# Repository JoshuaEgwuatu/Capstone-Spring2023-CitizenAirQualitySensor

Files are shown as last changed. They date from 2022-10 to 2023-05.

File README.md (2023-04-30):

# Citizen Air Quality Sensor

## Executive Summary

&nbsp;&nbsp;&nbsp;&nbsp;&nbsp;&nbsp; The goal of this project was a replicable device that accepts and operates multiple air quality sensors independently with a selection of interchangeable sensor options for local data collection.  Air quality is vital to maintaining life on Earth.  Poor air quality can result in a slew of health problems such as heart disease and lung cancer.  In the modern age, humanity pushes the levels of pollution in the world to unprecedented levels as compared to the pre-industrial era.  This pollution affects the very air that all living things rely on to survive.  This perspective on the negative repercussions of polluting the air and Earth is what led to this team’s proposition of a device that allows everyday citizens to see what pollutants blight their communities.  
&nbsp;&nbsp;&nbsp;&nbsp;&nbsp;&nbsp; There are already services that exist to alleviate this problem, however, the services do not fulfill the solution to a high degree.  The biggest of these services would be the Air Quality Index (AQI) provided by the United States Environmental Protection Agency.  The AQI takes in data from sensors placed systematically all across the country and in highly populated areas.  This data is then aggregated together to fill in any regions that were not explicitly sampled from a sensor directly.  The issue derives from that last sentence.  Because it is not reasonable or cost-effective for these services to place sensors everywhere, the readings that are received from these sensors may not be accurate in any given place.  For a community wanting a detailed view into the air quality of their chosen area, they would require more concrete sources of data.  It is here where the team’s proposed device comes in to provide an easy-to-use, solar-powered, easily replicable, and low-cost modular system that uses multiple sensors to gather data on different pollutants.

## Capabilities

1. Data Acquisition Through USB Or Wirelessly Through The Internet
2. Modular Sensor Design
3. Optional Self-Powering Modules Using Battery/Solar
4. Dynamically update a Google Sheet with current sensor values

## Salient Outcomes

### Internet Access:

&nbsp;&nbsp;&nbsp;&nbsp;&nbsp;&nbsp;  The original plan for accessing the Internet has remained the same, however, the implementation has changed.  Utilizing 3G GSM would provide national coverage.  The development here was that all major cellular service providers have been phasing out 3G support throughout the year of 2022.  This obviously proved a great concern as the initial design of the Communication subsystem was designed with 3G in mind.  The original design did not allow for anything else.  An upgrade to 4G was necessary and called for an entirely new component.

### Modularity:

&nbsp;&nbsp;&nbsp;&nbsp;&nbsp;&nbsp;  Modularity has been a core design concept from the beginning.  The system design incorporates this philosophy in many aspects and subsystems.  A project with this level of interchangeable parts and optional configurations has never been attempted by members of the team.  The team is eager to see this project flourish and see numerous options covering a wide range of locations and uses.

### Citizen Science 

&nbsp;&nbsp;&nbsp;&nbsp;&nbsp;&nbsp;  Dr. Austen has presented an admirable goal and intriguing future for this project.  His vision has a future where this proposed device is improved by numerous teams and utilized in small communities to spread awareness of air quality concerns and the health risks that can arise from poor conditions.  People and companies use this design as foundation for their own projects.  This team is happy to pursue this vision and see it fulfilled.

## Project Photos and Video

### Original Box Exterior
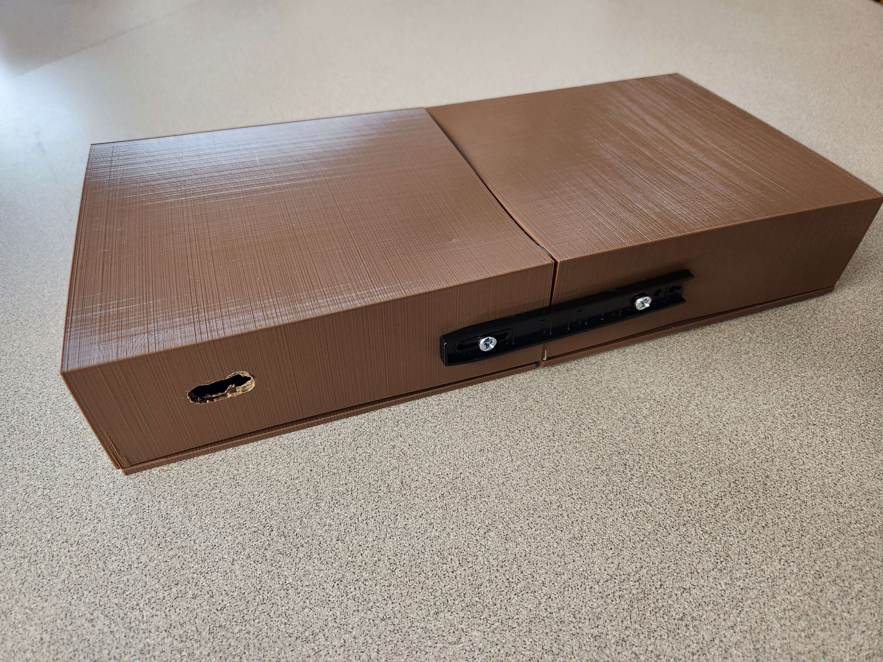
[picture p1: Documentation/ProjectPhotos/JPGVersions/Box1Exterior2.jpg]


### New Box Exterior
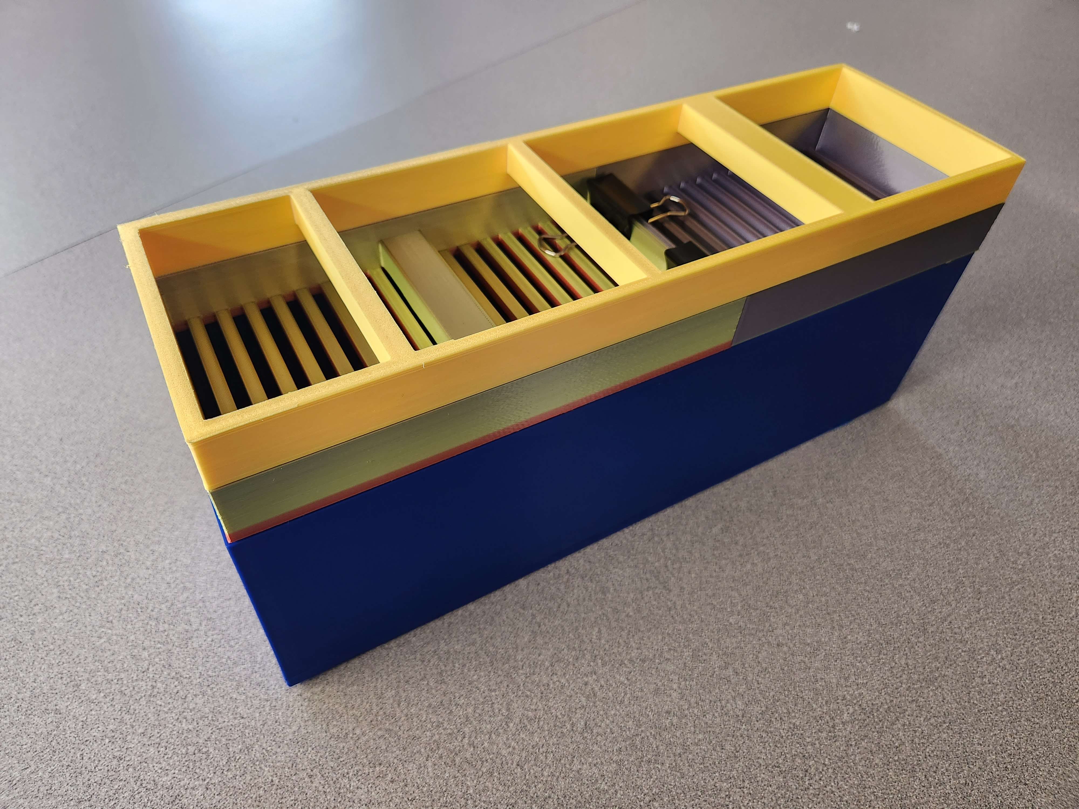
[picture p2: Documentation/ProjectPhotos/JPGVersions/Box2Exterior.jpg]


### Device In Operation Video
[Click Here To Go To YouTube Demonstration](https://youtu.be/Z7YvJpOqsXQ)

## About Us

### Team

&nbsp;&nbsp;&nbsp;&nbsp;&nbsp;&nbsp; All of the members on the team have studied over various circuits and how to implement them to do what the developer wants it to.  Members include: 
Cameron Smith is a computer engineer who is heading the communication subsystem
Kaleb Irwin is an electrical engineer who is designing the power subystem
Alejandro Moore is an electrical engineer in charge of the sensor subystem
Marvo Odds is an electrical engineer managing interfacing between components and sensors
Joshua Egwuatu is an electrical engineer leading the web subsystem.  

### Faculty Supervisor
The supervisor and customer for this project is Dr. Jeffrey Austin.  He is overseeing the design process made by the team and also providing the end-goal desires of the device.

### Stakeholders
The customer for this product is also the same person, Dr. Jeffrey Austin. Another stakeholder within this course is our professor, Mr. Jessie Roberts. The team will be in contact with both professors as we proceed within the design.

## Repo Organization

### Reports
The reports will consist of a Project Proposal, Conceptual Design, Minimal Functionality, Project Poster, and Presentations. Proposal and Design cover analysis and contraints of the system.

### Documentation
Signoffs, Schematics, 3D Models, Images/Photos, and Final Bill of Materials.  Signoffs cover analysis and contraints of individual subsystems.

### Software
The Pseudo Code and other Software components for the project will be placed in Software. Each code directory contains a README that details a description, functions of the code, dependences, and how to install.

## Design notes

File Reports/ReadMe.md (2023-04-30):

This directory will contain the final version of each of the following:
1. [The Project Proposal Original](https://github.com/JoshuaEgwuatu/Capstone-Spring2023-CitizenAirQualitySensor/blob/main/Reports/Project%20Proposal%20Draft%200.pdf)
2. [The Project Proposal Revised](https://github.com/JoshuaEgwuatu/Capstone-Spring2023-CitizenAirQualitySensor/blob/main/Reports/Project%20Proposal%20Revisions.pdf)
3. [Conceptual Design and Planning](https://github.com/JoshuaEgwuatu/Capstone-Spring2023-CitizenAirQualitySensor/blob/main/Reports/Conceptual%20Design%20and%20Planning.pdf)
4. [Project Poster](https://github.com/JoshuaEgwuatu/Capstone-Spring2023-CitizenAirQualitySensor/blob/main/Reports/CT1_Citizen_Air_Quality_Sensor_Poster_S23_V3.pdf)
5. [Minimal Functionality](https://github.com/JoshuaEgwuatu/Capstone-Spring2023-CitizenAirQualitySensor/blob/main/Reports/Minimal%20Functionality%20(1).pdf)
6. [IAB Presentation](https://github.com/JoshuaEgwuatu/Capstone-Spring2023-CitizenAirQualitySensor/blob/main/Reports/Presentations/IAB-Capstone-Team-1-Presentation.pdf)
7. [All Presentations](https://github.com/JoshuaEgwuatu/Capstone-Spring2023-CitizenAirQualitySensor/tree/main/Reports/Presentations)

Final Report may be considered the entirety of this GitHub repository, so a singular document may not be representative of the Final Report

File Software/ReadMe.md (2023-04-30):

This software directory will contain all the code and software utilized.

FinalIteration represents the final version of the code that was able to be tested and prove completely functional.

Each folder will contain the following:

1. What the software does
2. Libraries/Dependecies used (Arduino IDE is a default if not stated otherwise)
3. How to Install

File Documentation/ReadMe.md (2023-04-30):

This folder will contain copies of the final versions of the signoffs.  These signoffs represent the approved designs and purchases made for the overall design.

This folder will also contain general images used throughout various documentation of the project.  The images folder acts as a hoard of all the images.  This includes the project poster and photos of the device under construction and completion.

Any wiring and electrical schematics will be available in the electrical folder in this directory.  Here, there will be PCB and Schematic sections for each component and subsystem.

A final version of the Bill of Materials is included.  This file details all components purchased for constructing the final product.

3D Models contains the most up-to-date version of the enclosure in an STL file.

All signoffs detailing the contraints and analysis for this device's subsystems are available inside this documentation folder.  These signoffs also include small electrical diagrams for constructing the subsystem.

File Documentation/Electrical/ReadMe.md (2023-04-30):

Any wiring and electrical schematics will be available in the electrical folder in this directory. Here, there are Schematic sections for Microcontroller, Sensor, and Interface.  
Communication is just a UART connected to the Arduino.  Check signoff for more detail.
Power subsystem is just a power connection to one of the modular options. Check signoff for more detail.

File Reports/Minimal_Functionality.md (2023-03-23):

# Minimal Functionality
### Capstone Team 1 Members
* Joshua Egwuatu - Web & Wireless
* Kaleb Irwin - Power
* Cameron Smith - Communication
* Alejandro Moore - Sensor
* Marvo Odds - Interface

## POWER
1. Operate using battery power
2. Operate using AC mains power
3. Supply 5 V to the Arduino through a USB input.
4. Supply appropriate voltages to sensors.

## SAMPLING AND INTERFACING SENSORS
1. The sensor will transfer the measured data to the microcontroller via the interface.
2. Sample at a minimum of 2 Hz.

## MICROCONTROLLER
1. Store data onto a USB flash drive.
2. Receive analog voltage, analog current, and digital data from the interface.
3. Send data to the Communication subsystem.

## COMMUNICATION
1. Receive data from the Microcontroller, format the data, and send the data through the use of
Wi-fi to be displayed on a terminal.

## WEB AND WIRELESS
1. Receive data from the device and have a simple display in a numeric form

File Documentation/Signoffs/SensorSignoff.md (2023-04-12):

# Sensor Subsystem Signoff
## FUNCTION OF THE SUBSYSTEM
&nbsp;&nbsp;&nbsp;&nbsp;&nbsp;&nbsp; The Sensor Subsystem will be designed to give various data to the Microcontroller Subsystem through the Interface Subsystem. As data acquisition starts, the output of each analog sensor goes through the Interface for voltage/current regulation to the microcontroller.

&nbsp;&nbsp;&nbsp;&nbsp;&nbsp;&nbsp; Within this Sensor Subsystem, the design team has decided to get multiple types of sensors for the modularity of the device. These types are digital, analog voltage, and analog current sensors. While the digital sensors send bits describing the measurement of a specific parameter, the analog sensors send their signals a bit differently. Analog sensors output analog signals which are different to measure from bits, therefore the Interface Subsystem will provide assistance in parameter conversion to the microcontroller.

## CONSTRAINTS ON THE SUBSYSTEM
&nbsp;&nbsp;&nbsp;&nbsp;&nbsp;&nbsp; Constraints on the subsystem are as follows:

1. The pollutants of the Air Quality Device shall be able to detect carbon dioxide, methane, nitrogen dioxide, ozone, particulate matter, and sulfur dioxide. These sensors should work independently from each other.

Each sensor shall meet the requirements of either Constraint 2 or 3.

2. Shall be modular. Specifically, the change of sensors should be seamless and handled by the board and software. The sensors will have a variety of Input/Output (I/O) ports. For a sensor to be in the same group, it must share the same voltage supply, current consumption, and communication technique through the interface. The sensor shall meet either of the following output ranges [9]:

&nbsp;&nbsp;&nbsp;&nbsp;&nbsp;&nbsp; ● Output the signal at the range of 0 - 10 VDC for analog voltage.

&nbsp;&nbsp;&nbsp;&nbsp;&nbsp;&nbsp; ● Output 4 - 20 mA for analog current.

3. Each sensor must be able to communicate with the microcontroller using a communicative language. The sensors shall communicate through Serial Peripheral Interface (SPI), Universal Asynchronous Receiver-Transmitter (UART), or Inter-Integrated Circuit (I2C). The microcontroller for this design will also be able to communicate with those same data transfer techniques. 

4. For windy environments, the sampling rate should be at most 10 Hz. This is because there are environmental factors that can cause a loss of accuracy in the data given higher wind speeds or non preferable weather conditions. After viewing this experiment of wind analysis in Thailand, it can be shown that using the Nyquist sampling theorem and varied wind speed, one can find the appropriate sampling rate at higher wind speed conditions without losing as much accuracy. They observed the wind speed data and used Fourier Transform to locate a cutoff frequency for the Nyquist sample rate. From their calculations, they have also concluded 10 Hz to be a suitable sample rate for higher wind conditions [1]. For indoor monitoring, ambient gas sensors will be sampled at the lowest rate of 2 Hz per second based on the diffusion of ambient air quality [3].

5. The input voltages from the Power Subsystem will provide either 3 or 5 +/- 0.1 V DC. Therefore, each sensor that will be used for the device shall have input voltages of either value. From looking at multiple gas sensors for this project, the maximum worst case for wattage in this subsystem is 375 mW. Maximum current consumption for each sensor is 75 mA.

6. For every sensor that is plugged onto the Air Quality Device initially, there may be a start up time for initial calibration. According to a study in Tokyo, most portable gas sensors have a start-up time of 30s [10]. After a survey observing the full start-up time range, the sensors selected within the analysis section have a max time of 1 hour. Therefore, all sensors shall have a wait/warm-up time less than 2 hours before data acquisition.

7. According to the ANSI/ASHRAE Standard 62.1-2016: Ventilation for Acceptable Indoor Air Quality [2], indoor CO2 concentrations no greater than 700 parts per million (ppm) above outdoor CO2 concentrations will satisfy a substantial majority (about 80%) of occupants. Sensors used for this device shall comply with their pollutant concentration with this standard for indoor/outdoor use. The NAAQS has revised measurement standards for the main pollutants in America. The ranges are as follows [14]:

&nbsp;&nbsp;&nbsp;&nbsp;&nbsp;&nbsp; ● PM 10 - 150 - 350 μg/m3 (micrograms per cubic meter of air. Resolution not found

&nbsp;&nbsp;&nbsp;&nbsp;&nbsp;&nbsp; ● PM 2.5 - From 12 - 200 μg/m3. Resolution not found

&nbsp;&nbsp;&nbsp;&nbsp;&nbsp;&nbsp; ● NO2 - From 53 - 100 ppb (parts per billion). Resolution not found

&nbsp;&nbsp;&nbsp;&nbsp;&nbsp;&nbsp; ● O3 - From 0.07 - 0.115 ppm. Resolution not found

&nbsp;&nbsp;&nbsp;&nbsp;&nbsp;&nbsp; ● SO2 - From 0.5 - 2 ppm. 1 ppb Resolution.

&nbsp;&nbsp;&nbsp;&nbsp;&nbsp;&nbsp; ● CH4 (Methane) - From 2 - 90 ppm [15]. Resolution not found

## BUILDABLES OF THE SUBSYSTEM

CAPSTONE II Sensor Subsystem
&nbsp;&nbsp;&nbsp;&nbsp;&nbsp;&nbsp; &nbsp;&nbsp;&nbsp;&nbsp;&nbsp;&nbsp; &nbsp;&nbsp;&nbsp;&nbsp;&nbsp;&nbsp; &nbsp;&nbsp;&nbsp;&nbsp;&nbsp;&nbsp; &nbsp;&nbsp;&nbsp;&nbsp;&nbsp;&nbsp; &nbsp;&nbsp;&nbsp;&nbsp;&nbsp;&nbsp; &nbsp;&nbsp;&nbsp;&nbsp;&nbsp;&nbsp; &nbsp;&nbsp;&nbsp;&nbsp;&nbsp;&nbsp; &nbsp;&nbsp;&nbsp;&nbsp;&nbsp;&nbsp; Figure 1. Sensor Subsystem through Interface Schematic

Screenshot (229)

&nbsp;&nbsp;&nbsp;&nbsp;&nbsp;&nbsp; &nbsp;&nbsp;&nbsp;&nbsp;&nbsp;&nbsp; &nbsp;&nbsp;&nbsp;&nbsp;&nbsp;&nbsp; &nbsp;&nbsp;&nbsp;&nbsp;&nbsp;&nbsp; &nbsp;&nbsp;&nbsp;&nbsp;&nbsp;&nbsp; &nbsp;&nbsp;&nbsp;&nbsp;&nbsp;&nbsp; &nbsp;&nbsp;&nbsp;&nbsp;&nbsp;&nbsp; &nbsp;&nbsp;&nbsp;&nbsp;&nbsp;&nbsp; &nbsp;&nbsp;&nbsp;&nbsp;&nbsp;&nbsp; Figure 2. Sample code for the MIKROE-2767

Screenshot (231)

&nbsp;&nbsp;&nbsp;&nbsp;&nbsp;&nbsp; &nbsp;&nbsp;&nbsp;&nbsp;&nbsp;&nbsp; &nbsp;&nbsp;&nbsp;&nbsp;&nbsp;&nbsp; &nbsp;&nbsp;&nbsp;&nbsp;&nbsp;&nbsp; &nbsp;&nbsp;&nbsp;&nbsp;&nbsp;&nbsp; &nbsp;&nbsp;&nbsp;&nbsp;&nbsp;&nbsp; &nbsp;&nbsp;&nbsp;&nbsp;&nbsp;&nbsp; &nbsp;&nbsp;&nbsp;&nbsp;&nbsp;&nbsp; &nbsp;&nbsp;&nbsp;&nbsp;&nbsp;&nbsp; Figure 3. Sample Code for the A02P43B7001

## ANALYSIS OF THE SUBSYSTEM

&nbsp;&nbsp;&nbsp;&nbsp;&nbsp;&nbsp; The team has chosen 3 sensors for testing that matches with the constraints list. We wanted each to be a different type of sensor output to test modularity and implement the necessary actions required within the software to model the functionality of both the Microcontroller, Interface, and Sensor Subsystems. All sensors chosen for experimentation are for detecting one of the 6 pollutants that the proposal has stated for data input.

### OZONE SENSOR (ANALOG VOLTAGE)

#### Analysis of the MIKROE-2767 [4]:

1.& 7.-The MIKROE-2767 Ozone (O3) Gas Sensor is a quarter-sized PCB mounted with a MQ131 detector that has high sensitivity depending on the potentiometer. This sensor is able to detect the pollutant anywhere from 10‐1000 Part-Per-Million (ppm). Resolution not stated within the data sheet.

2.& 5.-The MIKROE-2767 has an input voltage range of 3.3V - 5V therefore, this particular sensor can be powered by both voltage supply options. Based on the Schematic (Schematic Reference!), the current computation is in the range of 5 uA - 33 uA.

4.-Not Applicable.

6.-Not Applicable.

Other - The UART source code can be seen in the Buildables of the Subsystem section within the document. (See Figure 2.)

### SULFUR DIOXIDE SENSOR (ANALOG CURRENT)

#### Analysis of the ULPSM-IAQ 968-008 [6] with the A02P43B7001 [5]:

1.-The A02P43B7001 gas detector is able to detect Sulfur Dioxide (SO2) which is within the list of pollutants to be acquired.

2.-The ULPSM-IAQ 968-008 below the detector contains a nice feature of having the ability to switch the gas detectors for other pollutants as well. This can allow the user to replace the SO2 sensor with another pollutant detector, or a different type of gas detector for more convenience and modularity.

4.-Not Applicable.

5.-The ULPSM-IAQ 968-008 will be connected using header pins under the A02P43B7001, which will communicate with the Microcontroller. The ULPSM-IAQ 968-008 calls for a supply voltage of around 3.3V. The power consumption is on average 30 uW. Also, the corresponding current consumption is 10uA on average.

5.-The A02P43B7001 will operate at the same voltage supply of 3.3V with an LED indicator telling the user that the sensor is operating in the ON position. During this time, the SO2 sensor has a max operating current of 1.17 mA and a max power consumption of 3.7 mW.

6.-Not Applicable.

7.-The analog current detector has a measurement range of 0 - 5 ppm. Having a wide range will give the user a range of accuracy and levels of precise calculations.  Resolution found to be 0.15 ppm for the ULPSM-IAQ 968-008. The A02P43B7001 states in the datasheet a resolution of 1 ppb.

Other - A method sample code for the SO2 detector to communicate with the Master device can be seen within the Buildables of the Subsystem section. (See Figure 3.)

### CARBON DIOXIDE SENSOR (DIGITAL)

#### Analysis of the DGS-CO 968-034 [7]:

1.-The DGS-CO is a digital carbon monoxide detector that has a similar modular feature as the analog current gas sensor. This means we can switch detectors for experimentation on whether the components meet our specifications.

3.-The connections are configured by the PCB to communicate using UART as well.

4.-Not Applicable.

5.-The supply voltage is available for a 3.3V supply with a power gumption range of 0.15 - 12 mW. The current consumption also has a range of 0.05 mA - 4 mA. Values for the power, voltage, and current requirements depend on the operating periodic functions of this device.

6.-Not Applicable.

7.-This Digital sensor has a range of 0 -1,000 ppm. The DGS-CO has a resolution of 0.1 ppm.

### METHANE SENSOR (ANALOG VOLTAGE)

#### Analysis of the MIKROE-1628 [11]:

1.-The MIKROE-1628 is able to detect methane within its location.

2.& 5.-It can be supplied with a max voltage of 5V, a max current consumption of 33 uA, outputting at a range of 0 - 5 V.

4.& 6.-After a warm up time of 1 hour, it can start sampling at a rate of 2Hz.

7.-Has a measurement rage of 200 - 10000 ppm. Resolution was not found within the datasheet.

### NITROGEN DIOXIDE SENSOR (DIGITAL)

#### Analysis of the SEN0377 [12]:

1.-The SEN0377 can detect various type of gasses, but for this device it shall be used to detect NO2.

3.-The sensor shall communicate using I2C for the microcontroller.

4.& 6.-Start up time is less than 1 hour with a sample rate of 5 Hz.

5.-This sensor has the modular compatibility to take either 3.3 or 5 V supply with a low current consumption of 11 mA. Thus having a lower power intake of .45 W. Digital output of 0 - 3 V.

7.-Measurement range of 0.05 - 10 ppm. Resolution was not found within the datasheet.

### PARTICULATE MATTER SENSOR (DIGITAL)

#### Analysis of the SPS30 [13]:

1.-This Particulate Matter (PM) Sensor can detect 4 different sizes of PM in its location.

3.-Uses both I2C and UART to communicate.

4.-Samples at a period of 1 second or 2 Hz.

5.-Supply voltage is 5V with max current intake of 75 mA. Outputs current of 0 - 16 mA.

6.-Start up time ranges from 8 - 30 seconds.

7.-Can calibrate up to ranges of 200 - 3000 ppm. Resolution not found within the datasheet.

### GPS SENSOR (DIGITAL)

&nbsp;&nbsp;&nbsp;&nbsp;&nbsp;&nbsp; Another sensor to be applied in the project is used for GPS location. The RAK1910 [8] can do this task while also corresponding to the constraints provided.

1.-Not Applicable.

3.-The GPS sensor can communicate using UART or I2C, being compatible with the microcontroller in use.

4.-Not Applicable.

5.-The RAK1910 can take 3.3V with low amperage consumption. The worst case being 22 mA.

6.-30 second cold start-up time.

7.-Not Applicable.

## BILL OF MATERIALS

|Item Name|Manufactured Part #|Quantity|Description|Price|
|---|---|---|---|-----|
|OZONE 2 CLICK|MIKROE-2767|0|Analog Voltage O3 Gas Sensor|$45.00|
|Analog Gas Sensor Module|ULPSM-IAQ 968-008|1|Analog Current Gas Sensor (Modular with Digital Sesnor)|$50.00|
|Allsensing gas sensor module|A02P43B7001|1|SO2 GAS SENSOR|$163.62|
|WisBlock GNSS Location Module|RAK1910|0|Tracks the GPS and the GLONASS signals|$17.00|
|Digital Gas Sensor Module|DGS-CO 968-034|0|Digital Gas Sesnor (Modular with Analog Current Sensor) if out of stock, 968-001 is similar option.|$50.00|
|Methane Click|MIKROE-1628|1|Multiple Function Sensor|$15.00|
|Digital Sensor Module|SEN0377|1|Multiple Function Gas Sensor|$39.90|
|Particulate Matter Sensor|SPS30|0|Particulate Matter Sensor for Air Quality Monitoring and Control|$50.50|

Note: All sensors that our team does not plan to order will have the quantity order number of 0 within the BOM. Corresponding sensors that have the quantity number of 0 will be ordered at a later date separate from the initial build.

## REFERENCES

1. “Improving Accuracy of Wind Analysis with Multiple Sampling Rates of Wind Measurement” https://www.e3s-conferences.org/articles/e3sconf/pdf/2019/21/e3sconf_icpeme2018_02002.pdf (Accessed on 3-1-23).

2. The National Institute for Occupational Safety and Health (NIOSH) “Indoor Environmental Quality” https://www.cdc.gov/niosh/topics/indoorenv/hvac.html (Accessed on 2-16-23).

3. Lion Precision “Displacement Resolution Specifications and Its Effects on Performance” https://www.lionprecision.com/understanding-sensor-resolution-specifications-and-effects-on-performance/ (Accessed on 2-23-23).

4. MIKROE-2767 Datasheet “Ozone 2 click” https://media.digikey.com/pdf/Data%20Sheets/MikroElektronika%20PDFs/MIKROE-2767_Web.pdf (Accessed on 2-13-23).

5. A02P43B7001 Datasheet https://media.digikey.com/pdf/Data%20Sheets/Allsensing%20PDFs/AGSM-SO2-5.pdf (Accessed on 2-16-23).

6. ULPSM-IAQ 968-008 Datasheet “Ultra-Low Power Analog Sensor Module for IAQ” https://www.spec-sensors.com/wp-content/uploads/2016/10/ULPSM-IAQ-968-008.pdf (Accessed on 2-16-23).

7. DGS-CO 968-034 Datasheet “Digital Gas Sensor – Carbon Monoxide” https://www.spec-sensors.com/wp-content/uploads/2017/01/DGS-CO-968-034.pdf (Accessed on 2-16-23).

8. RAK1910 WisBlock GNSS Location Module Datasheet https://docs.rakwireless.com/Product-Categories/WisBlock/RAK1910/Datasheet/#overview (Accessed on 2-17-23).

9. GasLab “Analog and Digital Gas Sensors: What’s the Difference?” https://gaslab.com/blogs/articles/what-s-difference-between-analog-digital-gas-sensors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,or%200%2D3%20volts%20DC. (Accessed on 2-20-23).

10. Stable Heating Technology for Catalytic Combustion Hydrogen Gas Sensor Using Quartz Resonators https://pdfs.semanticscholar.org/7a13/0c740245fd18929fdc9169a5f38154c9cf0e.pdf (Accessed on 2-23-23).

11. MIKROE-1628 Datasheet https://www.mouser.com/datasheet/2/272/methane-click-manual-v100-1483826.pdf (Accessed on 2-23-23).

12. SEN0377 Datasheet https://www.mouser.com/pdfDocs/ProductOverview-DFRobot-SEN0377.pdf (Accessed on 2-23-23).

13. SPS30 Datasheet https://cdn.sparkfun.com/assets/4/e/e/f/8/Sensirion_PM_Sensors_Datasheet_SPS30.pdf (Accessed on 2-23-23).

14. United States Environmental Protection Agency “NAAQS Table” https://www.epa.gov/criteria-air-pollutants/naaqs-table (Accessed on 2-26-23).

15. “A Portable Device for Methane Measurement Using a Low-Cost Semiconductor Sensor: Development, Calibration and Environmental Applications” https://www.mdpi.com/1424-8220/21/22/7456#:~:text=This%20sensor%20can%20perform%20temperature,RH%20and%20resolution%20of%200.01%25 (Accessed on 2-26-23).

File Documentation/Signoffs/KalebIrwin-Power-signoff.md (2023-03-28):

## Function of the subsystem 
The subsystem will provide the microcontroller and sensor interface with power. There will be two configurations designed which the user will be able to choose from. The first configuration will be designed to operate with input from an ac mains electrical outlet and the second configuration will be powered by a battery that is charged by a solar cell.

## Constraints 
1. *Provide a maximum power draw of 1.686 W and 0.831 W typical 
   
   a. Arduino Mega maximum power is 0.9 W taken from 5 V operation at 180 mA peak current draw with 0.375 W typical power requirements taken from 5 V 75 mA typical operation [1]
   
   b. ESP8266 maximum power draw is 0.561 W taken from 170 mA maximum required current at 3.3 V operation [2]
   Typical power draw for ESP8266 is 0.231 W taken from 3.3 V 70 mA typical operation [3]
   
   c. The largest power draw observed in evaluated sensors was 75 mW. Accoutning for three of these peak power draw sensors yeilds 225 mW.
2. Power the Ardunio Mega with 7-12 V 160 mA on the Vin pin or 5±0.25 V 200mA from the USB 2.0 standard through the USB 2.0 input on the board [4][5]
3. **Provide 45 mA at 5 V and 75 mA at 3 V for sensor interface (This supports the three peak power draw sensors)

Additional constraint on system for AC operation

 4. Function on 120 V 60 Hz AC mains input and must have UL certification 

Additional constraints on system for battery operation

5. Battery capacity greater than 39.89 Wh to allow for a minimum operational time of 48 hours on a single charge without additional power from a solar cell 
   
      Calculated with (typical power draw * minimum continuous operation time) = (0.831 W * 48 h) = 39.89 Wh 
   
 6. Must use a solar panel that is at least 4.43 W in order to recharge the batteries daily power consumption within the peak solar hours timeframe of 4.5 hours [6]. 
 
      Calculated with (typical daily power usage / average peak sun hours) = (19.94 Wh / 4.5 h) = 4.43 W

## Schematic 



## Analysis 
1. The chosen wall adapter is rated at 5 V and 2 A. Multiplying these numbers yields 10 W. The chosen battery has USB output of 5 V and 3 A. Multiplying these numbers yields 15 W both of which are greater than the worst case power draw of 1.686 W
2. Both solutions provide 5 V USB output that can power the Arduino 
3. 5V can be taken directly from the USB-A to the screw terminal on either power option and sent to the interface. It can also be connected to the input terminal on the DC-DC converter to provide the 3 V.
   
   a. The chosen DC-DC converter requires an input voltage at least 1.5 V higher than the output voltage and can input 4-40 V and output 1.5-35 V. These ranges allow for a 5 V input and a 3 V output.

4. The chosen wall adapter is rated for 100-240 V 50/60 Hz AC which covers the US electrical system and shows UL certification.
5. The chosen battery has a stated capacity of 25000 mAh and uses an internal battery voltage of 3.7 V for a power capacity of 92.5 Wh. Using this and the typical power draw of 0.831 W tells us that it will run for 111.31 hours on a single charge with no additional power from the solar cell. This is 2.319x the minimum operation time. 
6. Built in solar cell can provide 6 W during peak sun hours

   Gaining 6 W * 4.5 h = 27 Wh given 4.5 hours of peak sun which is greater than the 19.988 Wh daily usage.

## BOM
| Designator | Manufacturer | Manufactured Part # | Description | Quanitity | Price Each |
| --- | --- | --- | --- | --- | --- |
| P1 | Hiluckey | | Solar Charger 25000 mAh | 1 | $46.99 |
| P2 | ALMOCN | | DC-DC Adjustable Step-Down Module with Digital Display Voltmeter Display 2 pack | 1 | $8.99 |
| P3 | Fonken | | 5 V 2 A wall charger 3 pack | 1 | $11.99 |
| P4 | Itramax | | USB male to two female adapter | 1 | $12.99 |
| P5 | JUXINICE | | Male USB to screw terminal connector 2 pack | 1 | $8.99  
| *** | SANKABA | 000010 | 5 W USB Solar Panel for DC 5V Security Camera. | 0 | $23.99 
## Notes 
*Maximum and typical power calculations done with no low power modes or code taken into account. For actual operation these values can be lowered substainually and should be considered to lower the load on the battery. For this project we will attempt to include as many options as possible and provide data on power consumption with and without these features.

**Additional constraint placed on power subsystem if the chosen sensors exceed the Arduino Mega 50 mA current limit. If the sensors do not exceed the current limitations of the Arduino Mega and its' pins, the DC-DC converters may be ommited from the design as the sensors can use the 3.3 V and 5 V supplies on the board. 

***An additioanl solar cell can be purchased in the event that the solution presented is not suffecent for a users area. This additional panel must have micro-USB output as it will need to be pluged into the power in port of the battery.  
## Reference 
1. C. David, “Arduino mega tutorial [pinout],” DIYI0T, 07-May-2021. [Online]. Available: https://diyi0t.com/arduino-mega-tutorial/. [Accessed: 07-Feb-2023]. 
2. “ESP8266EX datasheet - espressif,” ESP8266 Datasheet. [Online]. Available: https://www.espressif.com/sites/default/files/documentation/0a-esp8266ex_datasheet_en.pdf. [Accessed: 08-Feb-2023]. 
3. C. David, “How to reduce the ESP8266 power consumption?,” DIYI0T, 07-May-2021. [Online]. Available: https://diyi0t.com/how-to-reduce-the-esp8266-power-consumption/. [Accessed: 07-Feb-2023]. 
4. T. A. Team, “MEGA 2560 REV3: Arduino documentation,” Arduino Documentation | Arduino Documentation. [Online]. Available: https://docs.arduino.cc/hardware/mega-2560. [Accessed: 07-Feb-2023]. 
5. USB-IF,“USB 2.0 specification,” USB, 08-Oct-2021. [Online]. Available: https://www.usb.org/document-library/usb-20-specification. [Accessed: 07-Feb-2023]. 
6. Unbound Solar , “Sun hours map: How many sun hours do you get?,” 09-Mar-2021. [Online]. Available: https://unboundsolar.com/solar-information/sun-hours-us-map. [Accessed: 08-Feb-2023].

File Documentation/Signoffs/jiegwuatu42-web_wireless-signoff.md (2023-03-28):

# Web and Wireless Signoff
## FUNCTION OF THE SUBSYSTEM

The Web & Wireless subsystem is responsible for receiving data from the Communication subsystem, storing data received from the Communication subsystem on a host device, formatting and encrypting the data, and displaying the data for the user on a webpage.

## CONSTRAINTS ON THE SUBSYSTEM

The subsystem constraints are placed to ensure that it can fulfill its job in a satisfactory manner. Constraints on the subsystem are as follows:
1. The server must be able to communicate with the measurement system (communication subsystem).
2. The server must have adequate storage for user data. 
    - This storage is based on the number of sensors used at once (3 max). [1] The current goal is to hold data collected for a month. At this time, 1 GB of ram is required. A chart will be provided to show if the user chooses to use a different option. 
The equation used: 10 Hz (worst case sampling rate) * 2 bytes per 10 bit sample = 20 bytes per second. 20 bytes per second / 1.0486 * 10^6 (convert to megabytes) = 20 * 1.0486 * 10^-6 megabytes. 20 * 1.0486 * 10^-6 * 1 month = 32.8536 megabytes per month. 32.8536 megabytes per month * 3 (sensors in microcontroller at one time) = 50.16  megabytes per month.

Chart Displaying Possibilities:

|Required Space for Server (Megabytes per month)| | | | |
|:----|:----|:----|:----|:----|
| | |Data Size| | |
|Sensors left in the field| |8 Bit sampling|10 bit sampling|16 bit sampling|
|1 Month| |25.08 megabytes|50.16 megabytes|50.16 megabytes|
|3 Months| |75.24 megabytes|150.47 megabytes|150.47 megabytes|
|6 Months| |150.47 megabytes|300.95 megabytes|300.95 megabytes|
|1 Year| |300.95 megabytes|601.9 megabytes|601.9 megabytes|

3. The data will be encrypted and decrypted using TLS Encryption. 
   - The encryption/decryption will happen at two different times: [2] [5] [6]
     - Communication to Server
       - Communication references devices used to connect microcontroller to internet:
         - 4G LTE
         - Wi-Fi  
     - Server to User
4. The server must be accessible via the Internet.
5. The data received must be displayed in a user friendly format. 
    - User Interface will be a webpage.
    - User Interface will use Graphical Interface.
    - User Interface falls in line with W3C Standards. [7]

## BUILDABLE SCHEMATIC OF SUBSYSTEM

Server Flow Chart

Server will host a html website. Will be made using program languages C, Python, and Go

## ANALYSIS OF CHOSEN COMPONENT(S)

1. The pre-built server the team selected is Cherokee. It is a high-performance web server that is fast, flexible, and easy to configure. The server meets project constraints. [6]

Cherokee Data/Specifications: 
- Minimum Laptop Requirements:
  - CPU Speed: 133Mhz
  - System Programs: sh shell, make and an ANSI C compiler
- Coding language: Python
  - Easy to use
- Supports OpenSSL backend
  - TLS library that secures data
- User Interface
  - Extremely friendly user interface (UI)
  - Uses graphical interface
- License
  - GNU General Public License v2.0 [8]
    - Free Software
        - Accessable Source Code
        - Ability to share software
        - Ability to alter software
        - Software is free for all users
    - This allows for modularity of software

## BILL OF MATERIALS (BOM)

| Designator | Manufacturer | Manufactured Part # | Description | Quantity | Price Each |
| --- | ---  | --- | --- | --- | --- |
| S1 | Cherokee Project | Cherokee | Web Server | 1 | $0 |
| S2 | Any | Computer/Laptop | Hardware to run/host server. Almost all owned computers/laptops meet system requirements.  | 1 | $NA |

Notes: 

For more info on web server: https://cherokee-project.com/

Hardware Specs for Computer/Laptop: (Most

- CPU Speed: 133Mhz
- RAM: 1 GB
- System Programs: sh shell, make and an ANSI C compiler

** All software packages are included in the web server.

## References

1. Datasheet SPS30 Particulate Matter Sensor for Air Quality Monitoring and Control.” https://cdn.sparkfun.com/assets/4/e/e/f/8/Sensirion_PM_Sensors_Datasheet_SPS30.pdf (Accessed on 2-23-23).

2. Amazon.com: Customer reviews: HiLetgo 1PC ESP8266 NodeMCU CP2102 ESP-12E Development Board Open Source Serial Module Works Great for Arduino IDE/Micropython (Small),” www.amazon.com. https://www.amazon.com/HiLetgo-Internet-Development-Wireless-Micropython/product-reviews/B010O1G1ES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 (accessed Feb. 23, 2023).
‌
3. nodemcu, “nodemcu/nodemcu-firmware,” GitHub, Apr. 04, 2019. https://github.com/nodemcu/nodemcu-firmware (accessed Feb. 23, 2023).

4. Admin, “SIM7600 4G GSM with Arduino | AT Commands, Call, SMS,” How To Electronics, Jan. 20, 2022. https://how2electronics.com/using-sim7600-4g-gsm-with-arduino-at-commands-call-sms/ (accessed Feb. 23, 2023)
‌
5. “Maduino Zero 4G LTE(SIM7600X),” Makerfabs. https://www.makerfabs.com/maduino-zero-4g-lte-sim7600.html (accessed Feb. 23, 2023).

6. “Cherokee Web Server | Home,” cherokee-project.com. https://cherokee-project.com/ (accessed Feb. 24, 2023).

7. “About W3C Standards,” W3.org, 2010. https://www.w3.org/standards/about.html (accessed Feb. 24, 2023).

8. “gnu.org,” www.gnu.org. https://www.gnu.org/licenses/old-licenses/gpl-2.0.en.html (accessed Mar. 03, 2023).
‌
‌
‌

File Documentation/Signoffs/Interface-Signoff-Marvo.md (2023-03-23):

# Interface Signoff

## Subsystem Function
The interface conditions a chosen set of analog voltage and analog current output ranges coming from the sensor subsystem to be within the 0 V to 5 V or 1 V to 5 V range then outputs these conditioned signals to the microcontroller. Digital signals do not connect with the interface but instead go straight to the microcontroller.  

## Subsystem Constraints
1) Must scale the following sensor output voltage signal ranges to 0 V to 5 V: 0 V to 3 V,  0 V to 10 V,  -10 V to +10 V,  -5 V to +5 V.     
2) Must convert a sensor output current signal of 4 to 20 mA to a voltage signal of 1 to 5 V.
3) Components must be RoHS compliant to prevent health and environment risks due to electronic waste.
4) Interface must not draw any more current than the power system can provide ( 3 A ) and operate off of 5±0.25 V from the power system.

## System Schematic

interface mark 5 schematic

## Analysis

1) Voltage Scaling
* An input voltage range 0 V to 3 V is scaled to 0-5 V through the use of an non-inverting amplifier with a gain of 5/3. The gain formula for a non-inverting op amp is 1 + (R2/R1) and if R1 is set to 3.3k then R2 needs to be 2.2k to acquire a gain of 5/3. The input voltage range is ran through the op amp which multiplies the voltage by the gain. This scales up the original range to the desired range of 0 V to 5 V. 0 V x 5/3 = 0 V and 3 V x 5/3 = 5 V now making a 0 V to 3 V signal map into 0 V to 5 V. R2 should be kept in the kiloohm range to limit current going into the op amp. With R2 being 3.3k, the current entering the op amp according to the LTSpice simulation is around 0.8 mA. which is below the op07 short circuit current of 30 mA. Even if R2 is ±5% of its' nominal value of 3.3k, current entering the op amp according to the LTSpice simulation is around 0.7 mA. which is still below the op07 short circuit current.
* Gain due to Component Variations: Taking resistor tolerances into account, gain of the circuit ranges from 2.35 to 2.66. This gives a percent error of around 6% for the op amp gain.
* Offset Voltage due to Component Variations: Voff due to input offset is calculated with the equation (1+R2/R1) x input offset voltage. Voff due to input offset current is calculated by R2 x input offset current. According to the op07 datasheet, input offset voltage and input offset current are 75 uV max and 3.8 nA max respectively. Substituting these values into the previous equations along with our resistor values of R1 = 3300 and R2 = 2200, we get a total offset voltage of 0.125 mV which is between our acceptable offset output range of 0 mV to 20 mV. Taking into account resistor tolerances, the new range for total offset voltage is between 0.12 mV to 0.14 mV which is still within our acceptable offset range of 0 mV to 20 mV.
* Component Variations & Noise Analysis for 0 V to 3 V to 0 V to 5 V Circuit: Each resistor tolerance and voltage tolerance for the op amp power supply is ±5%. Taking these tolerances and potential power supply voltage noise into account, a LTSpice worse cast analysis simulation was performed for the input voltages 0 V and 3 V respectively. When a 0 volt signal from the sensors is applied as an input to the circuit, the output voltage due to tolerances and noise will be in the range of 925.26 mV to 926.10 mV. When a 3 V signal is applied as an input, the output range will be between 3.40 V to 4.80 V. Due to component tolerances, output voltages will not be perfectly 0 or 5 volts. As a result, data loss of the sensor input voltage signals through the circuit should be expected.  

Effects of Noise and Component Variations Circuit 1

* A 0 V to 10 V range will be scaled down to 0 V to 5 V by way of voltage division. The formula for voltage division is Vout = ( R2 x Vin ) / ( R1 + R2 ). If we set both resistor values to 10k then vout will equal half of the input voltage. (10k x 0 V) / (10k + 10k) = 0 V and (10k x 10 V) / (10k + 10k) = 5 V. The 0-10 V range is now scaled down to a 0 V to 5 V range now measurable by the arduino. Using ohm's law, 10 V / (10k + 10k),  the current going through the voltage divider is .5 mA. Using the power formula, 10 V x .5 mA, the power dissipated by each resistor is 5 mW. The chosen resistors are  ¼ W resistors so power dissipation and overheating will not become a problem. 
* Component Variations for 0 V to 10 V to 0 V to 5 V Circuit:  Each resistor tolerance is 5%. Taking this into account, a ltspice worse cast analysis simulation was performed for for the input voltages 0 V and 10 V. When a 0 volt signal from the sensors is applied as an input to the circuit, according to ltspice the output voltage with tolerances accounted for will be 0 V. When a 10 V signal is applied as an input, the output range will be between 4.80 V to 5.28 V. Due to component tolerances, the output voltage will experience small amounts of voltage loss or overvoltage by .28 V. However, the arduino megas analog pins can handle voltages at Vcc + 0.5 V rendering this potential scenario a non issue. 

WORST CASE ANALYSIS FOR CIRCUIT 2

* To accurately map our chosen negative voltage ranges, a set of equations and steps are used to pick the right resistor values for our three resistor voltage converter circuit. Step 1: Delta Vin = Sensor output range and Delta Vout =  A/D input range. Step 2: Ax = Delta Vin /  Delta Vout, Bx = Vbias / (Vout Vin/A ), and Cx = Ax * Bx / (Ax * Bx - Ax - Bx ). Step 2: RA and Vbias will be kept constant at 10k and 5 volts respectively. RA = (10K / Ax ) * Ax  = 10K. RB = (10k / Ax ) * Bx. RC = (10k / Ax ) * Cx. If input range is -10-10 V and these equations are followed, the values of resistor A,B and C would be 10k,5k, and 10k respectively to map the input range to 0 V to 5 V. If input range was -5 V to +5 V, using these equations would give us RA = 10k, RB = 10k and RC would be disconnected to map -5 V to +5 V to 0 V to 5 V. 
* Component Variations & Noise Analysis for -5 V to 5 V to 0 V to 5 V Circuit: Each resistor tolerance and voltage tolerance for the op amp power supply is ±5%. Taking these tolerances and potential power supply voltage noise into account, a LTSpice worse cast analysis simulation was performed for the input voltages 0 V and 10 V. When a -5 volt signal from the sensors is applied as an input to the circuit, the output voltage due to tolerances will be in the range of -450 mV to +450 mV which is still within the arduinos minimum analog pin voltage range of -0.5 V. When a + 5 V signal is applied as an input, the output range will be between 4.65 V to 5.32 V which is within the arduinos maximum analog voltage pin range of Vcc + 0.5 V. As before, data loss due to these tolerances should be expected.

Effects of Noise and Component Variations Circuit 4 (-5 to 5 V)

* Component Variations & Noise Analysis for -10 V to 10 V to 0 V to 5 V Circuit: Each resistor tolerance and voltage tolerance for the op amp power supply is ±5%. Taking these tolerances and potential power supply voltage noise into account, a LTSpice worse cast analysis simulation was performed for the input voltages 0 V and 10 V. When a -10 volt signal from the sensors is applied as an input to the circuit, the output voltage due to tolerances will be in the range of -480 mV to +510 mV which is still within the arduinos minimum analog pin voltage range of -0.5 V. When a +10 V signal is applied as an input, the output range will be between 4.56 V to 5.36 V which is within the arduinos maximum analog voltage pin range of Vcc + 0.5 V.

Effects of Noise and Component Variations Circuit 4 (-10 to 10 V)

2) Current to Voltage Converter
* The current to voltage converter is a 1000 ohm resistor in parallel with a 330 ohm resistor to form a 250 ohm resistor in series with the current source input. The resistor will convert a 4 mA to 20 mA range to a 1 V to 5 V output. 4 mA * 250 ohms = 1 volt and 20 mA * 250 ohms = 5 volts. With a current of 20 mA and a produced voltage of 5 V the power dissipated would be .1 W. This is lower than our ¼ W resistor which gets rid of power dissipation concerns.
* Component Variations for 4 mA to 20 mA to 0 V to 5 V Circuit: Each resistor tolerance is 5%. Taking this into account, a ltspice worse cast analysis simulation was performed for for the input currents 4 mA to 20 mA. When a 4 mA signal from the sensors is applied as an input to the circuit, the output voltage due to tolerances will be in the range of -250 mV to +260 mV. When a 20 mA signal is applied as an input, the output range will be between 4.87 V to 5.3 V. Due to component tolerances, output voltages can be -250 mV which is within the arduinos minimum voltage range or output voltage can be .30 V over 5 V which is still within the max voltage range.

3) RoHS Compliance
* The chosen resistors and OP07 op amp have been found on Digikey and are listed as RoHS compliant.  

4) 
* As shown in the schematic, the only  two circuits in the interface that draw power are the op amp and the three resistor circuit which are both being supplied 5 V from the power system. The op amp power consumption with a 5 volt power supply is about 50 mW as stated in the datasheet. Taking the 5 volt power supply and dividing by the 50 mW power draw of the op07 you get a current draw of 10 mA. The other circuit that draws power is the negative voltage to 0 V to 5 V converter, perfoming nodal analysis on said circuit comes out to about 1 mA. Therfore total current draw of the interface is about 11 mA which is below the max current being provided to the interface. 

## BOM

| Designator | Manufacturer | Manufactured Part # | Description | Quantity | Price |
|--- |--- |---|---|---|---|
| P1 | Stackpole Electronics Inc |CF14JT10K0 | RES 10K OHM 5% 1/4W | 2 | $0.00729 |
| P2 | Stackpole Electronics Inc |RNF14BTE5K00 | RES 5K OHM 0.1% 1/4W | 1 | $0.13965 |
| P3 | Lumimax Optoelectronic Technology  | CF1/4W3K3JTB | RES 3.3K OHM 5% 1/4W | 1 | $0.01144 |
| P4 | Stackpole Electronics Inc | CF14JT2K20 | RES 2.2K OHM 5% 1/4W | 1 | $0.1 |
| P5 | Stackpole Electronics Inc | CF14JT1K00 | RES 1K OHM 5% 1/4W | 1 | $0.1 |
| P6 | Stackpole Electronics Inc | CF14JT330R | RES 330 OHM 5% 1/4W | 1 | $0.1 |
| P7 | Stackpole Electronics Inc | CF14JT20K0 | RES 20K OHM 5% 1/4W | 2 | $0.10000 | 
| P8 | 	Analog Devices Inc. | OP07CSZ-REEL | IC OPAMP GP 1 CIRCUIT 8SOIC | 1 | $2.31000 |

## References
1) R. C. Dorf and J. A. Svoboda, Introduction to Electric Circuits, 9th Edition, John Wiley & Sons, Inc., 2014   
2) Wyss, K. Scaling and Biasing Analog Signals, Symmetric Research, 24 Nov. 2007, http://edge.rit.edu/edge/P17105/public/Final%20Documents/pihat/docs/raspi_zero_power_sensor_hat/app_notes/resistor_biasing.pdf.  
3) “OP07 Datasheet by Analog Devices Inc..” Digi, https://www.digikey.com/en/htmldatasheets/production/53383/0/0/1/op07.html.

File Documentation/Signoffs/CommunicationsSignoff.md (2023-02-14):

# Communication Signoff
## FUNCTION OF THE SUBSYSTEM
The Communication subsystem is responsible for receiving data from the Microcontroller subsystem, connecting the device to the Internet, and formatting/encrypting and sending the received data to the Web & Wireless subsystem.  Encryption is done to protect the data from outside malicious intent.  These functions may be done in two configurations: 4G LTE or Wi-Fi.  This subsystem can be configured to utilize 4G LTE (Long-term Evolution) as a standard in telecommunications to connect to the Internet for its near global coverage [1].  This subsystem may also be configured to connect to the Internet using Wireless-Fidelity (Wi-FI) and its associated IEEE 802.11 (802 Family Set) standard [12].  The Web & Wireless subsystem, a server conjoined to the Internet, will wait for data from the Communication subsystem, format and encrypt the data, and then store and display it for the user on a webpage.

## CONSTRAINTS ON THE SUBSYSTEM
Constraints on the subsystem are as follows for 4G LTE configuration:
1. The component must be able to utilize 4G LTE telecommunication.  This is the chosen method of accessing the Internet for users needing its coverage.
2. The component must have support for a Subscriber Identity Module card (SIM).  
3. Price for this component should remain under $100 as end-users only have a budget of $300.  Recurring costs per month should be $10 or lower.  Allocating 1/3 of the budget is from estimating the costs of other subsystems and viewing prices of available options that satisfy the functions.
4. For receiving data from the Microcontroller subsystem, Universal Asynchronous Receiver/Transmitter (UART) as standards for hardware communication will need to be achievable with at least 2 UART pins [2] [3].  
5. This project aims for replicability, so a board that remains relevant and available is a key part. The manufacturer needs to be a reputable and safe choice. A stable and reputable manufacturer is assumed to remain in business for years to come and continue producing the chosen board. Public and customer reviews will be used to gauge manufacturer reputability while board production history will be used to gauge product longevity.  

Constraints on the subsystem are as follows for Wi-Fi configuration:
1. The component must have support for connecting to an already established Wi-Fi network for Internet access.  
2. Price for this component should remain under $100 as end-users only have a budget of $300.  Allocating 1/3 of the budget is from estimating the costs of other subsystems and viewing prices of available options that satisfy the functions.
3. For receiving data from the Microcontroller subsystem, Universal Asynchronous Receiver/Transmitter (UART) as standards for hardware communication will need to be achievable with at least 2 UART pins [2] [3].
4. This project aims for replicability, so a board that remains relevant and available is a key part. The manufacturer needs to be a reputable and safe choice. A stable and reputable manufacturer is assumed to remain in business for years to come and continue producing the chosen board. Public and customer reviews will be used to gauge manufacturer reputability while board production history will be used to gauge product longevity.  

## BUILDABLES OF SUBSYSTEM
“Timers” refers to physical or software timers that act as a "Watchdog" to prevent the system from hanging on a bad or failed connection. Once a timer is triggered, an interrupt should start and take over to see what is taking so long.  It will then either attempt to resend the data one more time or terminate the connection.  If the data or connection is still not confirmed on the second try, the connection is still terminated.
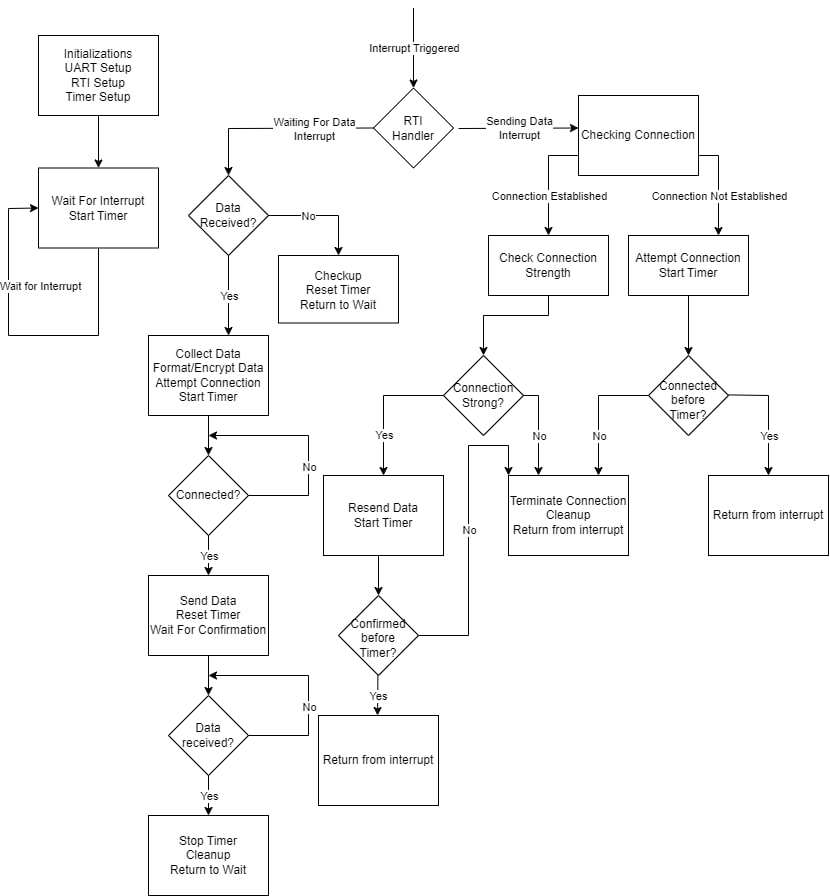
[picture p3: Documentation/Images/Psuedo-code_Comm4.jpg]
Psued-Code_Comm4


The first configuration is 4G LTE with the Maduino Zero 4G LTE(SIM7600X) connected to the Arduino.  There are only two connections to the UART pins to allow for data exchange between the two subsystems.
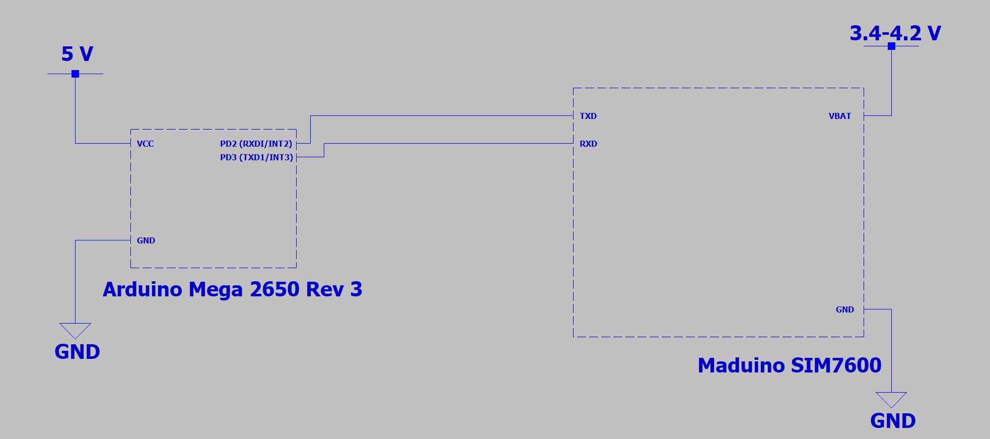
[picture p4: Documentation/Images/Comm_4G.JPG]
Comm_4G


The second configuration is Wi-Fi with the ESP8266 connected to the Arduino.  there are only two connections to the UART pins to allow for data exchange between the two subsystems.
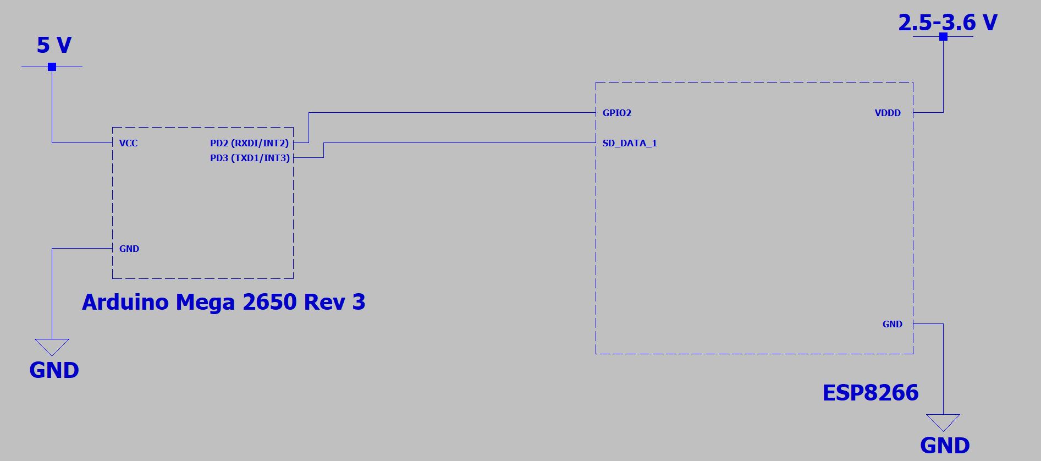
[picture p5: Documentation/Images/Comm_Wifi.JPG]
Comm_Wifi


## ANALYSIS OF CHOSEN COMPONENT(S)
The team has chosen the Maduino Zero 4G LTE(SIM7600X) to satisfy the previously listed constraints and jobs of this subsystem for 4G LTE:
1. The Maduino is able to fully utilize 4G LTE to communicate and transmit data throughout the Internet.
2. There is a slot for a SIM card on the bottom of the component with corresponding connections.
3. With a price of $64.80, it falls under the $100 limit.  Two SD cards will also be purchased for a total of $74.80.  T-Mobile Mobile Internet Access SIM card has a recurring cost of $10.
4. UART is fully supported to allow for data to be received from the Microcontroller subsystem.  
5. The SIM7600 series of boards were first introduced in 2018 and more realized in production in 2020, making them newer boards [4].  MakerFabs, founded in 2015, is a known manufacturing company that has created many variations of PCBA boards [5].  Their Maduino series is a popular option for wireless connections and is reviewed in detail by many customers positively [6] [7].  

The team has chosen the HiLetGo ESP8266 NodeMCU CP2102 ESP-12E to satisfy the previously listed constraints and jobs of this subsystem for Wi-Fi:
1. The ESP8266 has the ability to connect to a local Wi-Fi network to transmit/receive data throughout the Internet.
2. With a price of $7.99, it falls well under the $100 limit.
3. UART is fully supported to allow for data to be received from the Microcontroller subsystem.
4. The ESP8266 was launched by Espressif in 2014 and has steadily rose in popularity and usage in custom projects requiring a Wi-Fi connection [8] [9].  This manufacturer, HiLetGo, has been producing components since 2016 and specializes in robotic, sensor, and module manufacturing [9].  Although preceeded by the ESP32, ESP8266 continues manufacturing due to its popularity and performance per dollar [10].  Customer reviews highly rate the HiLetGo version of the ESP8266 in particular [11].

## BILL OF MATERIALS (BOM)
| Designator | Manufacturer | Manufactured Part # | Description | Quantity | Price Each |
| --- | ---  | --- | --- | --- | --- |
| U1 | Maduino/MakerFabs | OHMZ4G7600 | Maduino Zero 4G LTE (SIM7600A-H) (Cellular Communication Device for Wireless Data Transmission) | 1 | $64.80 |
| U2 | SanDisk | SDSDXNE-016G-GNCIN  | SanDisk 16GB Extreme SDHC UHS-I Memory Card - 90MB/s, C10, U3, V30, 4K UHD | 2 | $9.99 |
| U3 | T-Mobile | ZZZ260R070 | T-Mobile® SIM Card - 4G - 5G (Prepaid SIM card and data plan for wireless Internet access) | 1 | $9.78 |
| U4 | HiLetGo | 703681358704 | HiLetGo 1PC ESP8266 NodeMCU CP2102 ESP-12E Development Board Open Source Serial Module | 1 | $7.99 |

Notes: Do not purchase the T-Mobile prepaid SIM card  or Maduino Zero 4G LTE without an explicit request from the supervisor or instuctor and team.  Wi-Fi will be the initial focus, so there is not need to pay for a monthly plan just yet. 

Notes: The Maduino Zero 4G LTE (SIM7600A-H) ("A-H" referring to North American frequency bands while "E-H" refers to several other countries) can only be purchased from MakerFabs.  The SanDisk 16GB Extreme SDHC UHS-I Memory Card (SD Card) and HiLetGo 1PC ESP8266 are both available from Amazon.

Notes: T-Mobile prepaid SIM cards come in many packages and plans for typical tablets and phones.  We are asking for just the SIM card and data plan for ZIP code 38501.  Sim card pack T-Mobile® SIM Card - 4G - 5G (SKU: ZZZ260R070) with the Mobile Internet Plan: Unlimited Mobile Internet with up to 2GB of 5G & 4G LTE Data for $10.00 per month with $10.00 activation fee covering the first month.

## References
1. European Telecommunications Standards Institute (ETSI), "4th Generation (LTE)," https://www.etsi.org/technologies/mobile/4G (Accessed on 12-8-22).
2. Texas Instruments, Electrical Design and Semiconductor Production Company, "Universal Asynchronous Receiver/Transmitter (UART)," https://www.ti.com/lit/ug/sprugp1/sprugp1.pdf?ts=1670532165815&ref_url=https%253A%252F%252Fwww.google.com%252F (Accessed on 12-8-22).
3. Pena, Eric, Analog Dialogue, Technical Magazine, "UART: A Hardware Communication Protocol Understanding Universal Asynchronous Receiver/Transmitter," https://www.analog.com/en/analog-dialogue/articles/uart-a-hardware-communication-protocol.html (Accessed on 12-8-22).
4. SIMCom Wireless Solutions Limited, Leading Supplier of M2M Modules and Solutions, "SIM7600X," https://www.simcom.com/product/SIM7600X.html (Accessed on 12-8-22).
5. MakerFabs, Hardware Facilitation Company, "MakerFabs Main Page," https://www.makerfabs.com/wiki/index.php?title=Main_Page (Accessed on 12-8-22).
6. Tindie, Reviews, Critiques, and Marketplace, "MakerFabs Review," https://www.tindie.com/stores/makerfabs/reviews/ (Accessed on 12-8-22).
7. HowToElectronics, Engineering Community For Public Electrical Projects, News, and Articles, "Using SIM7600 4G GSM with Arduino | AT Commands, Call, SMS," https://how2electronics.com/using-sim7600-4g-gsm-with-arduino-at-commands-call-sms/ (Accessed on 12-8-22).
8. Espressif Systems, Specializes in AIoT Development, "ESP8266," https://www.espressif.com/en/products/socs/esp8266 (Accessed on 12-8-22).
9. Tones B, Instructables, Autodesk Inc., Documentation and Engineering Education Community, "ESP8266 WiFi Module for Dummies," https://www.instructables.com/ESP8266-WiFi-Module-for-Dummies/ (Accessed on 12-8-22).
10. Ida HÜbschmann, Nabto, IoT Communication Development Organization, "ESP8266 for IoT: A Complete Guide," https://www.nabto.com/esp8266-for-iot-complete-guide/ (Accessed on 12-8-22).
11. Amazon, Online Marketplace, "HiLetgo 1PC ESP8266 NodeMCU CP2102 ESP-12E Customer Reviews," https://www.amazon.com/HiLetgo-Internet-Development-Wireless-Micropython/product-reviews/B010O1G1ES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 (Accessed on 12-8-22).
12. Institute of Electrical and Electronics Engineers (IEEE), Electrical Engineer Association and Standardizing Committee, "IEEE 802," https://standards.ieee.org/featured/ieee-802/ (Accessed on 12-8-22)

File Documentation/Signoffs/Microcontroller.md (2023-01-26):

# Microcontroller Signoff
## FUNCTION OF THE SUBSYSTEM
Within this subsystem, the code will instruct the hardware in how to sample from the sensors, send data to the Communication subsystem, format and store data onto a USB Flash drive, and take readings from the power subsystem.  These are the core functions that are desired from the microcontroller.  

## CONSTRAINTS ON THE SUBSYSTEM
Constraints on the subsystem are as follows:
1. The chosen microcontroller should cost no more than $60 as the end-user only has a budget of $300.  This board value cap is gathered from estimating the costs of other subsystems and viewing prices of available options that satisfy proceeding constraints such as Raspberry Pis, Arduinos, Intel, ESP, etc.  Up to 20% of the budget was then allocated due to the importance of this subsystem.
2. The microcontroller must be able to send instructions and transfer data to other components such as the Communication subsystem.  To do this, Universal Asynchronous Receiver/Transmitter [11] [12] (UART) (2 UART pins) as a standard in hardware communication for liaising will need to be achievable. 
3. USB Flash Drive external storage support is required as per the shall statements. The USB standard [13] is used for convenience for the user as it is small, easily portable, commonly used for data storage, and readily available.
4. The board must have at least 15 digital input pins and 16 analog input pins. This allows the board to have enough Input/Output (I/O) pins to operate any combination of 3 sensors whether they be digital or analog. Different sensors interface with a potentially different number of pins; preliminary research shows most air quality sensors take 5 of fewer pins to operate, so 5 pins per sensor times 3 sensors gives 15 pins. 2 analog/digital pins will be used to read voltage/current from the power subsystem to monitor battery capacity with 1 analog pin for continuous.  It must have 2 UART pins for UART.
5. There must be sufficient memory for the code. Comparing similar operating code (Wireless Sensor Collection and Small-time Process Operating) with libraries and compilation show a range of 15 KB (10%) (Kilobytes) above or below 150 KB in flash memory.  To account for the worst case, 165 KB is the required memory.
6.  This project aims for replicability, so a board that remains relevant and available is a key part. The manufacturer needs to be a reputable and safe choice.  A stable and reputable manufacturer is assumed to remain in business for years to come and continue producing the chosen board. Public and customer reviews will be used to gauge manufacturer reputability while board production history will be used to gauge product longevity.
7. The board will need to have coding language support for C [14] and/or Python [15].  At least one must be supported. These languages are chosen due to popularity, online support, and performance.  This helps create a wider web of coverage for end-users being at least relatively experienced with coding and engineering concepts.

## BUILDABLE SCHEMATIC OF SUBSYSTEM
Shown is the pseudo-code for the operating code.  If an error arises, a default handler will need to be called to assess the situation.  It should also be noted that the loop is intended to be theoretically infinite, however, there are explicit and implicit breaks at the battery running critically low (explicit) and the shutoff button being pushed (implicit).  “Timers” refer to either physical hardware or coded timers that go off to alert the system that the sensor(s) sampling is ready.

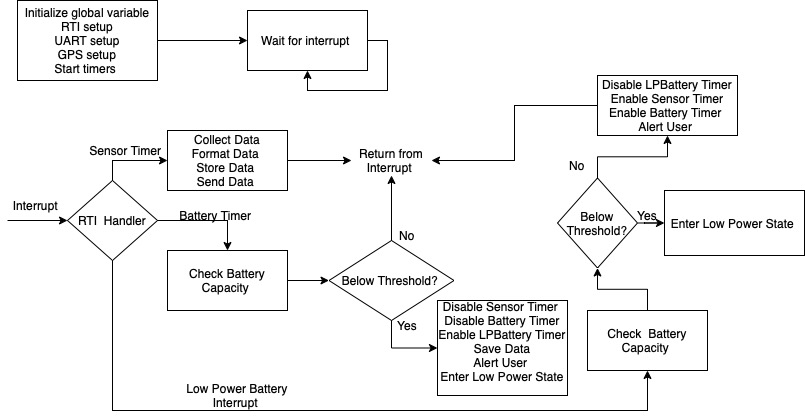
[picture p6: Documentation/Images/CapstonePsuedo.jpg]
CapstonePsuedo


Shown is a schematic of the Arduino Mega 2560 Rev 3 and USB Host Shield:
CAPSTONE 1 Microcontroller Schematic Updated

## ANALYSIS OF CHOSEN COMPONENT(S)
The team has chosen the Arduino Mega 2560 Rev 3 and Arduino USB Host Shield as the solutions.  These components, in conjunction, will satisfy the constraints and jobs of this subsystem.  Following are the corresponding fulfillment of the constraints:

1. The Arduino Mega 2560 Rev 3 falls under the preferred maximum of $60 at a current price of $48.40 (as of 11-8-22).  The USB Host Shield component has a price of $20.99 as of the same date.   
2. Four UART serial hardware ports are present which is more than the constraint value of 2.
3. The USB Host Shield enables the use of USB devices such as a Flash drive for external storage and communication. 
4. There are 54 digital input/output pins (of which 15 are PWM outputs) and 16 analog inputs.  This meets the needs for at least 18 digital (15 for sensors and 3 for USB Host) and 16 analog input pins.  There are also 4 UART pins and 21 digital (2 for battery monitoring discretely) may be assigned special purposes later on in design. One analog pin may also be used for taking a continuous measurement for the battery monitoring.
5. The Arduino Mega has 256 KB of Flash, 8 KB of SRAM, and 4 KB of EEPROM.  The SRAM and Flash memory are satisfactory for the subsystem’s needs.
6. The Arduino Mega 2560 was released in 2010 and has been in production ever since [1].  The Mega is used in more demanding projects, such as this one, and has received good reception [2] [3] [4]. No announcements of replacements or discontinuations have been made regarding the Mega 2560.  Arduino was established in 2005 and have had much support throughout the years becoming a popular and respected manufacturing and electronics design company [5] [6] [7].  
7. The Arduino Mega supports C [8][14] and Python [9][15] with a generous amount of libraries and code support [10].

Arduino has been used for many, many projects in history and has a good track record.  The Arduino Mega and USB Host Shield have conjointly shown to fulfill the needs of this subsystem.  

## BILL OF MATERIALS (BOM)

| Designator | Manufacturer | Manufactured Part # | Description | Quantity | Price Each  |
| --- | --- | --- | --- | --- | ---  |
| U1 | Arduino | A000067 | Arduino Mega 2560 Rev3 (Master Controller for User Interface) | 1 | $48.40 |
| U2 | Arduino | A000004 | Arduino USB Host Shield (Storage PCB) | 1 | $20.99 |

Notes: Both purchases can be made from Amazon to maintain same retailer.  Arduino themselves will only sell the Arduino Mega.  Links are suscetible to change and deletion, so part numbers, titles, and manufacturer are used to specify item.

## References
1. Wikipedia, free online encyclopedia, "List of Arduino boards and compatible systems," https://en.wikipedia.org/wiki/List_of_Arduino_boards_and_compatible_systems  (Accessed on 12-8-22).
2. Blom, Jim, SparkFun Electronics, Electronics Designers, Retailers, and Critiques, "Arduino Comparison Guide," https://learn.sparkfun.com/tutorials/arduino-comparison-guide  (Accessed on 12-8-22).
3. Pedamkar, Priya, EDUCBA, Skill Based Educational and Tutorial Services, "Arduino Mega vs Uno," https://www.educba.com/arduino-mega-vs-uno (Accessed on 12-8-22).
4. Element14, Provides Tutorials, Reviews, and Discussion Blogs For Engineers and Designers, "Review of Arduino Mega 2560," https://community.element14.com/products/roadtest/rv/roadtest_reviews/1068/review_of_arduino_me  (Accessed on 12-8-22).
5. G2, Software Peer Review and Marketplace, "Arduino IDE Reviews & Product Details," https://www.g2.com/products/arduino-ide/reviews (Accessed on 12-8-22).
6. Arduino, Electronics and Software Manufacturers, "About Arduino," https://www.arduino.cc/en/about (Accessed on 12-8-22).
7. Kushner, David, IEEE Spectrum, Largest Technical Professional Organization, "The Making of Arduino," https://spectrum.ieee.org/the-making-of-arduino (Accessed on 12-8-22).
8. CPlusPlus, Archive of the C, C#, and C++ Programming Language, "C-Library," https://cplusplus.com/reference/clibrary (Accessed on 12-8-22).
9. Python, Archive of Python Programming Language, "Arduino-Python3 Command API," https://pypi.org/project/arduino-python3/ (Accessed on 12-8-22).
10. Arduino, Electronics and Software Manufacturers, "Libraries - Arduino," https://www.arduino.cc/reference/en/libraries/ (Accessed on 12-8-22).
11. Texas Instruments, Electrical Design and Semiconductor Production Company, "Universal Asynchronous Receiver/Transmitter (UART)," https://www.ti.com/lit/ug/sprugp1/sprugp1.pdf?ts=1670532165815&ref_url=https%253A%252F%252Fwww.google.com%252F (Accessed on 12-8-22).
12. Pena, Eric, Analog Dialogue, Technical Magazine, "UART: A Hardware Communication Protocol Understanding Universal Asynchronous Receiver/Transmitter," https://www.analog.com/en/analog-dialogue/articles/uart-a-hardware-communication-protocol.html (Accessed on 12-8-22).
13. USB Implementor-Forum Inc., Support Organization for USB Protocols and DataSheets, "USB 2.0 Specification," https://www.usb.org/document-library/usb-20-specification  (Accessed on 12-8-22).
14. International Organization for Standards (ISO), License Holders and Technical Committees For Standards, "ISO/IEC 9899:2018
Information technology — Programming languages — C," https://www.iso.org/standard/74528.html (Accessed 12-8-22).
15. Python Software Foundation, Python Developers, "The Python Language Reference" https://docs.python.org/3/reference/index.html  (Accessed on 12-8-22).

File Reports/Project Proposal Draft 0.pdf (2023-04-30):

# Air Quality Brick

Joshua Egwuatu, Kaleb Irwin, Cameron Smith, Alejandro Moore, Marvo Odds

Computer and Electrical Engineering Department at Tennessee Technological University

115 W. Tenth St., Cookeville, TN 38505

Jiegwuatu42@tntech.edu, kjirwin42@tntech.edu, casmith51@tntech.edu, aamoore42@tntech.edu, modds42@tntech.edu

Abstract—This paper will overview the thought process and design concepts used to create a citizen air quality sensor system that is capable of providing air quality data on a local scale. This paper will also discuss why understanding the air contamination in a local area is important as well as the reasoning behind these concerns. These concerns form the problem that is to be solved which is a general hazard to health or the environment with a side-benefit of understanding an area’s atmospheric composition easier and better.

Keywords— Air Quality Sensor, Replicable Sensor Design, Community Atmospheric Science, Air Pollutant Sampling, Modular

I. INTRODUCTION

Pollution is a matter that seems to never get fully recognized by our society. Air pollution at high levels can cause a variety of adverse health risks. Some examples include heart disease and lung cancer [1]. Even with knowing this, most people don’t look into how pollution affects them in their community. Our goal is to allow people the option to see what pollutants affect them in their communities. The objective is to create an easy to use, solar-powered, modular system that uses multiple sensors to gather data on different pollutants. The data will be easily accessible online for users to decide how to combat pollution in their community.

II. FORMULATING THE PROBLEM

The modern world has sometimes experienced unhealthy or even deadly levels of pollutants in the very air humans breathe [2]. Finding local information on air quality is based on algorithmic guessing [3]. There are plenty of resources to make guesses, but true measurements of air quality are difficult to come by despite the technology existing in some forms. Services such as the weather apps on phones and PC’s give information about air quality and primary pollutants, however this is based on an average of sensors placed around a large area such as a county [4]. For a single person or community attempting to gain information from a specific location and those who would like only to gain information about certain pollutants that may not be commonly measured, this will not do the job. The obstacle for local measurements of very customized intakes is that the technology may exist, but it is not compiled to fulfill this need.

A. BACKGROUND INFORMATION

Before reading further into the proposed device and related information, a quick background check is provided here on: air quality sensors themselves, effects of contaminated air, how common values are obtained.

First, air quality sensors are devices used to detect levels of contamination in the air [5]. The inner workings of air sensors vary widely from lasers that measure size and number of pollutants to ultrasonic disruption when sending out sound waves to bounce off pollutants [6]. The sensors take their measurements and then convert them to an electrical signal regardless of the method the data was gathered. It is here where the proposed device comes into play to read in this electrical signal to convert it into an easier to read format. So, knowing how the sensor functions is important but for the interest of the project, the conversion and formatting is the focus.

Second, air contamination refers to chemicals or particles in the air that can harm the health of humans, animals, or plants [7]. There is no specific measure to account for as the project calls for a variety of measurements to be available. Knowing this, there are a great many health concerns that could be revealed when testing the air quality. From the National Geographic team, “Long-term health effects from air pollution include heart disease, lung cancer, and respiratory diseases such as emphysema. Air pollution can also cause long-term damage to people's nerves, brain, kidneys, liver, and other organs. Some scientists suspect air pollutants cause birth defects” [8]. If the proposed device can reveal these pollutants in local communities, many could be saved from undesirable health risks or even death.

Third and lastly, the U.S. government and some companies provide information on air quality regarding an area through weather apps. These apps source their information from sensors placed around the region being tested. These sensors are placed in general locations and then use algorithms to average and guess air quality of regions in between the sensors [9]. Think of it like a wide web with gaps between the strings that are filled in after the web is made. For general use, this is fine, however for someone wanting to use the real data in their research, this will not do. Having access to the true air quality data would allow for a more accurate groundwork for any point trying to be proven. This is whether to prove the air quality around a certain area is harmful or that the common values are misleading, whatever the case.

B. SPECIFICATIONS AND CONSTRAINTS

Here are the “shall statements” of the project. The specification and constraints placed upon the construction and design of the project were given by the customer and also based upon some background research.

- Shall be protected against rain. The standard to be followed will be IPX4 water resistance from all directions to protect against rain. Nominal to heavy rainfall will be accounted for, but standard IPX5 protection against low pressure jet streams are not guaranteed.
- Shall be protected against dust and small objects. The standard to be followed will be IP3X which states protection against hazardous parts, thick wires, or solids of sizes greater than 2.5 mm.
- Shall be modular. In this instance, modularity refers to the ability to change to a multitude of previously tested and approved sensors without the need to change any or at most 2 select settings. The change of sensor should be seamless and handled by the board and software.
- Shall have a selection of tested and approved sensors to cover a range of pollutants, particulates, air composites, and other qualities. These sensors should all share the same interfacing port and work independently from another.
- Shall be relatively cost-effective. The device, additional components, and software should remain under $100. The cost for sensors is not taken into account as the sensors are used on a case by case basis.
- Shall be easily replicable. The device and additional components shall be mostly, if not entirely, off the shelf purchases. This should lower the technical knowledge required to construct the device tremendously. The software should be available for free online.
- Shall be able to operate with 3-5 sensors sampling independently of each other. Sensors will take samples at set intervals and be read and stored onto the device periodically. Samples may be read and written one at a time.
- Shall be well documented. All questions cannot possibly be answered, however, a very strong groundwork for how the device operates and basic functions with limitations shall be documented. This should answer common questions that may arise. More specific questions would require additional testing.
- Shall have easily accessible data. The device should be able to take data from storage and send it to a website to be read from the user remotely. If the user wishes, he/she may also read data from the device directly. Formatting will be basic and leave room for improvement for future development.
- Shall utilize sensors that share the same type of I/O port. The sensors should be able to be interchangeable to any other sensor port on the device. To achieve this, the sensors all use the same I/O and similar data transfer options.

These are the specifications to be met when constructing and designing the project. They are absolute statements. It should be noted however, that given the status of the team as undergraduate students, the project may falter in regards to certain projections i.e. knowledge, time, and resources.. Realistic goals are at present set, but, due to the unpredictability of the future, these goals may change.

C. SURVEYING SOLUTIONS

Before a settlement is made on an approach to success, existing methods are taken into consideration. The reason for this is simple: if the solution already exists, then this project is folly. However, given the solution is absent from the known world, this allows for a multitude of perspectives from previous works when looking for a solution to call original. What was found: air sensors are not typically used in an interchangeable way but other sensors are, some multi-use air sensors have been made but have limitations, modular microcontrollers can be used to fulfill the project needs when modified, and air quality checks are public information given by companies.

First, the technology of today already includes a large variety of air quality sensors. The issue with these sensors is their inherent simplicity. One sensor can be used for its particular task, but if the user wanted to use air sensors, these could not be interchanged. The housing unit, or chunk of material the sensor is attached to, will never change or work for another kind of air sensor. This is one issue that needs to be addressed. A core goal for the project is to allow for interchangeable air sensors. This means that the housing unit must accept many different types of air sensors. The technology to do this exists, but it has not been compiled together in this way. For example, the company Ellab makes vacuum, pressure, and temperature sensors that all use the same connections and may therefore be used interchangeably [10]. Their methods may be incorporated for subverting this issue.

Another solution from today sees that air sensors already exist with the ability to measure a range of pollutants, particulates, or compositions in the air. The company Airly Inc. produces a device called Airly PM. [11]. This device is capable of measuring many pollutants and particulate matter all in one easy to use device. So, multiple kinds of sensors can be used simultaneously on one device, however, this device comes with a preset of sensors that cannot be altered or customized. If the user wanted to measure something not included in the preset, this would not be possible. This was likely to stay in the realm of “easy to use”. Finding a balance of easy to use and having a variety of sensors is one target for the project. More options could inadvertently confound the user and should be avoided.

Other works to consider are Arduino and Raspberry Pi which are popular microcontroller boards that allow for modularity[12] [13]. The problem inherently requires modular components, so the existence of these boards does allow for an off the shelf option. This allows for a more simple user experience which ultimately does make the product more accessible to more people. Lowering the knowledge requirement for constructing this device potentially allows more to be built and hopefully improved for future use around the world. The concept of this device being easy to make, easy to use, and give sufficient data is a driving factor when making a community-friendly product.

One last piece of existing works to consider is the air quality sensors providing regional information for large portions of the world. A big example is the Air Quality Index (AQI) provided by the U.S. Environmental Protection Agency. The AQI takes information from sensors placed in key locations around the United States to make assumptions about the air quality for a certain area using sophisticated algorithms [14]. This may sound like the problem is already solved in this case, but this project seeks to get true local results. The algorithms used can only make guesses. Bypassing the algorithms and jumping straight to the raw data will provide a true local reading for the air quality around a designated region.

III. LOOKING FOR SOLUTIONS

The goals specified are to be achieved within our detailed window of time. During that period, the design process and phases may contain obstacles that could potentially slow development and cause other problems if not solved. Predicting and being prepared for those potential obstacles gives more options and further development to meet specifications and requirements.

As stated before, the task of having a port designed as input to use a desired sensor interchangeably is difficult to solve. Finding an adapter that can be integrated into the system can solve this issue. Since there are many different pollutants, one goal is to make the air quality device to house 3 different pollutants and receive informative data on each at the same time. Even though it will be able to send current-time data for 3 pollutants, the device shall be able to house sensors for 8 pollutants in total.

Another potential issue that may hinder the replicability is using custom components within the device in order to achieve requirements. It has already been stated that one goal is for the air quality sensor to be easily rebuildable and low cost. Therefore, custom products that may be difficult to remake or design are not to be used during the development of this project. Arduinio or Raspberry Pi products can solve interface issues and system user control. Microcontrollers that can communicate using SPI, I2C, or UART to other receiving microcontrollers can be useful for the functionality of this device.

A. UNKNOWNS, IMPLICITS, EXPERIMENTATION

Accounting for the future and all hindrances that may follow it is, to put it bluntly, currently not feasible. The best that can be done is predicting likely hurdles and how to approach them.

1) The team falls behind on deadlines.
a) In this case, the team should begin to reassess what can be done in reasonable time and double efforts on this.
2) There are difficulties with the microcontroller boards.
a) In this case, the team should do plentiful research on the board to investigate workarounds or modifications. If this does not solve the issue, then another board will have to be chosen.
3) The board is unable to handle wireless communications to the Internet.
a) In this case, the board will need to be altered to accommodate network functionality.
4) Certain sensors are malfunctioning with the device.
a) In this case, the sensors that are malfunctioning will need to be discarded in favor of an alternative.
5) The necessary knowledge to complete a task is unknown to each team member.
a) A team member will volunteer or be selected to investigate the problem and research the necessary knowledge to complete the task.
6) A team member is inhibited from completing designated workload.
a) Other members of the team will divide the designated workload amongst each other.

Again, predicting the future takes into calculation far more variables than the average human is capable of working with. Knowing this, there are things that can be done to minimize the risk of failure: consistent updates from members, asking for help when it is needed, seeking outside knowledge, performing thorough research, allowing time for sufficient experimentation, and designating one member to allot time for tasks.

During experimentation, the goal should be to find the most effective design regarding costs, effort in construction, and completion following the measures of success. It should be noted that during experimentation, not all effects could be found. This is to say that some effects of the device could be unintentional, although, it is highly unlikely considering the nature of the device, but this is still worthy of mentioning. These effects cannot be specified at this time due to them falling under the unknowns of the project. If these unknowns were to affect the measures of success, then a potential design modification would be required.

B. MEASURE OF SUCCESS

Measures of success for this project will be based on how well the shall statements are fulfilled. The primary measure of success will be an operational system that can provide sensor data, remotely, from three or more user chosen sensors, simultaneously. Another major measure of success will be if the device can operate in most environments and still function properly. This includes nominal weather conditions as well as rain and snow. It should also be able to operate properly through a range of temperatures that is at least equivalent to the operational range of the sensors selected. A further measure of success will be how cost effective the system is and how replicable and modifiable the system is. There should be extensive documentation of all components and the design should be buildable and modifiable by someone with limited electrical engineering experience. The system should not be expected to give data for a large region such as a city or county as resources are already available for this. As with any project in engineering there will always be ways to improve the design.

Based on how well the system functions, the results of our measures of success, and customer satisfaction the design will be finalized.

C. ETHICS AND RESPONSIBILITY

For this design process we shall follow any and all engineering design standards and all standards and laws set by governing bodies to prevent risk and unintended harm to users of this device and their communities. For example, the device will not be rendered faulty or unsafe to the public if one error occurs during use of this product. This device has no foreseen negative impacts on the communities that decide to implement the product, but the potential positive outcomes are many. Communities will be able to see if the air quality in their homes, work places, and schools are safe for them and their children. Groups will be able to see what pollutants are specifically affecting the air around them and take the necessary steps to solving the issue.

IV. RESOURCES

Resource listings here are speculation for what tools, software, components, testing equipment, and software may potentially be required to complete the project.

- Visual Studios, Notepad++, or some other type of code editing software.
- Microcontroller integration software to program any boards that may be used.
- Arduino or Raspberry Pi boards. Currently unknown model.
- Port modules to be added to related microcontroller boards.
- Multimeters for voltage and amperage testing.
- Potentially a soldering kit, however, this will try to be avoided when making design choices.
- Hand selected air quality sensors. This is to be determined later when a standard for I/O ports has been made.
- Related cables and connectors to I/O ports.

Time is another resource that must be considered. The project is to be completed over the course of two semesters. With this in mind, time is not an unlimited resource. Estimating the hurdles and objects to pass, the allotted time should be sufficient to create a prototype of the device and allow for future development.

The last resource to consider is the budget. In order to stay in line with the goal of having a low-cost design, the prototype should be constructed out of materials with a monetary value under $100. Given that Raspberry Pi and Arduino boards can range from $10 to $80, further research into the most cost-effective option will need to be completed. Other resources are for designing the device itself as the software will be available for free online. The sensors themselves are not taken into consideration as the cost changes case by case. I/O port modules are inexpensive and only add at most $10 if not already present on the board.

A. PERSONNEL

There are many different aspects of electrical, computer, and mechanical engineering that will be implemented within this project. As such, in order for our specifications to be met and shall statements verified, we will need to use an ample amount of time in research, design concept, and experimentation. Looking at various sensors and product standards will be some of the things we will need to look at. Finding the correct component/circuit/ or system will be a major factor to our development process.

All of the members on our team have studied over various circuits and how to implement them to do what the developer wants it to. I, Alejandro Moore, have had some experience in PCB circuit design, analysis, and manufacturing. Knowing what is the correct component to the system and analyzing how it should be used are things that I will need in order to understand and record the design process. I have also had some experience in BNC cable installation and other types of wires. Learning these concepts has given me resources I can share with the team if needed. Also, I am aware that my team members have other skills that can also be used within this project. This is beneficial for the functionality of our team, because it can help the others learn the concept and further the process of our project.

I, Marvo Odds, have had many experiences in digital logic projects,circuit design and coding projects. Many of these experiences came in the form of projects from my classes at Tennessee tech such as coil gun circuit, digital logic circuit that implemented the game Ship,Captain,Crew, and my coding projects in CSC 1300 that used C++. This is beneficial because our design will need knowledge in circuit design and coding to implement our website and databases.

I, Cameron Smith, know that this project will ask us to gain new skills and knowledge as we progress. This can be done by seeking guidance from experienced instructors, reading research in articles and texts, and observing other design projects. The skills I bring to the team are familiarity with C, C++, and assembly coding languages, programming microcontrollers, digital design, circuit analysis, and client/server communication design. I fully expect to learn more skills by necessity and not exclusive engineering related skills but also teamwork and group communication skills.

I, Joshua Egwuatu, have had experience in the field of engineering. I understand the design process in its completion from start to finish. I also have experience in C++, Solidworks, and Altium. I also have a strong background in leadership and communication due to the many roles I’ve helped in my academic career. I expect my skill set to be beneficial for the team, and I can’t wait to pick up skills along the way!

I, Kaleb Irwin, have experience in coding primarily in C++, and a little bit in HTML as well. I also have worked with microcontrollers before and designed several small projects throughout my time in engineering at Tennessee Tech from making the game Shut the Box with logic gates to designing and building a coil gun. Almost certainly more skills and experiences will be required during this project and I am looking forward to getting started.

B. TIMELINE
1) Project Proposal: September 25th, 2022
2) Conceptual Design & Planning Final: October 30th, 2022
3) Detail Design Draft 1: November 10th, 2022
4) Detail Design Draft 2: November 24th, 2022
5) Design 1 Final: December 11th, 2022
a) Final Presentation for Design 1
6) Design 2 Draft: March 6th, 2023 (Estimate)
a) Prototype
b) Website Completion
7) Final Presentation: April TBD, 2023

REFERENCES

[1][8] Kim Rutledge, Melissa McDaniel, Santani Teng, Hilary Hall, Tara Ramroop, Erin Sprout, Jeff Hunt, Diane Boudreau, Hilary Costa, “Air Pollution”,
https://education.nationalgeographic.org/resource/air-pollution. (https://education.nationalgeographic.org/resource/air-pollution) (Accessed on 9-21-22).
[2] “Pollution Facts”,
https://aqli.epic.uchicago.edu/pollution-facts/. (Accessed on 9-22-22).
[2] “Air Quality and Health,” https://www.pca.state.mn.us/air-water-land-climate/ai r-quality-and-health. (https://www.pca.state.mn.us/air-water-land-climate/air-quality-and-health) (Accessed on 9-21-22).

[3][14] “Air Quality Index (AQI) Basics”, https://www.airnow.gov/aqi/aqi-basics/#:~:text=How %20does%20the%20AQI%20work,300%20represent s%20hazardous%20air%20quality. (https://www.airnow.gov/aqi/aqi-basics/) (Accessed on 9-21-22).

[4][9] “Understanding the Air Quality Index (AQI),”
https://www.pca.state.mn.us/air-water-land-climate/understanding-the-air-quality-index-aqi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,National%20Amb ient%20Air%20Quality%20Standards. (https://www.pca.state.mn.us/air-water-land-climate/understanding-the-air-quality-index-aqi) (Accessed on 9-20-22).
[5] Karen Howard, “Science & Tech Spotlight: Air Quality Sensors,”
https://www.gao.gov/products/gao-21-189sp. (Accessed on 9-19-22).
[6] “Operating Principles of Air Quality Sensors,”
https://www.careforair.eu/en/on-what-principles-do-air-quality-sensors-work/. (https://www.careforair.eu/en/on-what-principles-do-air-quality-sensors-work/) (Accessed on 9-20-22).
[7] Jillian Mackenzie, Jeff Turrentine, “Air Pollution: Everything You Need To Know,” https://www.nrdc.org/stories/air-pollution-everything-you-need-know. (https://www.nrdc.org/stories/air-pollution-everything-you-need-know) (Accessed on 9-21-22).
[10] Ellab Inc. “Wireless Environmental Monitoring,”
https://www.ellab.com/solutions/monitoring-solutions/. (https://www.ellab.com/solutions/monitoring-solutions/) (Accessed on 9-22-22).
[11] Airly Inc. “Air Quality Sensors,” https://airly.org/en/features/air-quality-sensors/. (Accessed on 9-21-22).
[12] Raspberry Pi, “Raspberry Pi,” https://www.raspberrypi.com/. (Accessed on 9-23-22).
[13] Arduino, “What is Arduino,” https://www.arduino.cc/en/Guide/Introduction. (Accessed on 9-23-22).

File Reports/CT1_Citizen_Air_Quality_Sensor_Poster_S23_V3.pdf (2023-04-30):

## Spring 2023

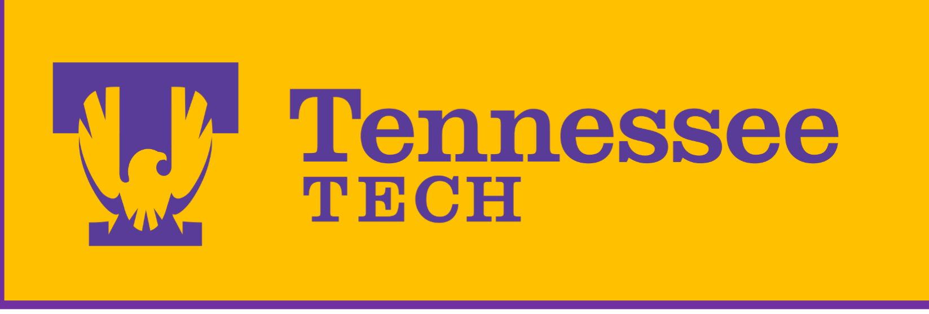
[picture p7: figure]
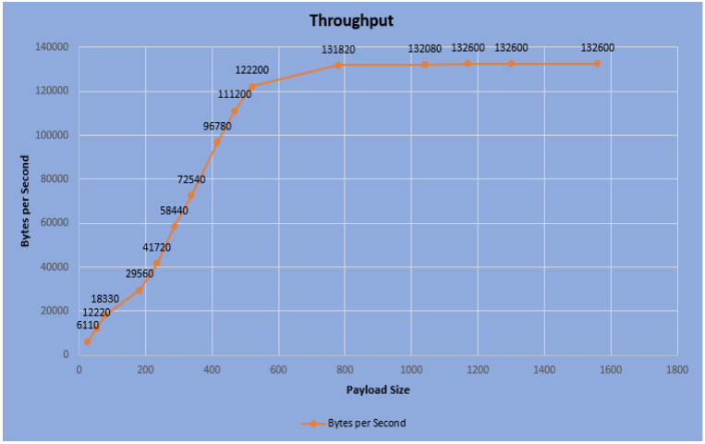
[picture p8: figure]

## Introduction

In the modern age, humans have pushed levels of pollution in the world to unprecedented levels. Pollution affects the air that all living things rely on to survive. The project goal was a modular device that accepts & operates multiple air quality sensors independently for local data collection. The negative repercussions of air pollution led to the proposal of a device allowing citizens to monitor pollutants in their communities.

## Core Features

- Be able to measure six common qualities: carbon monoxide, lead, nitrogen oxides, ozone, particulate matter & sulfur dioxide.
- Easily replicated with little engineering experience or knowledge.
- Be relatively inexpensive at $300 maximum.
- Utilize multiple sensors simultaneously.
- Allow for easily accessible data via the website or directly by using a USB flash drive.

## Ambition

There were numerous planned features for the final version. Time constraints & workload volume resulted in various features being omitted from the final product. Electrically, the proposed device was simple. In terms of software, it required far more nontrivial coding than anticipated.

## Proposed Solution

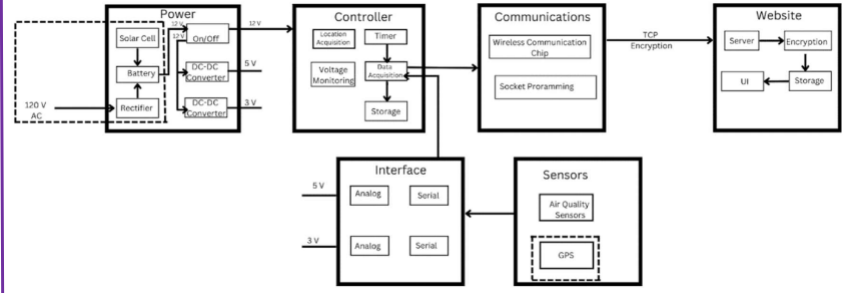
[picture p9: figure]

## Development of Solution

Product development suffered from three main issues: Ordering holdups, parts delivery delays, and workload, especially for the Communications subsystem & sensors. The original Communications design had to be discarded due to its reliance on the decommissioned 3G cell network. With components being a major issue, numerous compromises had to be made to simulate the device’s I/O. Other kinds of sensors were used for testing purposes & proof of concept. With our stand-in sensors and microcontroller, we coded a polling solution before moving to an interrupt solution. Next, we adapted a method of logging sampled data onto a USB Fat32 flash drive. Next, we moved to wireless logging to a website. The server solution was discarded in favor of a Google script that logged the data to a Google Sheet linked to a Google Site.

## Results/Experimentation

The device can reach sample rates of 8924 Hz, a throughput of 132600 Bytes, and a lifetime of 524 hours with tested solar conditions. All data can be logged onto to local flash drive and website. The limiting factor is logging into the website due to POST cooldowns. This can be circumvented by sending accumulated data using the ESP8266’s ability to send bigger payloads with sufficient throughput. Analog and Digital signals are supported. The battery lasts for up to 81.14 hours. The solar option can increase this value to 418 hours assuming optimal solar conditions. Battery and solar can be forfeited for operating off mains power. Practical sample rates for application are 2 Hz nominal and 10 Hz at high wind speeds. A sampling at 8924 Hz is possible but is an unnecessary waste of resources.

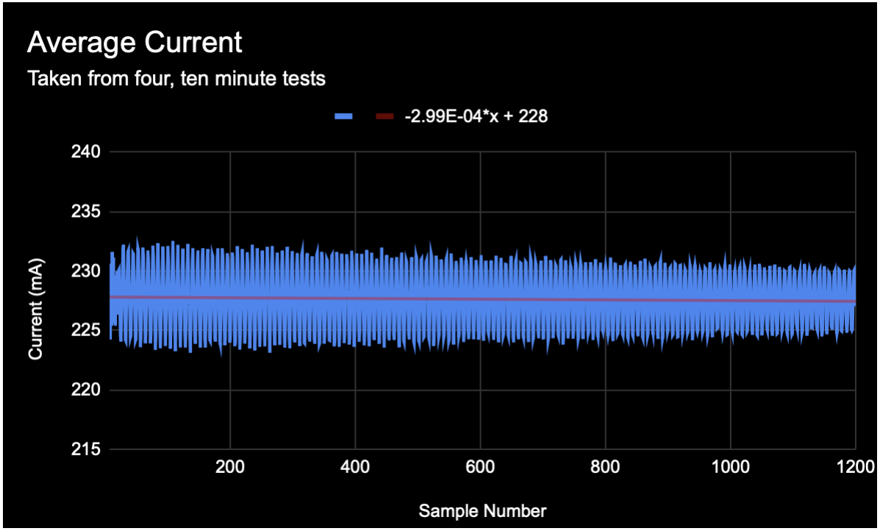
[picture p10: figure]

## Future Work

- Air quality sensors are needed to measure air quality.
- Finish development on a sleep mode for saving power.
- Implement a configuration header file for optional modes.
- An error handling functionality is a must for long-term operation.
- Global positioning system and encryption for security.
- Battery capacity measuring and notification when low.

# Citizen Air Quality Sensor

## Cameron Smith, Kaleb Irwin, Marvo Odds, Alejandro Moore, Joshua Egwuatu

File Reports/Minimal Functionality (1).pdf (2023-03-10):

# Minimal Functionality

Joshua Egwuatu, Kaleb Irwin, Cameron Smith, Alejandro Moore, Marvo Odds

Computer and Electrical Engineering Department at Tennessee Technological University

115 W. Tenth St., Cookeville, TN 38505

Jiegwuatu42@tntech.edu, kjirwin42@tntech.edu, casmith51@tntech.edu, aamoore42@tntech.edu, modds42@tntech.edu

I. POWER
- Operate using battery power
- Operate using AC mains power
- Supply 5 V to the Arduino through a USB input.
- Supply appropriate voltages to sensors.
II. SAMPLING AND INTERFACING SENSORS
- The sensor will transfer the measured data to the microcontroller via the interface.
- Sample at a minimum of 2 Hz.
III. MICROCONTROLLER
- Store data onto a USB flash drive.
- Receive analog voltage, analog current, and digital data from the interface.
- Send data to the Communication subsystem.
IV. COMMUNICATION.
- Receive data from the Microcontroller, format the data, and send the data through the use of Wi-fi to be displayed on a terminal.
V. WEB AND WIRELESS.
- Receive data from the device and have a simple display in a numeric form.

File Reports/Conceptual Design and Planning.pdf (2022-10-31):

# Citizen Air Quality Sensor

Joshua Egwuatu, Kaleb Irwin, Cameron Smith, Alejandro Moore, Marvo Odds

Computer and Electrical Engineering Department at Tennessee Technological University

115 W. Tenth St., Cookeville, TN 38505

Jiegwuatu42@tntech.edu, kjirwin42@tntech.edu, casmith51@tntech.edu, aamoore42@tntech.edu, modds42@tntech.edu

I. INTRODUCTION
A. Problem Definition

The goal of this project is a replicable device that accepts and operates multiple air quality sensors independently with a selection of interchangeable sensor options for local data collection. Air quality is vital to maintaining life on Earth [1]. Poor air quality can result in a slew of health problems such as heart disease and lung cancer [2]. In the modern age, humanity pushes the levels of pollution in the world to unprecedented levels as compared to the pre-industrial era [3]. This pollution affects the very air that all living things rely on to survive. This perspective on the negative repercussions of polluting the air and Earth is what led to this team’s proposition of a device that allows everyday citizens to see what pollutants blight their communities.

There are already services that exist to alleviate this problem, however, the services do not fulfill the solution to a high degree. The biggest of these services would be the Air Quality Index (AQI) provided by the United States Environmental Protection Agency [4]. The AQI takes in data from sensors placed systematically all across the country and in highly populated areas [5]. This data is then aggregated together to fill in any regions that were not explicitly sampled from a sensor directly [5]. The issue derives from that last sentence. Because it is not reasonable or cost-effective for these services to place sensors everywhere, the readings that are received from these sensors may not be accurate in any given place. For a community wanting a detailed view into the air quality of their chosen area, they would require more concrete sources of data. It is here where the team’s proposed device comes in to provide an easy-to-use, solar-powered, easily replicable, and low-cost modular system that uses multiple sensors to gather data on different pollutants.

This document is important in the design process because it will present general solutions based upon the constraints and requirements previously stated in the project proposal. The document will also give a description of each subsystem and how each works. Giving a high-level look at the solutions and proposed diagram will allow for the team to break down the overall problem. In doing this, the idea is to solve the problem in smaller and easier to comprehend steps.
B. Constraints

List of shall statements (format [SS#]) that are referred later:

### 1. Shall have a selection of tested sensors to cover a

range of pollutants, particulates, air composites, and other qualities. Common qualities to measure are carbon monoxide, lead, nitrogen oxides, ozone, particulate matter, and sulfur dioxide. Other qualities may be selected in the future, but these are definite qualities to look for. These sensors should work independently from each other.

### 2. Shall be easily replicable. The device and additional

components shall be mostly, if not entirely, off-the-shelf purchases. This should lower the technical knowledge required to construct the device tremendously. The software should be available for free online on GitHub. Software licenses will be included depending on which software is chosen and used.
3. Shall be relatively cost-effective. The device, additional components, and software should remain under $300. The cost of sensors is not taken into account as the sensors are used on a case-by-case basis.

### 4. Shall be protected against the environment. The

standard to be followed for water resistance will be IPX4, protecting from all directions against the rain. The standard to be followed for dust and small objects will be IP3X which states protection against hazardous parts, thick wires, or solids of sizes greater than 2.5 mm. The device will operate in a temperature range of 10°F to 90°F. This covers a wide and likely temperature range seen in the U.S. The device will also be staked into the ground and resist wind speeds up to 74 mph.

### 5. Shall be modular. In this instance, modularity refers

to the ability to change to a multitude of previously tested and compatible sensors without the need to change any or at most 2 select settings. The change of sensor should be seamless and handled by the board and software.

### 6. Shall utilize sensors that are interchangeable. The

sensors will have multiple kinds of Input/Output (I/O) ports, so a list will be made that acknowledges all I/O ports of sensors to be approved and tested. The I/O ports that are shared among a group of sensors should be able to operate seamlessly if swapped out from the same type of I/O port for another sensor in the group using that I/O port. Sensors that do not share this I/O port will have a port of its own grouping that has this same functionality within that group.

### 7. Shall be able to operate with at least 3 sensors

sampling independently of each other. Sensors will take samples at set intervals and be read and stored on the device periodically. Samples may be received and outputted one at a time.

### 8. Shall have easily accessible data. The device should

be able to take data from storage and send it to a website to be read by the user remotely. p If the user wishes, he/she may also read data from the device directly. Formatting will be basic and leave room for improvement for future development.

### 9. Shall have a set of security measures to protect the

device and data. The data shall be encrypted with an undisclosed algorithm. This is during transmission encryption and encryption during the storage of the data on the board. The chassis will be made of a material to be reasonably impact resistant at the standard of IK08. This standard rates the device at 5 Joules of impact. A global positioning system will also be added to aid to reclaiming during loss or theft.
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

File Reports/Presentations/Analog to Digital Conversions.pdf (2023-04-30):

# Analog to Digital Conversions

Author: Marvo Odds

# Introduction

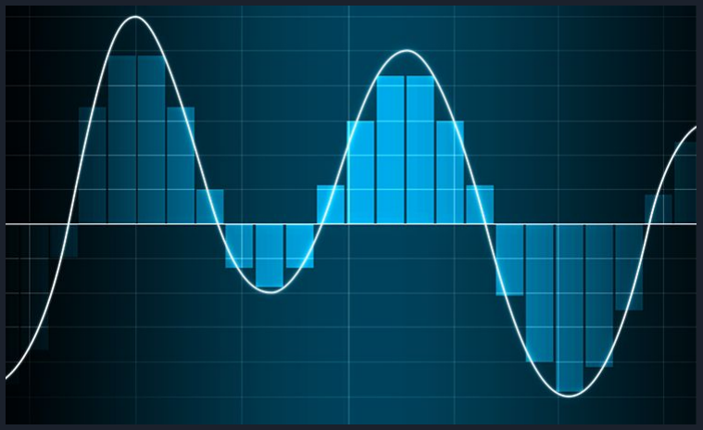
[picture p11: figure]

Analog Signals

- Voltage, current, or physical quantities that vary with time

Digital Signals

- Represents data as a sequence of discrete values

ADC
- Converts our analog world into a form countable by computers (digital)

Perception
- Humans perceive the world in analog/continuous proportions

# Digitization

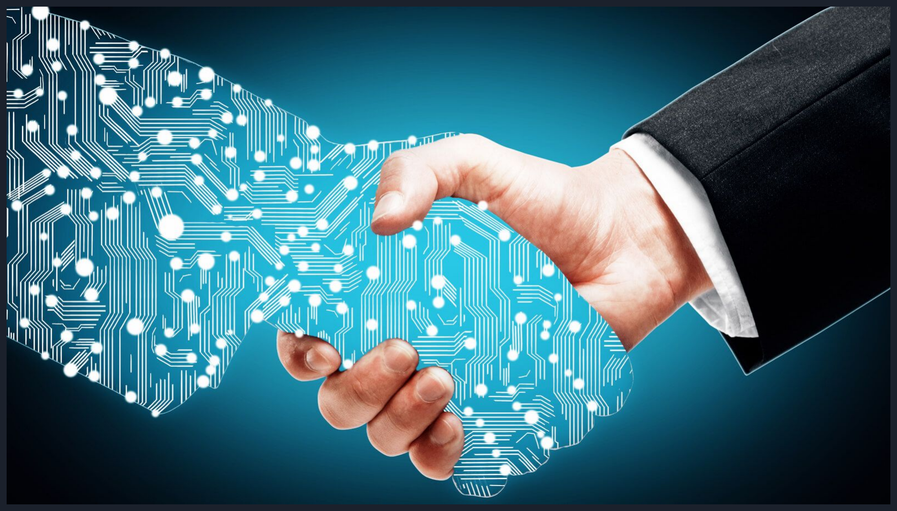
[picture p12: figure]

ADC Digitization

- Ratio of an input and reference value expressed in a digital value

Digitization Process
- Quantization:
- Input signal is subdivided into n intervals
- Encoding
- Each interval assigned to a certain value

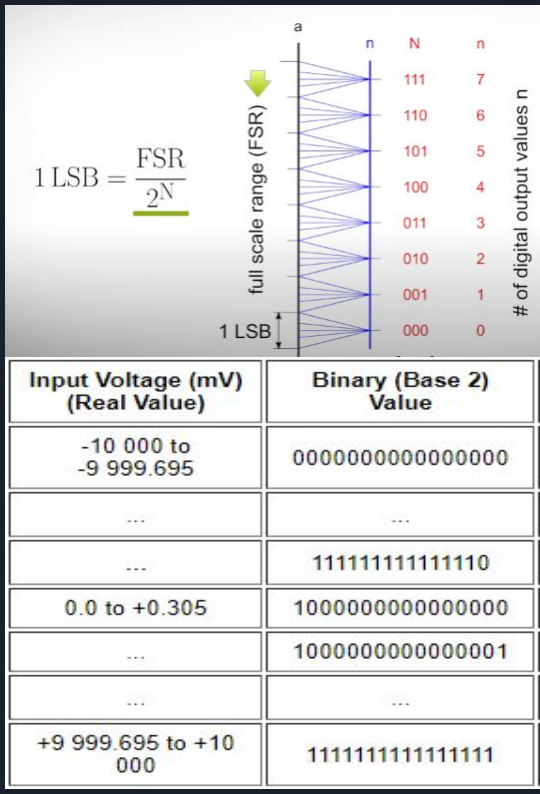
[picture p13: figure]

# Digitization cont…

Digitization

- 2^(N) = n
- If n = 8 then N = 3. ADC will represent those 8 quantization levels with 3 bits
- Resolution (LSB)
- LSB:
■ | Smallest change in input signal the ADC can measure
■ | If starting in middle of 1 quantization level, you must
| change input signal by ½ LSB to enter the next level
- In terms of voltage
■ | Each Input voltage inside a resolution range will be
| converted to a specific binary #
■ | Resolution = Voltage Range / 2^(n)
| ● 20 mV / 2^(16) = .305 x 10^(-6)

# Transfer Function of an ADC

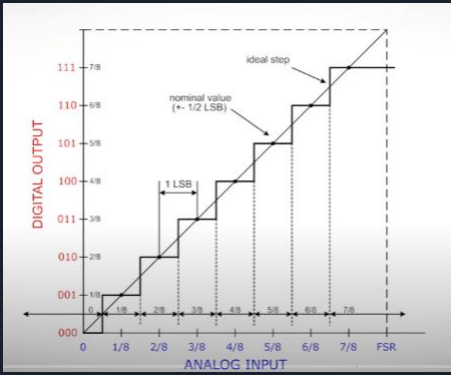
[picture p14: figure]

Unipolar ADCs:

- ADCs that only handle positive inputs

Bipolar ADCs:

- ADCs that can handle negative and positive

Ideal Transfer Function

- Does not take into account errors
- Most considered errors
- Offset Error
- Gain Error
- Non-Linearity Error

# Offset Error

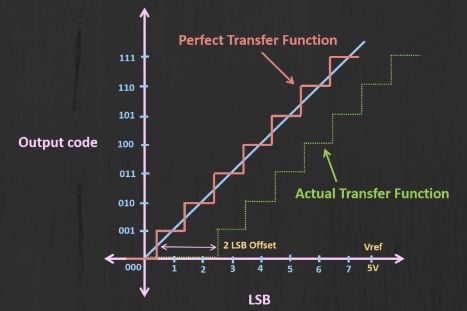
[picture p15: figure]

- Difference between the measured and ideal function
- Starting at 0 point on the x-axis
- Constant error at each point in curve. Can be corrected easily
- ADCs offer adjustment and calibration settings for offset

# Gain Error

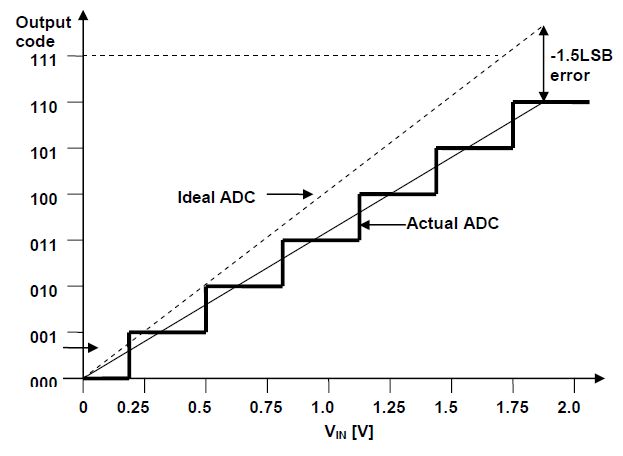
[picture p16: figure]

Gain Error

- Difference between midpoint of the final step of the ideal function from the midpoint of the actual function
- Offset error is accounted for first

Full Scale Error

- Sum of offset and gain error

Correction

- Both errors can be eliminated by ADC calibration settings

# Non-Linearity Errors

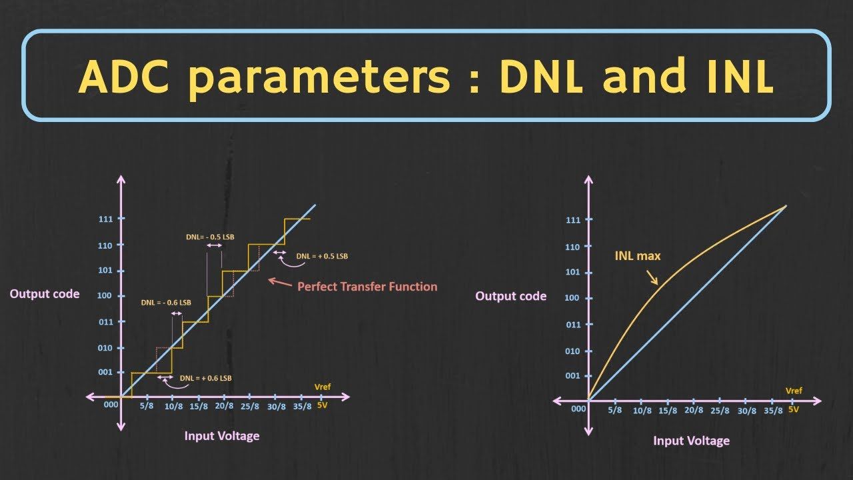
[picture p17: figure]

- Error Causation
- Appear when endpoints of real and ideal curves match due to gain and offset calibration
- Represented with curvatures in the transfer function lines
- Types of Nonlinearity Error
- Differential (DNL)
- Integral (INL)
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

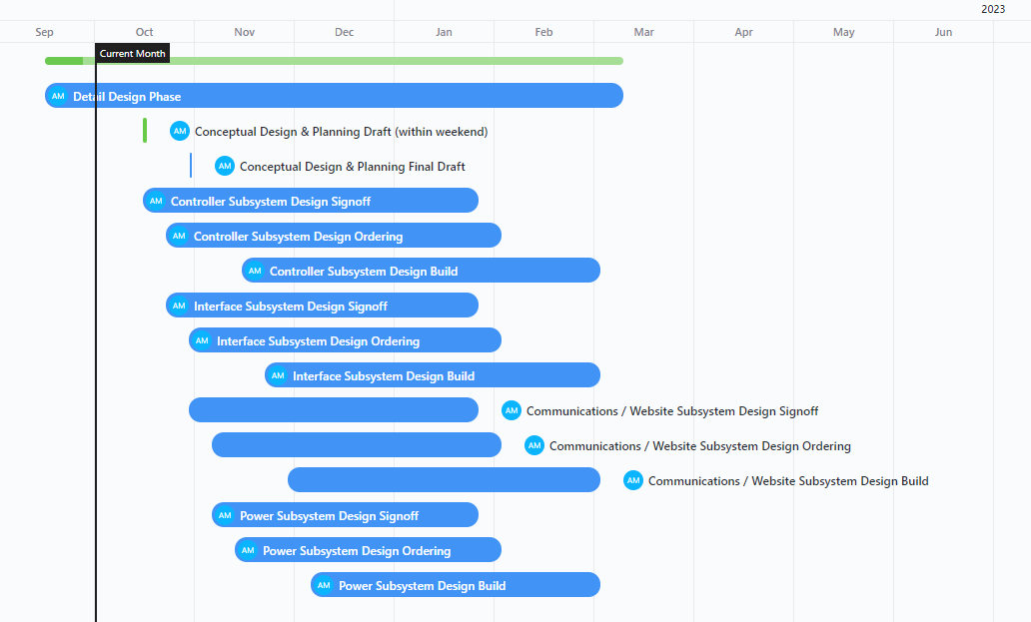
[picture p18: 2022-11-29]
Documentation/Images/CAPSTONE Team 1 Design Phase Timeline.png

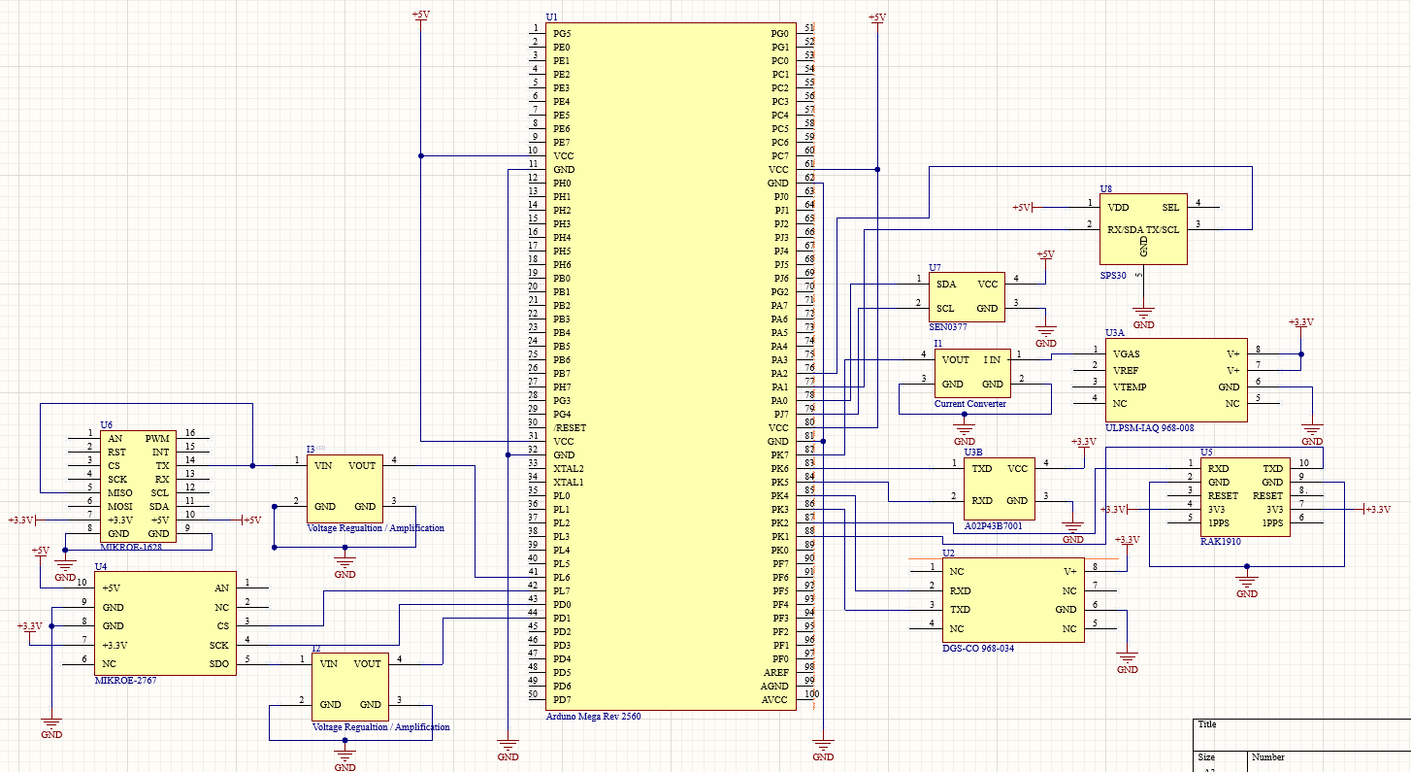
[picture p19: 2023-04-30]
Documentation/Electrical/Schematics/CAPSTONE II Sensor Subsystem.png

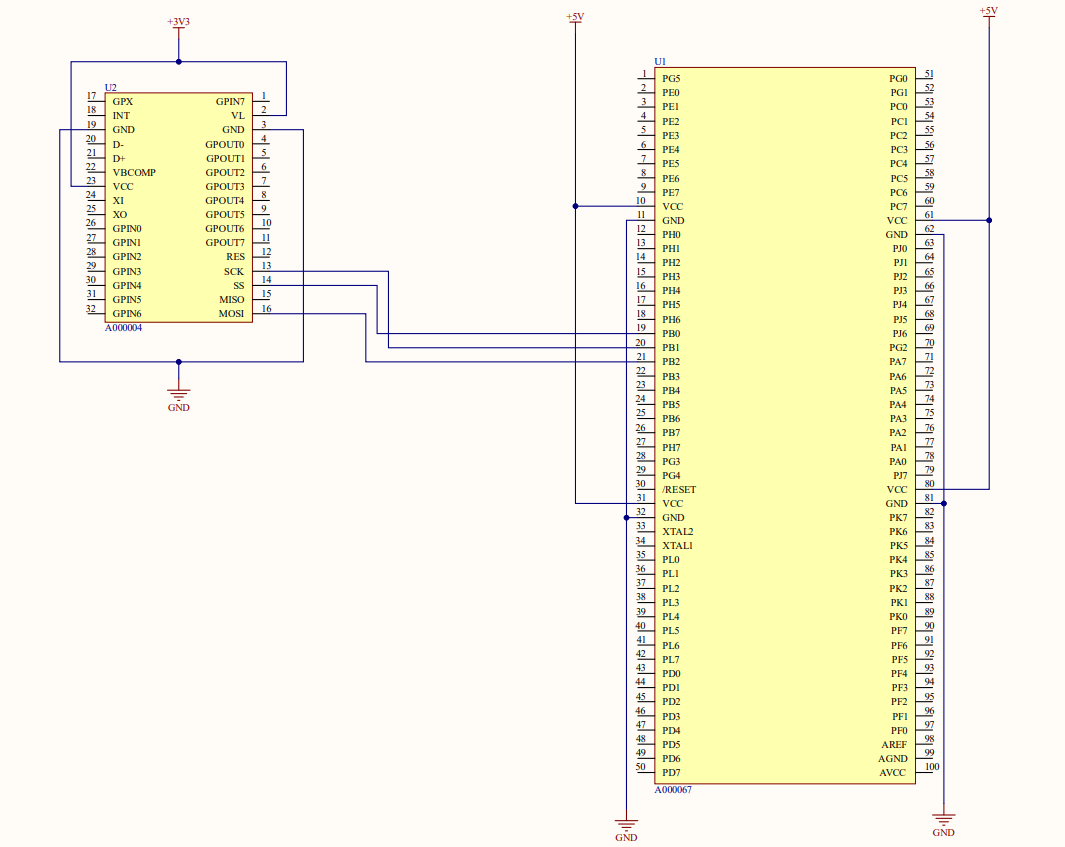
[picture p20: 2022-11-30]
Documentation/Electrical/Schematics/CAPSTONE 1 Microcontroller Schematic.png

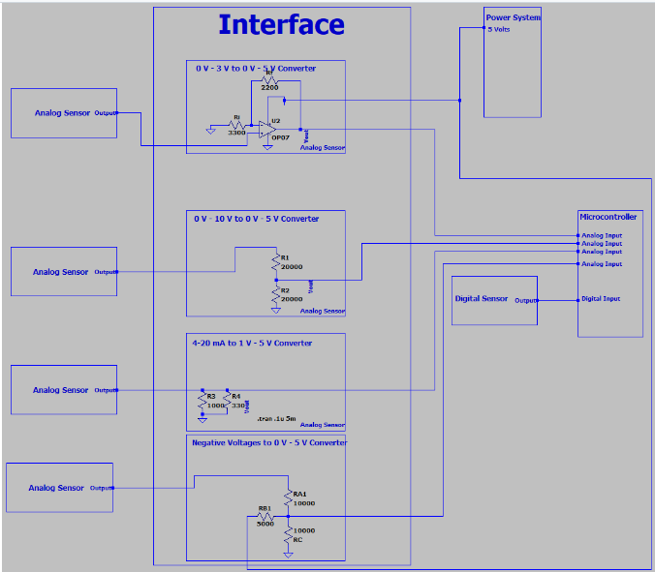
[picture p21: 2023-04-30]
Documentation/Electrical/Schematics/InterfaceSchematic.PNG

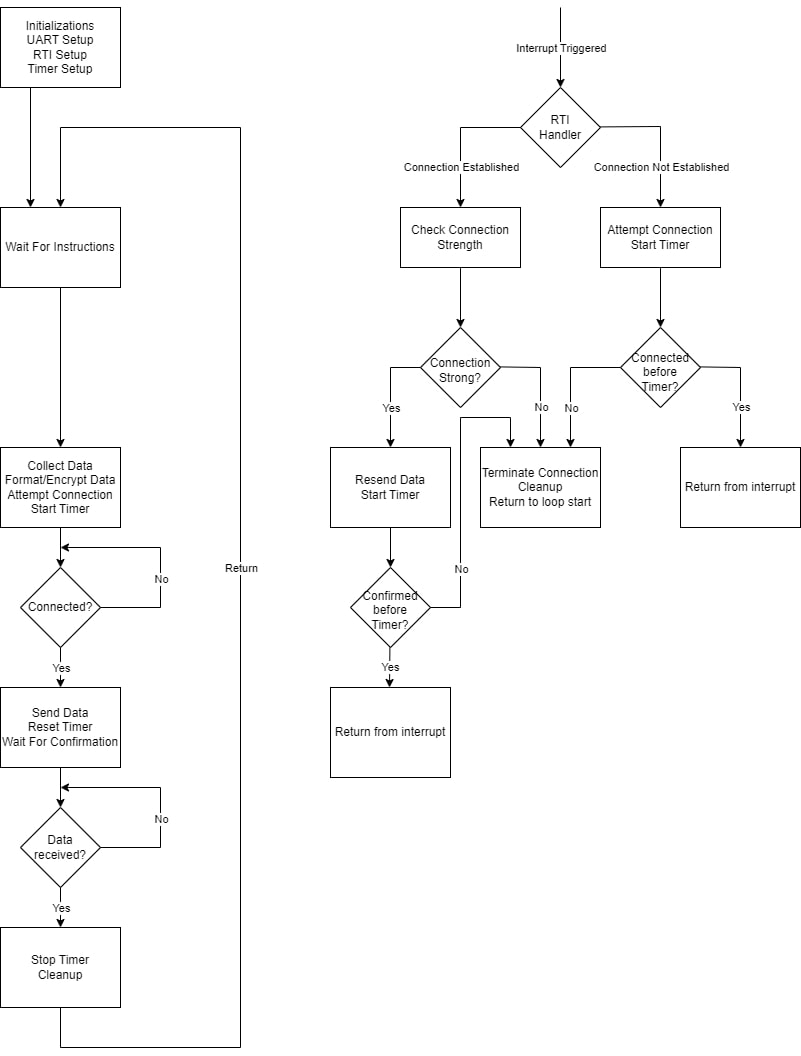
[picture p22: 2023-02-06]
Documentation/Images/Psuedo-code_Comm3.jpg

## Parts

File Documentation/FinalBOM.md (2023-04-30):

# Final BOM 
| Manufacturer | Part Number | Description | Quantity | Price per unit  |
|---|---|---|---|---|
| Hiluckey | HI-SO25 | Solar Charger 25000 mAh | 1 | $46.99 |
| ALMOCN | DA09031 | DC-DC Adjustable Step-Down Module with Digital Display Voltmeter Display 2 pack | 1 | $8.99 |
| Fonken | TP-46050200UU | 5 V 2 A wall charger 3 pack | 1 | $11.99 |
| Itramax | N/A | USB male to two female adapter | 1 | $12.99 |
| JUXINICE | N/A | Male USB to screw terminal connector 2 pack | 1 | $8.99 |
| HiLetGo | 703681358704  | HiLetGo 1PC ESP8266 NodeMCU CP2102 ESP-12E Development Board Open Source Serial Module | 1 | $7.99 |
| Analog Devices Inc. | OP07CSZ-REEL  | IC OPAMP GP 1 CIRCUIT 8SOIC | 1 | $2.31 |
| Arduino | A000067 | Arduino Mega 2560 Rev3 (Master Controller for User Interface) | 1 | $48.40 |
| Arduino | A000004 | Arduino USB Host Shield (Storage PCB) | 1 | $20.99 |

### Total: $169.64

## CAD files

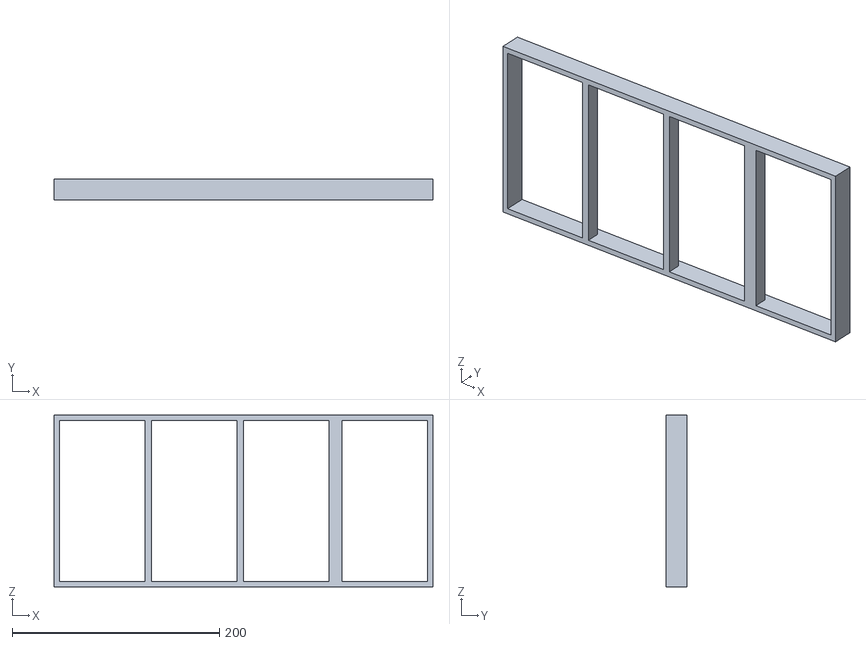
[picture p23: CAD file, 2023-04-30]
Documentation/3D Models/Part 3 for Case Rev 2 (Lid for solar panel).STL
365.8 x 20.3 x 165.7

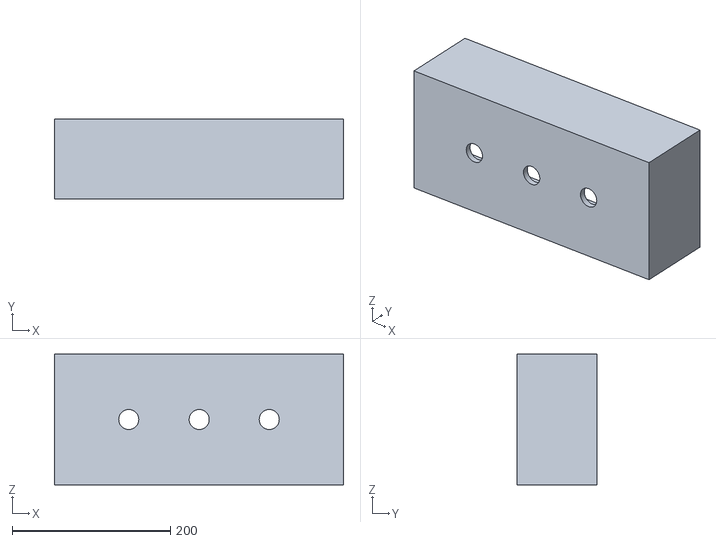
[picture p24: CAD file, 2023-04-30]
Documentation/3D Models/Part 1 for Case Rev 2 (Open Box).STL
365.8 x 101.6 x 165.7

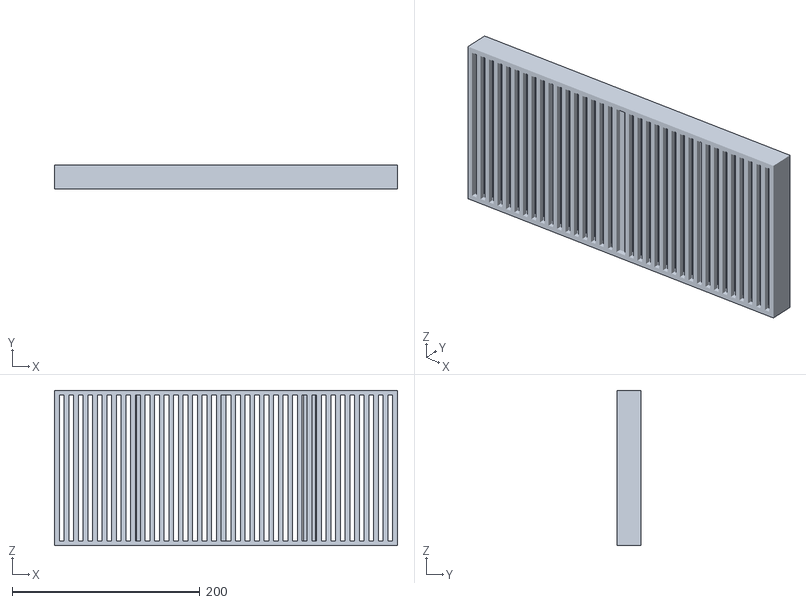
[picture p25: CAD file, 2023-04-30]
Documentation/3D Models/Part 2 for Case Rev 2 (Base for solar panel).STL
365.8 x 25.4 x 165.7

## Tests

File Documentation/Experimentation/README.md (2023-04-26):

# Experimentation
## Layout
All experimentation can be found under Documentation to Experimentation folder.  Experiments are sectioned into separate files targeting the subsystem they are most closely related to.  Each file's heading will contain the experiments performed and not performed regarding that subsystem.  Some additional notes on experiments not conducted can be found below.

Experimental Format:
1. The test description and what is being tested with how.
2. The test results in the form of a table or graph
3. Analysis of the results and consideration of their limitations on the design

## Project Goals and Fulfillments
The design has undergone considerable changes throughout its development.  There were many ambitious features that were hoped to be implemented in this iteration.  One of the biggest problems we faced was ordering parts which is naturally essential for experimentation.  In the Project Proposal, there was a list of shall statements that describe the idealized final product.  At the time of writing, here are the current beliefs about the shall statements of the project:
* Shall have a selection of tested and approved air quality sensors.
  * Due to problems with ordering, air quality sensors were never obtained.  These have had to be supplemented with other kinds of sensors.  Interfacing with an air quality sensor would not be a general issue, so the substitution is simply a change in what is being measured.
* Shall be easily replicable.
  * So far, all design aspects are available in this GitHub repository for the public.  All code and schematics for reaching above minimally functional are ready for replication.  The team has remained with off-the-shelf purchases of items that are also readily available in the open market.
* Shall be relatively cost-effective. with a budget of $300.
  * Searching through the Bill of Materials for each subsystem (excluding Sensors as descriibed in Shall statement), the total comes to $278.75 for purchasing every option.
* Shall be protected against the environment.
  * There is not currently a chasis that has been specified for purchase.  The idea is for a generic outdoors electrical enclosure to protect the electrical components.  Small holes will need to be located in a waterproof location on the box.  The team is currently investigating an open 3D printed model to place in the GitHub.  This model would be molded for the current iteration of the device.  However, neither option has been established as a definite.
* Shall be modular.
  * The current design does include many modular components: Wi-Fi, 4G, solar power, battery power, mains power, analog sensing, digital sensing, and a decently wide range of voltage tolerance for sensors to be placed.  Analog sensors even have the ability to be hot-swapped.  Digital sensors require software changes to be swapped for another.
* Shall utilize interchangeable sensors.
  * The sensors are able to interchanged with others.  Analog sensors even have the ability to be hot-swapped.  Digital sensors require software changes to be swapped for another.  Sensors have not been categorized into sampling groups due to a lack of anticipated sensors.
* Shall be able to operate with at least 3 sensors simultaneously.
  * The current iteration is able to reading from a set of digital sensors measuring gyroscopic data, temperature, and acceleration as well as an analog sensor measuring distance.  More analog sensors may be registered with ease.  Digital sensors are able to be registered with some work and understanding the data transmission from the digital sensor.
* Shall have easily accessible data.
  * Half of this statement has been met at the time of writing.  The wireless website is still under development having seen many drastic changes and shifts throughout the project.  Physical retrieval of data from the device itself has been implemented.  A user can simply plug in a regular FAT32 USB flash drive and return later with data stored safely on the flash drive. 
* Shall have a set of security measures to protect the device and its data.
  * There are no such security measures in place.
* Shall have an independent power source.
  * Development has reached the point of having several options of power sources/supplies.  Options are battery, mains, solar, battery and solar, or battery and mains.

## Measures of Success
Our Measures of Success were mostly based around the completion of our Shall Statements.  Some statements were of higher importance than others.  The other major measure was if the work could be continued from a stable point.  The biggest goal of this project was for "any Joe Schmoe" to be able to pick up the project for his/her own research/needs.  
With these in mind, it can be concluded that this project can be considered an overall failure.  The biggest contributor to this conclusion is the device's lack of completing some key Shall Statements.  The device cannot measure any of the air qualities listed.  The device has no security in place.  Sensors are not entirely interchangeable.  There are just too many things missing to really say the project has been completed in the allotted time.  There is future work to be done from a fairly decent starting point, but the foundations are there.

## Subsystem Goals and Fulfillments

### Communication
The Communication subsystem has seen much success in fulfilling its constraints. Experimentation really targets the limitations on the device's ability to communicate as many of the constraints listed in the signoff are binary answers.

What has been done:
* The device is able to connect to local Wi-Fi and access the Internet.
* The ESP8266 for Wi-Fi is within budget at $7.99.
* The ESP8266 is able to receive instructions from the Microntroller through the UART.
* ESP8266 is an extremely popular product and is still in production.

What has not been done:
* All 4G contraints have not been met.  
  * This is done intentionally as it was expected to exceed our workload with the time we were given to develop.  The 4G capabilites are possible with the specified components but are not implemented.
* Error handling has not been implemented.  
  * The idea was for the software to have a way to attempt to fix itself or run diagnostic tests on a network connection to determine what to do.  The code is running on interrupt driven programming, but the additional routines have not been developed.

### Interface
The Interace subsystem is able to fulfill each of its constraints. The experiments target the values present in the circuit given various inputs.  The goal being to insure the scaling of the input to a desired output for safe usage for the Microcontroller.

What has been done:
* The circuit is able to scale the following sensor output voltage signal ranges to 0 V to 5 V: 0 V to 3 V, 0 V to 10 V, -10 V to +10 V, -5 V to +5 V.
* The circuit is able to convert a sensor output current signal of 4 to 20 mA to a voltage signal of 1 to 5 V.
* Comprised components are non-toxic and abide by RoHS.
* The circuit does not draw more current than the Power system can provide.

### Power
At the moment, the Power subsystem is far enough along that there are options available for preference or particular situation.  This subsystem's constraints revolved around current and voltage values to provide to the rest of the device and have these values available from different methods.  Overall, this has been achieved and tested.

What has been done:
* Suitable power is able to be provided from mains, battery, battery and solar, and mains and battery.
* DC-DC converters have been tested and proven mostly functional.
  * Here, "mostly" refers to the DC-DC converters rounding issue in displayed voltage.
* Solar has been tested to provide adequate power to the device.

What has not been done:
* Extensive testing of the solar cell pack during a variety of weather conditions.  
  * The test was conducted during a typical partly cloudy day.  It is safe to assume that the solar cell would naturally due even better during sunny days, however, testing was not done for days featuring less light.  

### Microcontroller
The Arduino Mega 2560 has proven to be an apt choice for the project.  Many of the constraints have been fulfilled and are ready.  There is still much room for improvement and quality of life fixes.  Many of the constraints are binary, therefore, experimentation targets some of the limitations of the Mega regarding the current software design.  The goal being to find limiting factors and refactor the software with the results in mind.  The idea being that knowing how far the Mega can be pushed will help to understand what can be done in given amount of time.

What has been done:
* The Arduino Mega 2560 is within budget at $48.40.
* The Mega is able to instruct the USB Host Shield and ESP8266.
  * Although we intended for both to be done using UART, we ended up using some SPI for the connections made to the USB Host Shield.
* The Mega and USB Host Shield are able to log all collected data in a USB FAT32 flash drive.  
  * There are actually a couple experiments targeting the limitations of the USB Host Shield.
* The Mega has an apparent abundance of pins available for use.
* We had projections for the code to take up quite a bit of room in memory.  
  * The current version of the code only uses around 13% of the Mega's memory, so there is plenty to spare as expected.  Larger and more in-depth libraries are still able to be included for future improvements.
* The Mega is widely popular and readily available in the open-market.
* The entirety of the code is written using C++.

What has not been done:
* The code is interrupt driven, however, it does not have all the features that were hoped for.  
  * There is no error handling.  There is not a feature for measuring the battery capacity.  The idea was to check the battery capacity every so often to guage whether or not the Arduino should enter a sleep mode to protect its data.  Although the sleep mode is being developed, it is not ready for publishing.

### Sensor
Due to time constraints and unforeseen problems with the Sensor subsystem, only certain features are available.  The nature of this system was made with air quality sensors in mind of which we possess none.  Thusfar, we have been using various other types of sensors to test the device.  The sensors either worked or didn't.  If they didn't work, it was usually a coding issue.  The original idea was for the code to have a configuration file that would be set by the user to tell the device which sensors are being used.  The code would then know what settings to have and begin sampling for those sensors from a sensor group described in previous documentation.  This is no longer the case.  As the sensors never came, we are resorted to configuring the code to work with what sensors we did have.
As of now, the device can easily handle new analog sensors with a few minor tweaks to the adc registers and multiply the read values by a scale.  Digital is a different case as the information sent by digital sensors is packeted.  This means that device would need to know beforehand what the packet contains and where to read data properly.  Right now, only one packet is being read that contains temperature, gyroscopic, and acceleration data.  The format for this packet will not be the same for all others.  

What has been done:
* Multiple sensors simultaneously
  * The device is able to handle the required three sensors simultaneoulsy.  
* High sampling rate achieved
  * During microcontroller experimentation, it was found that the Arduino Mega can sample sensors at a rate of 8924 Hz.  This well exceeds the needs for most suggested sensors.  It should be noted that this number is only available when not using Wireless data storage.  See Web & Wireless below for more information.
* Hot swapping analog
  * Analog sensors can actually be unplugged and plugged in during operation.  They will work mostly as intended.  The data may be skewed due to scaling, but the data can be rescaled just the same.

What has not been done:
* Any kind of air quality sensing whatsoever.
  * It is quite difficult to sample air quality with sensors without the sensors.
* Hot swapping digital
  * The device must be told beforehand what kind of digital sensor is being used.  It must also have its code changed to conform to that new sensor.  It is not smart enough to determine this on its own.

### Web & Wireless
Due to time constraints and unforeseen problems with the Web & Wireless subsystem, only certain features are available.  These features either work or don't work so is suffices just to see if the feature works as intended.  The point of the Web & Wireless subsystem was to allow for remote access to the data via a website hosted by a deployable server.  This option has not been entirely abandoned but altered.  Now, the server aspect has been changed to be utilize public Google Services running a Google Script.  The data is stored onto a Google spreadsheet.  This can be accessed by anyone with the link and permission to the Google Sheets.  The website has been turned into a Google Site that contains the Google Sheets inside it.  This allows anyone with the link to view the data as a regular website.  
This has actually turned into a pleasant replacement for the original plans, but it still lacks some things.

What has been done:
* A website
  * Anyone with a Google account is able to create a super simple Google Site and link it to the Google Sheets for website access.  Otherwise, the Google Sheets can be accessed directly.  The Google Site shows a screenshot of the data received from the data.
* Graphical displays
  * Google Sheets inherently has built-in graphical options such as charts, graphs, plots, or diagrams.  
* Data display
  * The data is displayed in a spreadsheet and can be very easily read.  It is static on the website but dynamic on the Google Sheet.

What has not been done:
* Central server
  * There is not a central or default server that is accessible from anyone attempting to use the project for research.  Since there is not default server, there is also not a layer of security for the non-existant accounts or data.
* Deployable server
  * Although anyone can make a Google account, it still relies entirely on Google.  Independence is gone.
* Dynamic data display
  * Data displayed on the website is a static screenshot of whatever the data was in that moment.  It will not change.  The data displayed on the Google Sheets is dynamic however.  As a side note, Google Sheets has the benefit of easy chart and graphical creation.
* Fast sampling fix
  * Google has a limit on how many POST requests are allowed in a set timeframe.  This means that if the data is to be accessed remotely, the device must limit itself to a sample rate of once every five seconds.  The device needs to delay itself in order to not flood Google with POST requests that will inevitably get rejected.  A potential fix could be to increase the sample rate to the desired 2 Hz and store the data in a buffer.  Once five seconds has passed, the entire buffer could be sent to try to simulate 2 Hz sampling.  The device would then reset the buffer and begin filling it back up.  Sending a bigger POST request instead of the many small ones.

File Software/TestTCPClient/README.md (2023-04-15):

This code is for testing the functionality of a TCP Client service for the ESP8266.

### Function
1. Connect to local Wi-Fi network (presumably known by the user)
2. Wait for a piece of data to be received via UART (delimeter '\n')
3. Establish connection with server
4. Send received data using TCP socket 
5. Await for new data

### Dependent Libraries
1. Arduino Community ESP8266 library

### Installation
1. Download and install latest version of the Arduino IDE
2. git clone the required libraries
3. git clone the target file
4. Launch Arduino and open the target file
5. Set the port to target the ESP8266-Node-Module12E
6. Compile and Upload

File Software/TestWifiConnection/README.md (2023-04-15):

This code was for testing the effective range of the device's Wi-Fi connection cabalities.  

### Functions
1. Mark a time to start to connecting to a local Wi-Fi source
2. Connect to Wi-Fi
3. Mark the total time it took for the connection to be established

### Dependent Libraries
1. Arduino Community ESP8266 library

### Installation
1. Download and install latest version of the Arduino IDE
2. git clone the required libraries
3. git clone the target file
4. Launch Arduino and open the target file
5. Set the port to target the ESP8266-Node-Module12E
6. Compile and Upload

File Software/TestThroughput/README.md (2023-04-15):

This code was for testing the throughput of the ESP8266 using our device.  This is the client code for sending the alphabet as much asa possible over 1 second to a server that only receives data.

### Functions
1. Connect to the Internet via Wi-Fi
2. Connect to a generic receive server
3. Mark the time of connection and begin testing
4. Send data as fast as possible.
5. Stop after 1 second and repeat the number of transmissions made.

### Dependent Libraries
1. Arduino Community ESP8266 library

### Installation
1. Download and install latest version of the Arduino IDE
2. git clone the required libraries
3. git clone the target file
4. Launch Arduino and open the target file
5. Set the port to target the ESP8266-Node-Module12E
6. Compile and Upload

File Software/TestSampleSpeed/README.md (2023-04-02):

This code was for testing the maximum sample rate of the Arduino Mega 2560 when sampling a generic sensor.

### Functions
1. Setup the sensor and allow for warmup.
2. Mark the start time.
3. Begin sampling from the sensor as often as possible.  Increment counter each time.
4. Stop after 1 second and display the final counter results.

### Dependent Libraries
1. Arduino IDE

### Installation
1. Download and install latest version of the Arduino IDE
2. git clone the required libraries
3. git clone the target file
4. Launch Arduino and open the target file
5. Set the port to target the Arduino Mega
6. Compile and Upload

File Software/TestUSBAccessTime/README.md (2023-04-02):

This code was for testing the time it takes to access the USB Fat32 flash drive connected to the USB Host Shield. 

### Functions
1. Initialize and prepare the Fat32 for usage.
2. Creating a generic file to open on a Fat32.  
3. Mark a start time.
4. Access the file by attemtping to open it.
5. Mark the end time.
6. Close the file and display the access time in milliseconds.

### Dependent Libraries
1. Arduino IDE
2. Public USB Host Shield V2 library (additional custom version from u/greiman on GitHub)
3. UsbFat by u/greiman (Major thanks to William Greiman for his public library on Fat32 usage)

### Installation
1. Download and install latest version of the Arduino IDE
2. git clone the required libraries
3. git clone the target file
4. Launch Arduino and open the target file
5. Set the port to target the Arduino Mega
6. Compile and Upload

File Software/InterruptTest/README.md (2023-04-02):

This code was for testing the interrupt capabalities of the Arduino Mega.  The test was to see if an entirely interrupt driven version of the demo.ino was possible.
It was recreated using a timer interrupt to call for the sampling of the sensors every 1 Hz.

### Functions
1. All functions of the demo.ino needed to be recreated
2. Interrupt driven programming meant that nothing should have been in the main loop. 
3. Sampling only occurs when the timer rolls over

### Dependent Libraries
1. Arduino's SPI
2. Arduino's Wire
3. Public USB Host Shield V2 library (additional custom version from u/greiman on GitHub)
4. UsbFat by u/greiman (William Greiman developed the USBFat library that is now publicly available.  Our gratitude is great.)

### Installation
1. Download and install latest version of the Arduino IDE
2. git clone the required libraries
3. git clone the target file
4. Launch Arduino and open the target file
5. Set the port to target the Arduino Mega
6. Compile and Upload

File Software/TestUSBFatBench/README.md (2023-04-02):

This code was for testing the USB Host Shield's Writing and Read speeds to a USB Fat32 flash drive. 

### Functions
1. Initialize and prepare the Fat32 for usage.
2. Creating a generic file to write to and read from on a Fat32.  
3. Writing to the file as fast as possible while recording statistical data.
4. Read from the file as fast as possible while recording statistical data.
5. Display statistical data.

### Dependent Libraries
1. 
2. Public USB Host Shield V2 library (additional custom version from u/greiman on GitHub)
3. UsbFat by u/greiman (This test was based on the example code provided by William Greiman in is public USBFat library for Arduino.  Major gratitude for his work and generosity in sharing his testing methods)

### Installation
1. Download and install latest version of the Arduino IDE
2. git clone the required libraries
3. git clone the target file
4. Launch Arduino and open the target file
5. Set the port to target the Arduino Mega
6. Compile and Upload

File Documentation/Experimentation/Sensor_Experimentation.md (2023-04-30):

# Sensor Experimentation
* The code for these tests can be found under the software section with similar names to the test themselves

## What is Being Tested
1. Performance/Accuracy of Sensors
    - HW-123 MPU-6050 Detection Sensor
      - Gyroscope Sensor
      - Acceleration Sensor
    - Sharp 2YOA21
      - -Distance Sensor

## What isn’t being tested
1. Air Quality Sensors
    - This is due to the fact that the originally planned sensors didn’t make it through the ordering phase.

2. Sensor start-up times
    - These were taken out of consideration due to the sensors being needed not being available

3. Microcontroller communication protocol
   - This was taken out of consideration due to it being tested in the microcontroller/communication subsystem

4. Resolution of Sensors
    - This was taken out of consideration due to this test being out of the scope of this subsystem. 

## Performance of Sensors
### Sharp 2Y0A21 (Distance Sensor)  
#### Test Setup
Two Trials were done to test the accuracy of the distance sensor. The first trial used a box as the object. The second trial used a computer mouse as the object. A tape measure was set at 5 cm from the sensor. The object was placed at the opposite end of the tape measure. Every 5 cm, the object was moved. The experiment was stopped once 80 cm was reached.


Picture of Trial 1 Setup
### Trial 1
| Measured (cm) | Recorded (cm) |
| --- | --- |
| 5 | 6 |
| 10 | 10 |
| 15 | 15 |
| 20 | 18 |
| 25 | 23 |
| 30 | 29 |
| 35 | 32 |
| 40 | 35 |
| 45 | 39 |
| 50 | 43 |
| 55 | 50 |
| 60 | 57 |
| 65 | 60 |
| 70 | 57 |
| 75 | 55 |
| 80 | 50 |


Picture of Trial 2 Setup

### Trial 2
| Measured (cm) | Recorded (cm) |
| --- | --- |
| 5 | 6 |
| 10 | 10 |
| 15 | 14 |
| 20 | 16 |
| 25 | 22 |
| 30 | 25 |
| 35 | 28 |
| 40 | 31 |
| 45 | 25 |
| 50 | 21 |
| 55 | 22 |
| 60 | 21 |
| 65 | 19 |
| 70 | 16 |
| 75 | 14 |
| 80 | 13 |

- Unexpected Results:
    - During both trials, the sensor was unable to accurately detect any object within 6 cm. This is something that is known to be true about this sensor, but not being able to detect 80 cm is quite a surprise. During Trial 1, the sensor began to lose its accuracy at the 20 cm mark. The loss of accuracy continued to increase till 60 cm. At this point, the sensor completely lost all accuracy.
    - During Trial 2, the loss of accuracy happened at a quicker rate. It initially started at 15 cm and continued to increase to 40 cm. After this point, the sensor's accuracy was completely lost.
- Conclusion
    -  The Sharp 2YOA21 is not an ideal sensor to use for distance detection. The range of accuracy is between 20 - 60 cm. The sensor appears to perform better for larger objects. The sensor loses accuracy for smaller objects at a quicker rate, this is most likely due to the scope of the lens. Once again, this experiment helps simulate testing for the air quality sensors we weren’t able to obtain.

### HW-123 MPU-6050 Detection Sensor
#### Introduction
- Six different trials were done to test the accuracy of the HW-123 sensor. This sensor has the capability of getting very accurate information about the sensor's orientation. This can be done through the combination of accelerometer and gyroscope data. Both the acceleration speed and gyroscope data show how the sensor is orientated on the X, Y, and Z-Axis. 
#### Test Setup
- The way this sensor was tested was by changing the orientation 6 different times to show that the sensor is analyzing its position correctly. The sensor was rotated 90 degrees in each direction to show a multitode of orientations. Each column shows where the sensor is located on the X, Y, and Z-Axis. The accelerometer will show g (gravitational constant) in the X, Y, and Z-Axis. 

### Trial 1
- Orientation 1 (Upright)

| Acceleration X Axis (g) | Accerlaration Y Axis (g) | Accerlaration Z Axis (g) | Gyro X | Gyro Y | Gyro Z |
| --- | --- | --- | --- | --- | --- |
| \-764 | 15788 | \-1960 | 541 | \-133  | \-342  |
| \-972 | 16012 | \-2016 | 333 | \-211  | 369 |
| \-1084 | 16240 | \-2148 | 76 | 622 | \-123  |
| \-812 | 15864 | \-1880 | 688 | \-117  | \-58 |
| \-896 | 15832 | \-2184 | 249 | \-339  | 161 |
| \-1036 | 16140 | \-2088 | 243 | 664 | \-32 |
| \-868 | 15936 | \-1880 | 415 | 57 | \-279  |
| \-804 | 15796 | \-1888 | 522 | \-546  | 395 |
| \-1136 | 16100 | \-2232 | 73 | 568 | \-37 |
| \-1012 | 15876 | \-1876 | 607 | 418 | \-296  |

### Trial 2
- Orientation 2 (90 degrees rotated to the right)

| Acceleration X Axis (g) | Accerlaration Y Axis (g) | Accerlaration Z Axis (g) | Gyro X | Gyro Y | Gyro Z |
| --- | --- | --- | --- | --- | --- |
| \-15344 | \-484 | \-4784 | 283 | \-667  | \-36 |
| \-15712 | \-440 | \-4916 | 330 | \-121  | 29 |
| \-15744 | \-428 | \-5472 | 341 | \-118  | 1 |
| 15096 | \-484 | \-5592 | 329 | 1417 | 19 |
| \-15524 | \-456 | \-5872 | 387 | \-561  | 45 |
| \-15612 | \-492 | \-5808 | 365 | \-13 | 9 |
| \-15044 | \-456 | \-5592 | 387 | 193 | 35 |
| \-15576 | \-436 | \-5216 | 316 | \-534  | 42 |
| \-15832 | \-384 | \-5468 | 345 | 140 | 35 |
| \-15308 | \-400 | \-4996 | 365 | 1639 | \-23 |

### Trial 3
- Orientation 3 (180 degrees rotated to the right)

| Acceleration X Axis (g) | Accerlaration Y Axis (g) | Accerlaration Z Axis (g) | Gyro X | Gyro Y | Gyro Z |
| --- | --- | --- | --- | --- | --- |
| 692 | \-16360 | \-2128 | 347 | \-106  | 35 |
| 860 | \-16844 | \-2420 | 709 | \-12 | 74 |
| 740 | \-16436 | \-2444 | 282 | 83 | \-85 |
| 744 | \-16328 | \-2176 | 410 | 61 | 37 |
| 940 | \-16792 | \-2120 | 410 | 60 | \-43 |
| 792 | \-16632 | \-2196 | 519 | 261 | \-157  |
| 788 | \-16328 | \-2192 | 342 | 50 | 12 |
| 876 | \-16904 | \-2168 | 415 | 12 | 14 |
| 808 | \-16468 | \-2080 | 477 | 156 | \-83 |
| 752 | \-16364 | \-1908 | 157 | 86 | 42 |

### Trial 4
- Orientation 4 (270 degrees rotated to the right)

| Acceleration X Axis (g) | Accerlaration Y Axis (g) | Accerlaration Z Axis (g) | Gyro X | Gyro Y | Gyro Z |
| --- | --- | --- | --- | --- | --- |
| 17168 | \-80 | \-1764 | 362 | 212 | \-37 |
| 17052 | \-116 | \-1756 | 346 | 49 | \-26 |
| 16660 | \-188 | \-1612 | 338 | 48 | \-12 |
| 17264 | \-84 | \-1696 | 347 | 123 | \-28 |
| 16960 | \-200 | \-1776 | 353 | 109 | \-62 |
| 16540 | \-116 | \-1780 | 334 | 50 | \-22 |
| 17112 | \-136 | \-1628 | 336 | 118 | \-10 |
| 17096 | \-112 | \-1812 | 343 | 116 | \-33 |
| 16632 | \-76 | \-1724 | 349 | 13 | \-1 |
| 17264 | \-140 | \-1696 | 351 | 101 | 0 |

### Trial 5
- Orientation 5 (90 degrees rotated downward)

| Acceleration X Axis (g) | Accerlaration Y Axis (g) | Accerlaration Z Axis (g) | Gyro X | Gyro Y | Gyro Z |
| --- | --- | --- | --- | --- | --- |
| 1496 | \-640 | \-18976 | 293 | 56 | 641 |
| 1024 | \-492 | \-18496 | 336 | 72 | 3 |
| 1304 | \-492 | \-18540 | 310 | 40 | 3 |
| 1368 | \-380 | \-18984 | 190 | \-1 | 4 |
| 1100 | \-448 | \-18468 | 267 | 20 | 1 |
| 1140 | \-492 | \-18596 | 240 | 51 | 3 |
| 1288 | \-424 | \-18948 | 279 | 31 | 33 |
| 1096 | \-408 | \-18544 | 511 | 235 | 148 |
| 1152 | \-392 | \-18400 | 404 | 146 | 4 |
| 1272 | \-268 | \-19012 | 310 | 65 | 20 |

### Trial 6
- Orientation 6 (90 degrees rotated upward)

| Acceleration X Axis (g) | Accerlaration Y Axis (g) | Accerlaration Z Axis (g) | Gyro X | Gyro Y | Gyro Z |
| --- | --- | --- | --- | --- | --- |
| \-1408 | \-944 | 15012 | 87 | 11 | \-53 |
| \-1308 | \-924 | 14288 | 401 | 147 | \-19 |
| \-1532 | \-1612 | 14888 | 338 | \-38 | \-78 |
| \-1364 | \-1000 | 14832 | 113 | 39 | \-30 |
| \-1368 | \-848 | 14324 | 445 | 160 | \-2 |
| \-1424 | \-1380 | 14732 | 315 | 59 | \-15 |
| \-1484 | \-980 | 14868 | 125 | 23 | \-45 |
| \-1328 | \-804 | 14292 | 399 | 90 | 14 |
| \-1416 | \-1420 | 14852 | 473 | 67 | 15 |
| \-1528 | \-1092 | 14940 | 113 | 32 | \-25 |

- Unexpected Results:
    - After analyzing the Trials, we can see that the digital sensor is in good condition. The accuracy of this sensor is substantially better than the Sharp sensor. The values for the X, Y, and Z axis in acceleration show that the sensor properly analyzes where it is on the coordinate plane.

- Conclusion
    -  The HW-123 is an ideal sensor to use for sensor orientation. Due to the inability to test temperature, we aren't able to test all of its abilities. Once again, this experiment helps simulate testing for the air quality sensors we weren’t able to obtain.

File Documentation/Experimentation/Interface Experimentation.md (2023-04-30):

# Interface Experimentation 
## Included Test Specifications
* Conversion of the following voltage ranges to 0-5 V: 0-3 V, 0-10 V, -10 V to +10 V, -5 V to +5 V and read the output voltages from the ADC.
## Excluded Test Specifications
* Components must be RoHS compliant
  * Components chosen have gone through thorough testing for hazardous components to be listed as RoHS compliant and therefore I will not be testing this myself.
* Interface must run off of 5 V
  * 5 volts will be provided from the power subsystem to components requiring voltage which does not warrant testing.
* Interface analog current sensors with the Arduino ADC
  * We do not have access to any current sensors or any substitutes. 

## 0 to 3 V to 0 to 5 V Converter
### Trial One
| Input Voltage(V) | OutputVoltage (V) | 
| --- | ---|
|0	 |1.19|
|0.5	 |1.19|
|1	 |1.64|
|1.5 |	2.55|
|2	 |3.41|
|2.5 |	4.26|
|3	 |4.26|
### Trial Two
| Input Voltage(V) | OutputVoltage (V) | 
| --- | ---|
|0|	1.19|
|0.5|	1.19|
|1|	1.7|
|1.5|	2.59|
|2|	3.48|
|2.5|	4.26|
|3|	4.26|
### Trial Three
| Input Voltage(V) | OutputVoltage (V) | 
|---|---|
|0|	1.19|
|0.5|	1.19|
|1|	1.77|
|1.5|	2.61|
|2|	3.35|
|2.5|	4.26|
|3|	4.26|
### Trial Four
| Input Voltage(V) | OutputVoltage (V) | 
| --- | ---|
|0|	1.19|
|0.5|	1.19|
|1|	1.77|
|1.5|	2.51|
|2|	3.44|
|2.5|	4.17|
|3|	4.26|
### Trial Five
| Input Voltage(V) | OutputVoltage (V) | 
| --- | ---|
|0|	1.19|
|0.5|	1.19|
|1|	1.78|
|1.5|	2.62|
|2|	3.42|
|2.5|	4.22|
|3|	4.26|

* Test Setup: 
  * Circuit was set up using the circuits lab power supplies with channel set to 5 V and sent to the 
power supply pin to represent the 5 V signal coming from the power subsystem, then channel 2 
set to various voltages in between 0 V and 3 V representing the sensor output voltages that 
become the interface inputs. The circuit has a current draw of 10 mA, so the current knob on the 
power supply was set accordingly to ensure the circuit does not draw more current than allowed. 
The output of the circuit was then connected to pin A0 of the Arduino and the resultant voltage 
from the ADC was then read for each input voltage.
* Unexpected Results:
  * For an input voltage of 0, the expected output voltage is 0 but instead it is 1.19 V. This is due to a phenomenon called common-mode rejection. For a 0 V signal to 2nd and 3rd pin inputs of the amp, a non-zero output voltage of above 3 was recorded. For ideal operations, op amps amplify the difference between the input voltages so if there is no difference the output should be 0. However, due to the feedback resistors current is being leaked back to the 2nd pin input creating a voltage difference between the two inputs that gets amplified and shown on the output. 
* Conclusion
  * Due to common mode rejection, this circuit will convert a 0 - 3 V output to about 1- 5 V. This 
will not result in a loss of data but instead a loss in ADC resolution. 

## 0 to 10 V to 0 to 5 V Converter

### Trial One
| Input Voltage(V) | OutputVoltage (V) | 
| --- | ---|
|0|	0|
|1|	0.51|
|2|	1.03|
|3|	1.51|
|4|	2.03|
|5|	2.54|
|6|	3.04|
|7|	3.53|
|8|	4.04|
|9|	4.55|
|10|	5|

### Trial Two
| Input Voltage(V) | OutputVoltage (V) | 
| --- | ---|
|0|	0|
|1|	0.53|
|2|	1|
|3|	1.52|
|4|	2.01|
|5|	2.51|
|6|	3.04|
|7|	3.51|
|8|	4.03|
|9|	4.53|
|10|	5|

### Trial Three
| Input Voltage(V) | OutputVoltage (V) | 
| --- | ---|
|0|	0|
|1|	0.5|
|2|	1.02|
|3|	1.51|
|4|	2|
|5|	2.52|
|6|	3.03|
|7|	3.62|
|8|	4.02|
|9|	4.52|
|10|	5|

### Trial Four
| Input Voltage(V) | OutputVoltage (V) | 
| --- | ---|
|0|	0|
|1|	0.52|
|2|	1|
|3|	1.52|
|4|	2|
|5|	2.52|
|6|	3.05|
|7|	3.51|
|8|	4.02|
|9|	4.52|
|10|	5|
### Trial Five
| Input Voltage(V) | OutputVoltage (V) | 
| --- | ---|
|0|	0|
|1|	0.53|
|2|	1.02|
|3|	1.52|
|4|	2.01|
|5|	2.52|
|6|	3.03|
|7|	3.52|
|8|	4.06|
|9|	4.53|
|10|	10|

* Test Setup: 
  * Circuit was set up using the circuits lab power supplies with channel set to 5 V and sent to the 
power supply pin of the op amp to represent the 5 V signal coming from the power subsystem, 
then channel 2 set to various voltages in between 0 V and 10 V representing the sensor output 
voltages that become the inputs to the interface. The circuit does not draw power/current from the 
sensor or power supply as it is just a voltage divider. The output of the circuit was then connected 
to pin A0 of the Arduino and the resultant voltage from the ADC was then read for each input 
voltage.
* Unexpected Results:
  * Testing showed expected results
* Conclusion
  * Circuit works as expected without any data or resolution loss and is therefore successful. 
## -5 to 5 V to 0 to 5 V Converter
### Trial One
| Input Voltage(V) | OutputVoltage (V) | 
| --- | ---|
|-5|	0|
|-4|	0.51|
|-3|	1.03|
|-2|	1.53|
|-1|	2.01|
|0|	2.48|
|1|	2.59|
|2|	3.47|
|3|	4.02|
|4|	4.52|
|5|	5|
### Trial Two
| Input Voltage(V) | OutputVoltage (V) | 
| --- | ---|
|-5|	0|
|-4|	0.51|
|-3|	1.04|
|-2|	1.53|
|-1|	2.03|
|0|	2.51|
|1|	2.59|
|2|	3.46|
|3|	4.01|
|4|	4.51|
|5|	5|
### Trial Three
| Input Voltage(V) | OutputVoltage (V) | 
| --- | ---|
|-5|	0|
|-4|	0.53|
|-3|	1.04|
|-2|	1.51|
|-1|	2.02|
|0|	2.5|
|1|	2.57|
|2|	3.47|
|3|	4.01|
|4|	4.5|
|5|	5|
### Trial Four
| Input Voltage(V) | OutputVoltage (V) | 
| --- | ---|
|-5|	0|
|-4|	0.54|
|-3|	1.05|
|-2|	1.53|
|-1|	2.03|
|0|	2.53|
|1|	2.56|
|2|	3.48|
|3|	4|
|4|	4.52|
|5|	5|
### Trial Five
| Input Voltage(V) | OutputVoltage (V) | 
| --- | ---|
|-5|	0|
|-4|	0.52|
|-3|	1.03|
|-2|	1.51|
|-1|	2.01|
|0|	2.49|
|1|	2.55|
|2|	3.47|
|3|	4.02|
|4|	4.51|
|5|	5|

* Test Setup: 
  * Circuit was set up using the circuits lab power supplies with channel set to 5 V and sent to the 
power supply pin of the op amp to represent the 5 V signal coming from the power subsystem, 
then channel 2 set to various voltages in between -5 V and 5 V representing the sensor output 
voltages that become the inputs to the interface. The circuit does draw current from the 
sensor or the power supply used as a substitute, and it comes out to about .03 mA. Current knob 
was adjusted accordingly to ensure the power supply did not supply more than .03 mA. The 
output of the circuit was then connected to pin A0 of the Arduino and the resultant voltage from 
the ADC was then read for each input voltage.
* Unexpected Results:
  * Testing showed expected results
* Conclusion
  * Circuit works as expected without any data or resolution loss and is therefore successful. 
## -10 to 10 V to 0 to 5 V Converter
### Trial One
| Input Voltage(V) | OutputVoltage (V) | 
| --- | ---|
|-10|	0|
|-7|	0.72|
|-4|	1.48|
|-1|	2.24|
|0|	2.51|
|1|	2.74|
|4|	3.49|
|7|	4.27|
|10|	5|
### Trial Two
| Input Voltage(V) | OutputVoltage (V) | 
| --- | ---|
|-10|	0|
|-7|	0.72|
|-4|	1.47|
|-1|	2.22|
|0|	2.55|
|1|	2.76|
|4|	3.5|
|7|	4.27|
|10|	5|
### Trial Three
| Input Voltage(V) | OutputVoltage (V) | 
| --- | ---|
|-10|	0|
|-7|	0.72|
|-4|	1.47|
|-1|	2.24|
|0|	2.51|
|1|	2.75|
|4|	3.5|
|7|	4.27|
|10|	5|
### Trial Four
| Input Voltage(V) | OutputVoltage (V) | 
| --- | ---|
|-10|	0|
|-7|	0.69|
|-4|	1.48|
|-1|	2.23|
|0|	2.55|
|1|	2.76|
|4|	3.51|
|7|	4.27|
|10|	5|
### Trial Five
| Input Voltage(V) | OutputVoltage (V) | 
| --- | ---|
|-10|	0|
|-7|	0.7|
|-4|	1.46|
|-1|	2.23|
|0|	2.51|
|1|	2.75|
|4|	3.51|
|7|	4.28|
|10|	5|

* Test Setup: 
  * Circuit was set up using the circuits lab power supplies with channel set to 5 V and sent to the 
power supply pin of the op amp to represent the 5 V signal coming from the power subsystem, 
then channel 2 set to various voltages in between -10 V and 10 V representing the sensor output 
voltages that become the inputs to the interface. The circuit does draw current from the 
sensor or the power supply used as a substitute, and it comes out to about 1 mA. Current knob 
was adjusted accordingly to ensure the power supply did not supply more than 1 mA. The 
output of the circuit was then connected to pin A0 of the Arduino and the resultant voltage from 
the ADC was then read for each input voltage.
* Unexpected Results:
  * Testing showed expected results
* Conclusion
  * Circuit works as expected without any data or resolution loss and is therefore successful. 
## Arduino,Interface and Code Experimentation Setup Picture



## Arduino Source Code for Voltage Reading from the ADC

VoltageReadingCode

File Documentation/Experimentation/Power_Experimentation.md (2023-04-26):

# Power System Experimentation

## What is being tested?
1. Current draw of the system with and without sensors
2. Recharge capabilities of the solar cell
3. Voltage output for the DC-DC convertor 
## What isn't being tested?
1. Ability to operate on battery and AC mains input
    *  Was shown during minimum functionality prototype 
## Test 1 
### System Current Draw
For this test, the power input of the microcontroller will be supplied with 5 V and a DMM set to measure
current will be placed in series at the positive input. 1200 samples over 10 miniutes will be taken and logged. This will be reapeated four times. The test will be run again with the sensors disconnected in order to establish the current draw independent of the sensors.
### Graphs
FourTests
AverageCurrent

Current Consumption without Sensors-2
### Explanation
The above tests show the current draw over ten minutes while the system is operational. The results show that using 
the sensors causes the current to fluctuate regularly around 228 mA. 

The slight negative slope can be 
attributed to the high initial current consumption shown in the test running just the microcontroller. 

Also observed was how consistent the Arduinos’ power draw is with minimal variance about the average 
current of 199 mA.

The maximum current draw observed during operation with the sensors was 234.43 mA while the minimum value was 222.18 mA. 

Using the largest currernt draw observerd and the 5 V input, we get a power requirement of 1.17215 W. Using this worst case power requirements and the capacity of our battery (92.5 Wh), we can show that our device will run for 78.91 hours with no further charging from 
the solar cell. 
Using the average current draw of 228 mA gives a power draw of 1.14 W. This gives a use 
time of 81.14 hours.
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

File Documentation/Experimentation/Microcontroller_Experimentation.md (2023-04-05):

# Microcontroller Subsystem Experimentation
* The code for these tests may be found under the Software section with similar names to what the test is covering.

### What Is Being Tested
1. USB Read/Write Speed
2. USB Access Time
3. Sampling Speeds

### What Is Not Being Tested
* Pin count
  * It is not necessary to test the pin count as it is evident that enough pins are available.
* UART
  * UART is inherently required to be able to flash the Arduino Mega.  It either works or doesn't work.  Here, the board was able to flash and therefore works.
* Signal connections from other subsystems are expected to work
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

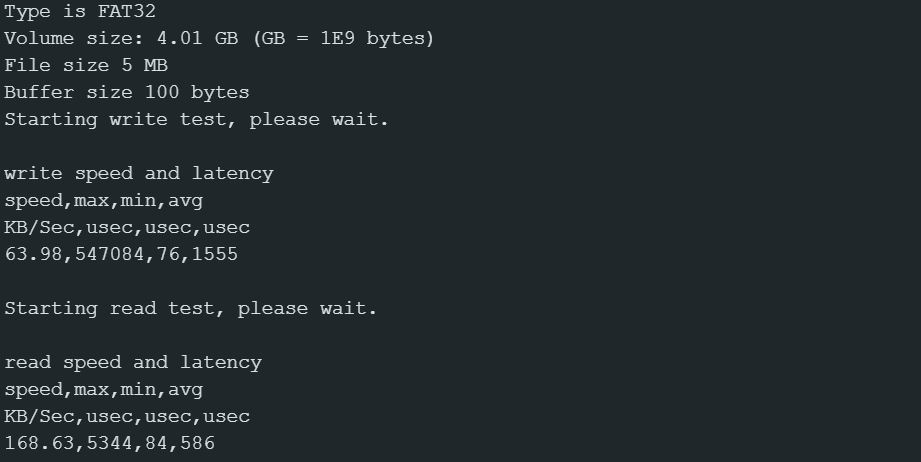
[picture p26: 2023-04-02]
Documentation/Images/USBWriteReadSpeedTestOutput.JPG

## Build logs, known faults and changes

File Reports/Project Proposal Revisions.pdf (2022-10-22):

# Citizen Air Quality Sensor

Joshua Egwuatu, Kaleb Irwin, Cameron Smith, Alejandro Moore, Marvo Odds

Computer and Electrical Engineering Department at Tennessee Technological University

115 W. Tenth St., Cookeville, TN 38505

Jiegwuatu42@tntech.edu, kjirwin42@tntech.edu, casmith51@tntech.edu, aamoore42@tntech.edu, modds42@tntech.edu

Abstract—Finding air quality data on general regions is simple and readily available to the public; however, procuring data for a local area can be challenging. This paper proposes a new device capable of sampling desirable air quality data. The device will be intended for use by local citizens, communities, or researchers with limited electrical engineering knowledge. This paper will also discuss why air pollution should concern the modern world and how its current technology can be used for this project.

Keywords—Air Quality Sensor, Replicable Sensor Design, Community Atmospheric Science, Air Pollutant Sampling, Modular Sensing System Architecture

I. INTRODUCTION
Pollution is a matter that should be fully recognized by society. Air pollution at high levels can cause a variety of adverse health risks. Some examples include heart disease and lung cancer [1]. Even with knowing this, most people don’t look into how pollution affects them in their community. The team’s goal is to allow people the option to see what pollutants affect them in their communities. The objective is to create an easy-to-use, solar-powered, easily replicable, and low cost modular system that uses multiple sensors to gather data on different pollutants. The data will be easily accessible online for users to decide how to combat pollution in their community..

II. FORMULATING THE PROBLEM
The modern world has sometimes experienced unhealthy or even deadly levels of pollutants in the very air humans breathe [2]. Finding local information on air quality is based on algorithmic calculations [3]. There are plenty of resources to make guesses, but accurate air quality measurements are challenging to come by despite the technology in some forms. Services such as weather apps on phones and PCs (Personal Computer) give information about air quality and primary pollutants; however, this is based on an average of sensors placed around a large area such as a county [4]. It is this averaging that does not allow for true readings from any arbitrary chosen location. These currently used apps and algorithms will not do the job for a single person or community attempting to gain information from a specific location and those who would like only to gain information about certain pollutants that may not be commonly measured. The obstacle for local measurements of very customized intakes is that the technology may exist, but it is not compiled to fulfill this need.
A. Background Information
The background check includes air quality sensors themselves, the effects of contaminated air, and how expected values are obtained.

Air contamination refers to chemicals or particles in the air that can harm the health of humans, animals, or plants [7]. Common qualities to measure are carbon monoxide, lead, nitrogen oxides, ozone, particulate matter, and sulfur dioxide [8]. Particulate matter (PM) is of interest given the area of testing is Cookeville, TN as PM 2.5 is a common type of air pollution found in the area [9]. Knowing this, there are a great many health concerns that could be revealed when testing the air quality. From the National Geographic team, “Long-term health effects from air pollution include heart disease, lung cancer, and respiratory diseases such as emphysema. Air pollution can also cause long-term damage to people's nerves, brains, kidneys, liver, and other organs. Some scientists suspect air pollutants cause birth defects” [1]. If the proposed device can reveal these pollutants in local communities, many could be saved from undesirable health risks or even death.

Air quality sensors are devices used to detect levels of contamination in the air [5]. The inner workings of air sensors vary widely, from lasers that measure the size and number of pollutants to the ultrasonic disruption from sending out sound waves that bounce off pollutants, counting each bounce as another pollutant to add to the total [6]. The sensors take their measurements and then convert them to an electrical signal regardless of the method the data was gathered [6]. It is here where the proposed device comes into play to read this electrical signal to convert it into an easier-to-read format. So, knowing how the sensor functions are essential, but for the interest of the project, the conversion and formatting are the focus.

The U.S. government and some companies provide information on air quality regarding an area through weather apps. These apps source their information from sensors placed around the region being tested. These sensors are placed both systematically across the country and in highly populated locations. Algorithms are then used to average and guess the air quality of regions in between the sensors [4]. Think of it like a vast web with gaps between the strings that are filled in after the web is made. For general use, this is fine, however, for someone wanting to use accurate data in their research, this will not do. Having access to the proper air quality data would allow for a more accurate groundwork for any point trying to be proven. This is whether to prove the air quality around a particular area is harmful or that the expected values are misleading, whatever the case..

B. Specifications and Constraints
The specifications and constraints placed upon the construction and design of the project:
- Shall have a selection of tested and approved sensors to cover a range of pollutants, particulates, air composites, and other qualities. Common qualities to measure are carbon monoxide, lead, nitrogen oxides, ozone, particulate matter, and sulfur dioxide. Other qualities may be selected in the future, but these are definite qualities to look for. These sensors should work independently from each other.
- Shall be easily replicable. The device and additional components shall be mostly, if not entirely, off-the-shelf purchases. This should lower the technical knowledge required to construct the device tremendously. The software should be available for free online on GitHub. Software licenses will be included depending on which software is chosen and used.
- Shall be well documented to answer common questions about the functionality of the device. All questions cannot possibly be answered; however a very strong groundwork for how the device operates and essential functions with limitations shall be documented on GitHub. This should answer common questions that may arise.
- Shall be relatively cost-effective. The device, additional components, and software should remain under $300. The cost of sensors is not taken into account as the sensors are used on a case-by-case basis.
- Shall be protected against the environment. The standard to be followed for water resistance will be IPX4, protecting from all directions against the rain. The standard to be followed for dust and small objects will be IP3X which states protection against hazardous parts, thick wires, or solids of sizes greater than 2.5 mm. The device will operate in a temperature range of 10°F to 90°F. This covers a wide and likely temperature range seen in the U.S. The device will also be staked into the ground and resist wind speeds up to 74 mph.
- Shall be modular. In this instance, modularity refers to the ability to change to a multitude of previously tested and compatible sensors without the need to change any or at most 2 select settings. The change of sensor should be seamless and handled by the board and software.
- Shall utilize sensors that are interchangeable. The sensors will have multiple kinds of Input/Output (I/O) ports, so a list will be made that acknowledges all I/O ports of sensors to be approved and tested. The I/O ports that are shared among a group of sensors should be able to operate seamlessly if swapped out from the same type of I/O port for another sensor in the group using that I/O port. Sensors that do not share this I/O port will have a port of its own grouping that has this same functionality within that group.
- Shall be able to operate with at least 3 sensors sampling independently of each other. Sensors will take samples at set intervals and be read and stored on the device periodically. Samples may be received and outputted one at a time.
- Shall have easily accessible data. The device should be able to take data from storage and send it to a website to be read by the user remotely. This transfer of data will follow Transmission Control Protocol (TCP) and IEEE 802.11. If the user wishes, he/she may also read data from the device directly. Formatting will be basic and leave room for improvement for future development.
- Shall have a set of security measures to protect the device and data. The data shall be encrypted with an undisclosed algorithm. This is during transmission encryption and encryption during the storage of the data on the board. The chassis will be made of a material to be reasonably impact resistant at the standard of IK08. This standard rates the device at 5 Joules of impact. A global positioning system will also be added to aid to reclaiming during loss or theft.
- Shall have an independent power source. The device should be able to be planted somewhere and operate with an onboard power supply. This power supply may include two major components, a solar cell pack and or a rechargeable battery pack. The battery pack should be able to maintain the device for at least 24 hours without recharging. If the solar cell pack is included, the solar cell should allow for charging of the battery pack and prolong the life expectancy.

These are the specifications to be met when constructing and designing the project. They are absolute statements. It should be noted however, that given the status of the team as undergraduate students, the project may falter in regards to certain projections i.e. knowledge, time, and resources. Realistic goals are at present set, but, due to the unpredictability of the future, these goals may change.

C. Surveying Solutions
Research concludes that: air sensors are not typically used in an interchangeable way, but other sensors are, some multi-use air sensors have been made but have limitations, modular microcontrollers can be used to fulfill the project needs when modified, and air quality checks are public information given by companies.

The technology of today already includes a large variety of air quality sensors. The issue with these sensors is their inherent simplicity. One sensor can be used for its particular task, but if the user wanted to use air sensors, these could not be interchanged. The housing unit, or chunk of material the sensor is attached to, will never change or work for another kind of air sensor. This is one issue that needs to be addressed. A core goal for the project is to allow for interchangeable air sensors. This means that the housing unit must accept many different types of air sensors with hand-selected I/O types, implying here that some I/O’s will be different than others. The I/O types will be grouped and work interchangeably within its group. The technology to do this exists, but it has not been compiled together in this way. For example, the company Ellab makes vacuum, pressure, and temperature sensors that all use the same connections and may therefore be used interchangeably [10]. These sensors also sport a wireless data logging system, however, with all these advantages comes a high cost with some basic kits being over $750. One of the “Pro Temperature Recording” kits sold for $2900. Their methods may be incorporated for subverting this issue but avoiding the high price will be a priority.

A piece of existing works to consider is the air quality sensors providing regional information for large portions of the world. A big example is the Air Quality Index (AQI) provided by the U.S. Environmental Protection Agency. The AQI takes information from sensors placed in key locations around the United States to make assumptions about the air quality for a certain area using sophisticated algorithms [3]. This may sound like the problem is already solved in this case, but this project seeks to get true local results. The algorithms used can only make guesses. Bypassing the algorithms and jumping straight to the raw data will provide a true local reading for the air quality around a designated region.

Another solution from today sees that air sensors already exist with the ability to measure a range of pollutants, particulates, or compositions in the air. The company Airly Inc. produces a device called Airly PM. [11]. This device is capable of measuring many pollutants and particulate matter all in one easy to use device for $100 to $300 in monthly rent. So, multiple kinds of sensors can be used simultaneously on one device, however, this device comes with a preset of sensors that cannot be altered or customized. If the user wanted to measure something not included in the preset, this would not be possible. This was likely to stay in the realm of “easy to use”. Finding a balance of easy to use and having a variety of sensors is one target for the project. More options could inadvertently confound the user and should be avoided. This does limit the user in what can be measured and discovered.

Finally, other works to consider are Arduino and Raspberry Pi which are popular microcontroller boards that allow for modularity[12] [13]. The problem inherently requires modular components, so the existence of these boards does allow for an off the shelf option. This allows for a more simple user interface which ultimately does make the product more accessible to more people. Lowering the knowledge requirement for constructing this device potentially allows more to be built and hopefully improved for future use around the world. The concept of this device being easy to make, easy to use, lower cost, and give sufficient data is a driving factor when making a community-friendly product.

III. LOOKING FOR SOLUTIONS
The task of having a port designed as input to use a desired sensor interchangeably is difficult to solve. Finding an adapter that can be integrated into the system can solve this issue. Since there are many different pollutants, one goal is to make the air quality device to house 3 different pollutants and receive informative data on each at the same time. Even though it will be able to send current-time data for 3 pollutants, the device shall be able to house sensors for 8 pollutants in total.

Another potential issue that may hinder the replicability is using custom components within the device in order to achieve requirements. It has already been stated that one goal is for the air quality sensor to be easily rebuildable and low cost. Therefore, custom products that may be difficult to remake or design are not to be used during the development of this project. Not every customer is likely to be savvy in electronics and have detailed understanding of making PCB’s, soldering connections and devices, coding hardware to assign I/O ports, reading electronic schematics, knowing electrical behavior, and etc. Arduino or Raspberry Pi products can solve interface issues and system user control. Microcontrollers that can communicate using SPI, I2C, or UART to other receiving microcontrollers can be useful for the functionality of this device.

A. Unknowns
Accounting for the future and all hindrances that may follow is not feasible. Best predictions and how to approach them:
1) Certain sensors share an I/O group with approved sensors but still will not work.
a) In this case, the sensors that are approved have already been grouped and listed. Using a sensor that is not approved but similar will not guarantee a successful sampling of data. This could be fixed with a software update. However, this fix is considered tedious and not long-term.
2) A team member is inhibited from completing designated workload.

a) Other members of the team will divide the designated workload amongst each other.
3) The microcontroller board has an element that hinders progress that was unforeseen.
a) What this means is that the selected board has a limitation that wasn’t discovered or apparent. In this case, the team should do plentiful research on the board to investigate workarounds or modifications. If this does not solve the issue, then another board will have to be chosen.
4) The supply chain industry withholding ordered parts/materials thus stretching the projected timeline.
a) Members searching for parts to order must judge the quantity present and required.
5) The multi-variant virus called COVID may slow down the design process.
a) This could not only impact the manufacturers that the team may be interested in buying a product, but also each team member’s health has the potential to be compromised if any have the virus.
Predicting the future takes into calculation far more variables than can be accounted for. Knowing this, there are things that can be done to minimize the risk of failure: consistent updates from members, asking for help when it is needed, seeking outside knowledge, performing thorough research, allowing time for sufficient experimentation, and designating one member to allot time for tasks.

During experimentation, the goal should be to find the most effective design regarding costs, effort in construction, and completion following the measures of success. It should be noted that during experimentation, not all effects could be found. This is to say that some effects of the device could be unintentional, although, it is highly unlikely considering the nature of the device, but this is still worthy of mentioning. These effects cannot be specified at this time due to them falling under the unknowns of the project. If these unknowns were to affect the measures of success, then a potential design modification would be required.

B. Measure of Success
Measures of success for this project will be the fulfillment of the previously mentioned shall statements to the best of the team’s abilities. Failure to complete the shall statements does lower the overall success of the project, however, certain specifications are considered critical. If the device fails to measure three out of the six qualities, it will be considered a critical failure in design and cannot be overlooked. If the device fails to resist wind speeds of 74 mph, that can be considered negligible losses. The case by case nature of this measure will mean that approval by the customer throughout each step of adding/adjusting/removing the shall statements will be necessary.

Seeing as this design is going to be public, seeing the design well-received will prove a successful job. Knowing that there are persons or groups that appreciate the work done and utilize it show that the effort placed into the project is not folly. Even if the project is in the end considered incomplete but still a great foundation for related future projects would still be a success. Seeing teams in the future use this project’s documentation and designs as a basis for an improved air quality sensor would be a good sign. Maybe even an app could be created that pairs with the device to allow an easier time reading, receiving, or manipulating the data. Recognition from other projects such as citations or acknowledgements are welcome as well. Although the goals are set and it is desirable to fully realize them, there are alternative investments that are being made for future generations in the completion of this project.

C. Ethics and Responsibility
This design team shall follow National Electrical Code safety procedures, associated National Fire Protection Agency procedures, and abide by piracy laws. There are no intentions to break any laws established by the United States of America Government. All patents, licenses, and copyrighted material will be used under legal fair use with citations and credit when appropriate. This product will be designed in such a way to prevent risk and unintended harm to the users, the communities, and the environment.

This product will be designed with the IEEE code of Ethics in mind and follow common electrical concepts/standards: resistor color codes, design schematics, communication between devices, etc.

The only foreseeable harm that could be caused by the proposed device is the ignition of an electrical fire. The risk of this will be minimized during design. A wild fire could prove devastating to an environment and will need to be avoided as responsible engineers would. Hazardous materials and potential harm to the user are otherwise non-existent. Potential negative impacts on communities or persons are negligible, if any exist, given the nature and purpose of the device. In theory, communities will be improved by the use of the proposed device in that they will be able to see if the air quality in their homes, work places, and schools is safe for adults and children alike.

IV. RESOURCES
Resource listings here are speculation for what tools, software, components, testing equipment, and software may potentially be required to complete the project.
- Visual Studios, Notepad++, or some other type of code editing software.

- Microcontroller integration software to program any boards that may be used.
- Microcontroller boards such as the Arduino or Raspberry Pi boards. Currently unknown model.
- Port modules to be added to related microcontroller boards.
- Standard electrical lab equipment: multimeter, oscilloscope, etc.
- Hand selected air quality sensors. This is to be determined later when a standard for I/O ports has been made.

Time is another resource that must be considered. The project is to be completed over the course of two semesters. Estimating the hurdles and objects to pass, the allotted time should be sufficient to create a prototype of the device and allow for future development, because of the scheduled timeline planned within the given time period.

The last resource to consider is the budget. Although the budget for design is much higher, in order to stay in line with the goal of having a low-cost construction, the prototype should be constructed out of materials with a monetary value under $300. Given that Raspberry Pi and Arduino boards can range from $10 to $80, further research into the most cost-effective option will need to be completed. Other resources are for designing the device itself as the software will be available for free online. The sensors themselves are not taken into consideration as the cost changes case by case.
A. Personnel
There are many different aspects of electrical, computer, and mechanical engineering that will be implemented within this project. As such, in order for the specifications to be met and shall statements verified, there is a need to use an ample amount of time in research, design concept, and experimentation. Looking at various sensors and product standards will be some of the things that will be looked into. Finding the correct component/circuit/ or system will be a major factor towards the development process.

All of the members on the team have studied over various circuits and how to implement them to do what the developer wants it to. Alejandro Moore, has had some experience in PCB circuit design, analysis, and manufacturing. Knowing what is the correct component to the system and analyzing how it should be used are things that will be needed in order to understand and record the design process. He has also had some experience in BNC cable installation and other types of wires. Learning these concepts has given a plethora of resources that can be shared with the team if needed. He is aware that the team members have other skills that can also be used within this project. This is beneficial for the functionality of the team, because it can help the others learn the concept and further the process of the project.

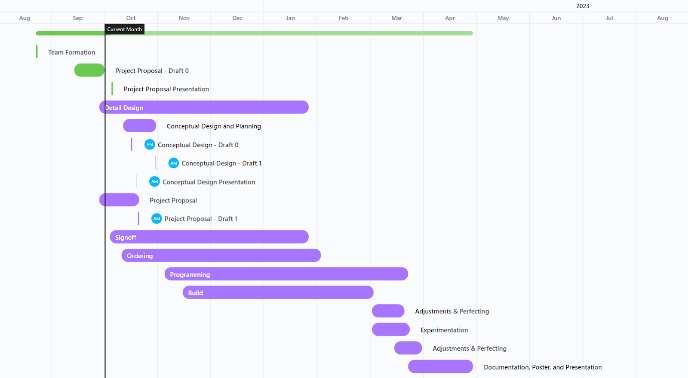
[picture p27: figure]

Marvo Odds has had many experiences in digital logic projects,circuit design and coding projects. Many of these experiences came in the form of projects from classes at Tennessee tech such as coil gun circuit, digital logic circuit that implemented the game Ship,Captain,Crew, and coding projects in CSC 1300 that used C++. This is beneficial because the design will need knowledge in circuit design and coding to implement the website and databases.

The skills that Cameron Smith brings to the team are familiarity with C, C++, VHDL, and assembly coding languages, programming microcontrollers, digital design, circuit analysis, and client/server communication design.

Joshua Egwuatu has had experience in the field of engineering. He understands the design process in its completion from start to finish. He also has experience in C++, Solidworks, Altium, and web design. Due to the need of having to export data collected to a website, web design knowledge will contribute a lot. He also has a strong background in leadership and communication due to the many roles held in his academic career. This skill set should be very beneficial for the team.

Kaleb Irwin has experience in coding primarily in C++, and a little bit in HTML as well. He also has worked with microcontrollers before and designed several small projects throughout school time in engineering at Tennessee Tech from making the game Shut the Box with logic gates to designing and building a coil gun. Almost certainly more skills and experiences will be required during this project and he is looking forward to getting started.

B. Timeline
1) Project Proposal: September 25th, 2022
2) Conceptual Design & Planning Final: October 30th, 2022
3) Detail Design Draft 1: November 10th, 2022
4) Detail Design Draft 2: November 24th, 2022
5) Design 1 Final: December 11th, 2022
a) Final Presentation for Design 1
6) Design 2 Draft: March 6th, 2023 (Estimate)
a) Prototype
b) Website Completion
7) Final Presentation: April TBD, 2023

Team 1 Timeline Gantt Chart:

REFERENCES
[1] The Kim Rutledge, Melissa McDaniel, Santani Teng, Hilary Hall, Tara Ramroop, Erin Sprout, Jeff Hunt, Diane Boudreau, Hilary Costa, National
Geographic, | “Air | Pollution”,
https://education.nationalgeographic.org/resource/air-pollution. (Accessed on 9-21-22).
[2] Air Quality Life Index, Constructive Inc, “Pollution Facts”, https://aqli.epic.uchicago.edu/pollution-facts/. (Accessed on 9-22-22).
[3] Minnesota Pollution Control Agency, “Air Quality and Health,” https://www.pca.state.mn.us/air-water-land-climate/air-quality-and-health. (Accessed on 9-21-22).
[4] AirNow, Home of the U.S. Air Quality Index, “Air Quality Index (AQI) Basics”, https://www.airnow.gov/aqi/aqi-basics/. (Accessed on 9-21-22).
[5] Minnesota Pollution Control Agency, “Understanding the Air Quality
Index | (AQI),” | https://www.pca.state.mn.us/air-water-land-
climate/understanding-the-air-quality-index-aqi. (Accessed on 9-20-22).
[6] Karen Howard, U.S. Government Accountability Office, “Science & Tech Spotlight: Air Quality Sensors,” https://www.gao.gov/products/gao-21-189sp. (Accessed on 9-19-22).
[7] Protronix, Healthy Air, “Operating Principles of Air Quality Sensors,” https://www.careforair.eu/en/on-what-principles-do-air-quality-sensors-work/. (Accessed on 9-20-22).
[8] Jillian Mackenzie, Jeff Turrentine, National Resources Defense Council,
“Air | Pollution: | Everything | You | Need | To | Know,”
https://www.nrdc.org/stories/air-pollution-everything-you-need-know. (Accessed on 9-21-22).
[9] Center for Disease Control and Prevention, National Center for
Environmental | Health, | “Air | Pollutants”,
https://www.cdc.gov/air/pollutants.htm. (Accessed on 9-30-22).
[10] IQAir, Clean Air Experience Center, “Air Quality in Nashville,” https://www.iqair.com/us/usa/tennessee/nashville. (Accessed on 9-30-22).
[11] Ellab Inc., Validation and Monitoring Solutions, | “Wireless
Environmental | Monitoring,”
https://www.ellab.com/solutions/monitoring-solutions/. (Accessed on 9-22-22).
[12] Airly Inc. “Air Quality Sensors,” https://airly.org/en/features/air-quality-sensors/. (Accessed on 9-21-22).
[13] Raspberry Pi Foundation, Computing and Digital Technology Education, “Raspberry Pi,” https://www.raspberrypi.com/. (Accessed on 9-23-22).
[14] Arduino, Empowering Digital Education and Businesses, “What is Arduino,” https://www.arduino.cc/en/Guide/Introduction. (Accessed on 9-23-22).

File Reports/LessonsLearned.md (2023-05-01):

# Lessons Learned

## Alejandro Moore

### Reflect on the project, both technical and organizational. What went well? What didn’t go well?
Overall, the team made an exceptional amount of progress for this project. In the beginning (CAPSTONE I), realizing the scope of this project took a little while but by the time it was finalized with both our customer and professor, we were ecstatic to start building this device. There are many things that did go well during that time. Our in person presentations at each checkpoint down the line mostly went well. Our Project Proposal, Conceptual Design, and Minimal Functionality Assignments were all passed as well. In a technical sense, when our team did meet in person, communication was strong and the vision for every assignment was the general consensus for all the members. During the whole course, there were some things that did not go well or even expected. Some of the documents that were due for each team member took a longer time than anticipated. With my own signoff analyzing the Sensor subsystem, it took me several weeks for it to meet the expectations of our customer/supervisor. Thus, leaving no other window of time before the final presentation to order the sensors that were essential to the project design. All in all, even though the sensors were not ordered, the project came out to meet most of the constraints stated at the beginning of the course.

### What unanticipated problems occurred?
I had enveloped an accumulation of issues while building the Air Quality device. As mentioned before, my signoff validation took me longer than I had expected. The reason for this is mostly because of my difficulty seeing the vision of what the customer wanted for this Sensor Signoff. Many subsections within the document were added later on and took time to research and summarize. 

### What would you do differently if you were to do it over again?
There are many things I would do differently if I had the opportunity for the class. First, I would communicate with the members of the team to understand the importance of meeting together outside of the scheduled meeting routine with our customer. This would make the time for every assignment due for the course be used more efficiently. Also, I would have spent a ton of more time doing more work for the signoff document that I was responsible for. I did not realize the amount of time to be allocated for this one document for it to be valid before purchase.

### What “best practices” have you identified?
The best practices I have noticed through this course would be to make sure everyone, including the professor and customer is on the same page. As a team, it is their own responsibility to communicate correctly and effectively in order to explain a concept that both the engineer and layman can understand. Not only meeting outside of regular meetings with the teacher and customer, but also keeping track of what work has been and is being done at that time will give the group a better analysis of the situation at hand.

### What words of wisdom would you pass on to future students?
It is important to know what type of people you are going to work with for this project. Since this project is an option to be on your own resume, it is also paramount that a high level of seriousness and motivation must be executed. Doing the best you can for your grade as well as the team’s grade is the best case scenario for this course.

### What new knowledge or skills did you acquire throughout capstone?
I have learned many things over the course of our CAPSTONE project. One thing I learned is if I do not know the specifics on what the customer would want for a subsystem of the project, it makes it more difficult to know what to build or even research. Understanding the functionality of the subsystem that’s assigned to a team member can help better realize what the building block of the project should look like. For me, I didn’t know there are classifications for sensors that detect gasses in its location. After researching the advantages and disadvantages of each type, I could figure out which one works best for the project accomplishments.

## Kaleb Irwin 

### Reflect on the project, both technical and organizational. What went well? What didn’t go well?
Technically this project did not meet all its goals. With this in mind I think the implementation and work done on what is complete is fairly good considering multiple subsystems were not designed and implemented until very late in the process. Obviously, our team struggled with deadlines and participation but the rally by some members to complete what we could and present a final interaction that wasn’t lacking a majority of critical features was one of the best moments of the project due to the feeling of completion and multiple parts coming together and working as intended. 

### What unanticipated problems occurred?
A number of unanticipated problems procured throughout the project. Technically, the biggest unanticipated problem was with getting the USB to initialize properly. We expected this to be implemented fairly quickly and it devolved into several long days of working through library code and changes until we could initialize and write to the USB. We also had major unexpected problems within the team. Group members were absent for large portions of the course and their work was not complete weeks after the due date. This was eventually dealt with by portions of the project being dropped and other aspects were picked up by the rest of the team. 

### What would you do differently if you were to do it over again?
I would absolutely be more forward with communication with the professor and supervisor about group conditions and would have been more proactive in doing the work of others when their work or lack thereof was detrimental to the team. I would also have been more proactive in my own work. While I turned a lot of my stuff in on time, I wasn't happy with the amount of work in the amount of time that I left myself with and in the future will definitely begin project oriented tasks well in advance.

### What “best practices” have you identified?
I found it best practice to pester for lack of a better word. Going to our supervisor and going through the documents with him and getting verbal feedback right there helped much more than the intermittent feedback given through GitHub. I also found it best practice to send meeting times in discord even when the meeting was organized in person because people tend to not show up. 

### What words of wisdom would you pass on to future students?
Words of wisdom I would pass on would be to make sure your group is working consistently and on time. Don’t be afraid to talk to the professor for help in any regard; whether it’s a technical question or about team dynamics. Don’t sit idle in this class, if you finish a section before it is due go ahead and start on the next part you never know if unexpected issues arise and take a week of effort to resolve.

### What new knowledge or skills did you acquire throughout capstone?
I acquired a lot of knowledge and skills around working on a project in a team environment. I saw both facets of teamwork from the extremely bad parts of group work where you feel like you are the only one doing work to the good parts where you're sitting next to your teammate figuring out complex topics and getting them to work. The biggest lesson learned from this was that no matter the group dynamic, or the effort they put in, the work is a reflection on you and you should put forth the effort that makes the work a good reflection on you. If this means doing the work of others, then do it and let the person in charge know that they aren't completing their work. In terms of knowledge gained, I learned a lot about expectations and processes in engineering design and what I need to show during it.

## Marvo Odds

### Reflect on the project, both technical and organizational. What went well? What didn’t go well? 
Communication and teamwork went poorly throughout the semester. 

### What unanticipated problems occurred? 
Lack of parts ordered impacted experimentation and gaps in communication between team members and supervisors. 

### What would you do differently if you were to do it over again? 
I would start the entire process of getting signed off during capstone 1 and heavily encourage my team members to do this as well. This process is the first major hurdle of capstone 2, but everything after this grade would be a smoother process. 

### What “best practices” have you identified? 
Scheduled meeting times outside of the weekly supervisor meetings is a must for success. Another best practice would be consistent daily group communication to ensure everyone knows deadlines and what they need to be doing. Checking on each group member and ensuring no one is struggling and needs.

### What words of wisdom would you pass on to future students?
Start everything whether it's a sign off, purchasing, experimentation, or prototyping as soon as possible instead of waiting because you don't have 100 % certainty that you will be signed off quickly or all your parts will come in on time. Account for scenarios and possibilities outside of your control. 

### What new knowledge or skills did you acquire throughout capstone?
At a basic level I learned the fundamental engineering process of taking an idea, making it real, and meticulously documenting every step and detail along the way. In doing this I learned better approaches for working in teams, technical writing, and how to research and parse useful information.

## Cameron Smith

### Reflect on the project, both technical and organizational. What went well? What didn’t go well? 
The project initially went fairly well.  Admittedly, from the start, a majority of the team preferred to do a bulk of the work in the last few days, but the team consistently banded together to complete the work.  That is the key point: when the team was together, acceptable work would get done very quickly.
A slow deterioration in team communication led to the team not meeting as often which is when most of the work would be done.  This was one of the biggest downfalls of the team.  The team failed to implement many of the features that were meant to be included in the final design.  Ordering issues also contributed to the project leading to many compromises being a necessity in what the project could achieve.  
With what we had, we definitely gave it a very good effort and got many of the core features implemented.

### What unanticipated problems occurred? 
The technical problems that we faced were numerous.  We had estimated to have full USB functionality within two days.  This ended up taking two weeks due to a faulty component being received and then having to adjust the USB library to be used to data storage.  The ESP order was delayed by six weeks because I.T. needed to approve the device for use on campus.  Connecting the ESP to the Arduino was very straightforward, however, understanding the nuances of how the Arduino IDE treats Serial took way longer than expected.  There were many things hidden from us inside the IDE.
With the website being entirely halted because of difficulties in coding, we had to do a complete shift in direction towards a more simple solution.  We had to find a way to get the ESP to reliably connect to a Google Script which would then accept data and push data to a Google Sheet for display.  This took an incredible amount of time as it felt like we were trying to get many, many different things to work together peacefully when they really didn't want to.
As for problems in teamwork, it is simple to say that the team did not work together anywhere near the efficiency of Capstone I.

### What would you do differently if you were to do it over again? 
I would be much more demanding.  I would disregard compassion more often to procure results.  I would have began updating the professor on team status from week 1.  I would sit down with my team members one by one and get progress updates.  I would set more definitive milestones for my team from the beginning.  I would not hesitate to confront my team's lack of progress that bothered me.  

### What “best practices” have you identified?
Setting up more strict communication amongst the team.  Setting realistic milestones from team members.  Require team members for progress updates.  Organization and structure improvements to be consistent.  Be less lenient on members missing meetings.  Be completely transparent with your superiors.  

### What words of wisdom would you pass on to future students?
Take everything in this class completely serious.  That includes deadlines, team contract, absences, and lack of work.
You are not a bad person for "ratting" to the professor.  You are helping the team in the long run.  Don't be afraid to address problems with your superiors.  Your team may not do their work.  You may have to do it.  You make sure to tell your superior that you did it not the other person.

### What new knowledge or skills did you acquire throughout capstone?
Lots of knowledge for how a team should not function and consequently how to avoid some bad team behaviors.  There has been a great deal of teamwork skills acquired in the form of leadership, organization, and communication.  
General coding practice and coding knowledge regarding the topics covered in the project.

## Joshua Egwuatu

### Reflect on the project, both technical and organizational. What went well? What didn’t go well? 
Overall, this project was a great learning experience. We were able to produce a semi-working project. With all issues we ran into, the outcome is something I think we can be proud of. The planning stage for the project went relatively well, but the execution during the second half took a nose dive. Communication may have been the biggest factor in the group's lack of success. I think all group members have learned this.

### What unanticipated problems occurred? 
Deadlines! As a team, we had a rough time meeting deadlines on time. We should’ve put more emphasis on working through signoffs during the first semester/winter break. This started to lead to delays in all other aspects of the project. We also ran into major ordering delays, some of this was due to subsystems not being completed on time. At other times, parts didn’t work when ordered initially. 

### What would you do differently if you were to do it over again? 
Set meeting times throughout the week to work on Capstone as a group. Even though some of the work can be done on your own, this is the best way to make sure everyone is equally contributing to the group. Something I’d do personally differently is ask for help. My understanding of my subsystem went over my head, asking for help doesn’t need to be looked at as weak or unintelligent. Capstone is supposed to be difficult!

### What “best practices” have you identified?
Keep each other accountable! Accountability is key to success in a project. Time management is essential. Plan your time appropriately. Communicate with your supervisor and communicate with your team members. Always make sure everyone is on the exact same page.

### What words of wisdom would you pass on to future students?
It’s never too early to get something done. Waiting till the last minute is something we college students tend to do a lot. Treat capstone like a job, you need to put in a certain amount of hours every week in order to succeed. It is okay to ask for help! If you don’t understand something, it is okay to lean on your team members. Even though capstone tests your skills on what you’ve done in your college career, it doesn’t mean everything you do has to be a solo job. When issues arise, make sure to take care of these issues as a team!

### What new knowledge or skills did you acquire throughout the capstone?
I learned that without a proper structure for team members to adhere to for a project, your project may fail. Teamwork is an integral part of succeeding in the workforce, and there are no exceptions. Knowledge of creating schematics and 3D Models has been improved.

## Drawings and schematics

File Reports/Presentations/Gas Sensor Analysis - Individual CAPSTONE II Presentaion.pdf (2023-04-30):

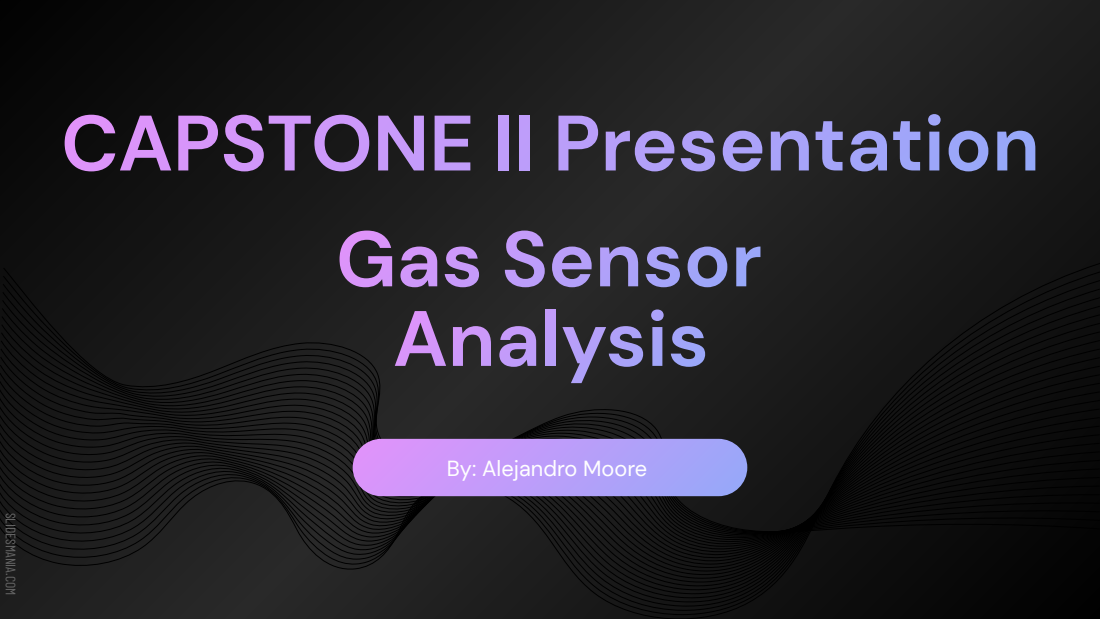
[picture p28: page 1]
SLIDESMANIA.COM

By: Alejandro Moore

# What’s the purpose?

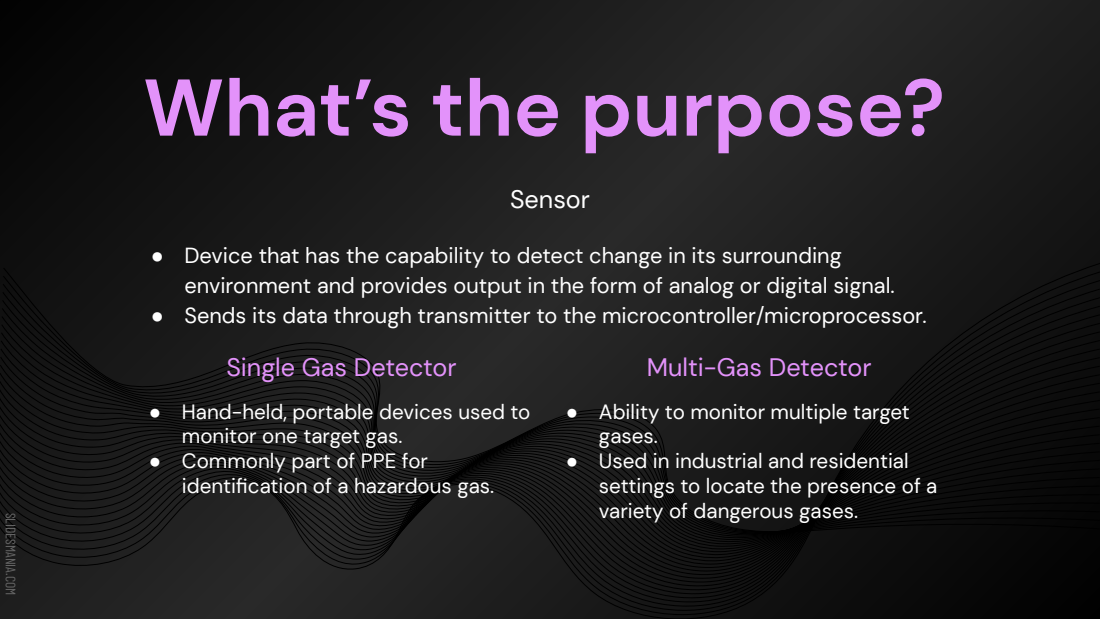
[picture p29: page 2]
SLIDESMANIA.COM; Sensor

● Device that has the capability to detect change in its surrounding
environment and provides output in the form of analog or digital signal.
● Sends its data through transmitter to the microcontroller/microprocessor.

Single Gas Detector | | Multi-Gas Detector

● Hand-held, portable devices used to monitor one target gas. ● Commonly part of PPE for identification of a hazardous gas. | ● Ability to monitor multiple target gases. ● Used in industrial and residential settings to locate the presence of a variety of dangerous gases.

# Did you know?

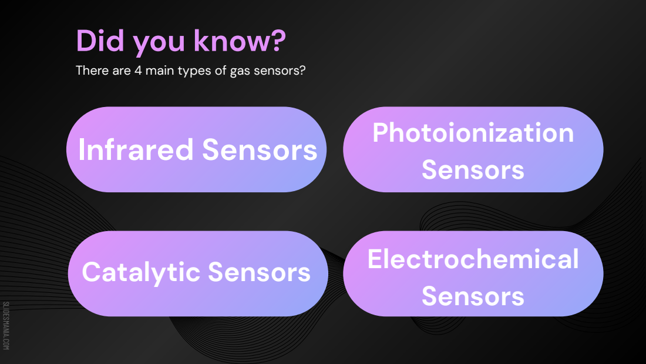
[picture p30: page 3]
SLIDESMANIA.COM; Photoionization Sensors; Catalytic Sensors; Electrochemical; Sensors

There are 4 main types of gas sensors?
Infrared Sensors

# We will talk about

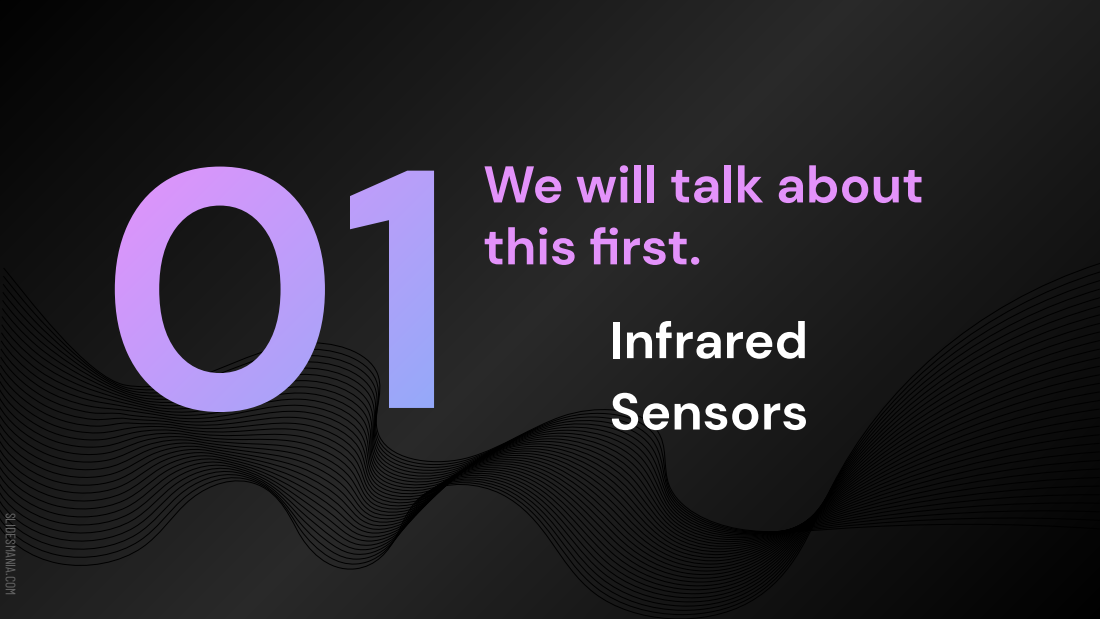
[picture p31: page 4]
SLIDESMANIA.COM; Infrared Sensors; this first.

SLIDESMANIA.COM

# Infrared Sensors

- a method for detecting combustible hydrocarbon gas with infrared light.
- Used when there is no oxygen present, or in situations where you measure high carbon dioxide concentrations.
- Infrared source illuminates a volume of gas that has entered inside the measurement chamber.
- Gas absorbs some of the infrared wavelengths as the light passes through it, while others pass through it completely unattenuated.
- A change in the intensity of the absorbed light is measured relative to the intensity of light at a non-absorbed wavelength.
- Infrared gas detection devices may be classified as open path detection or point detection.

# Pros & Cons

Advantages | Disadvantages

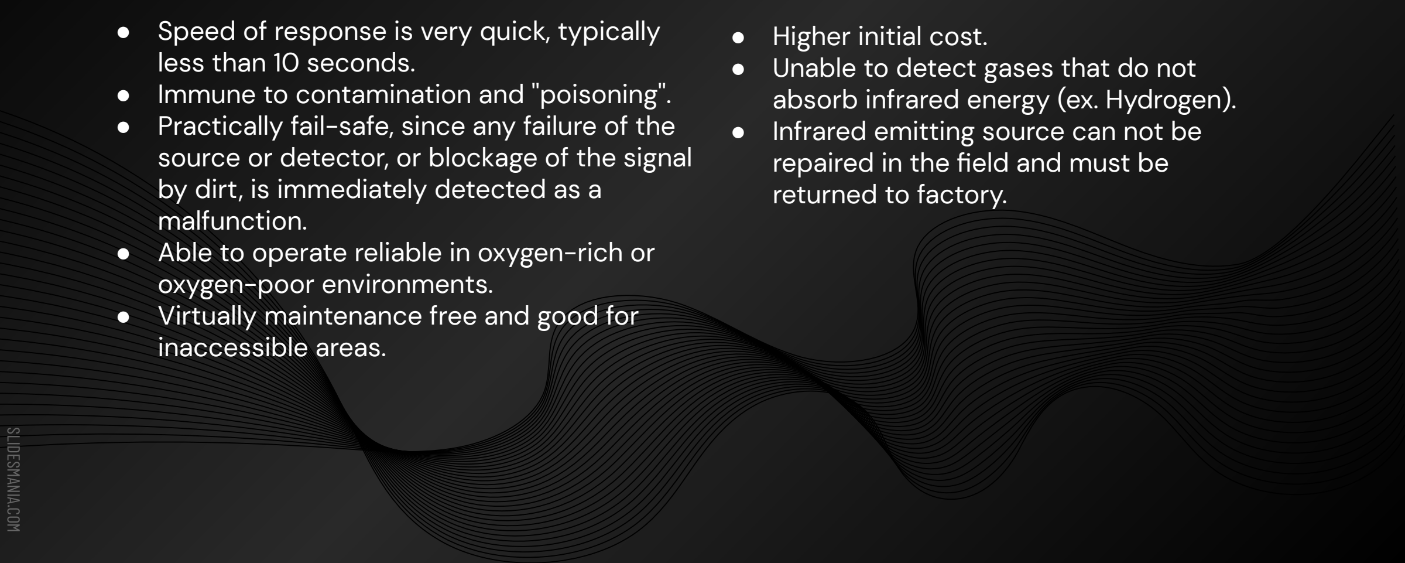
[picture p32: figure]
SLIDESMANIA.COM; less than 10 seconds.; by dirt, is immediately detected as a malfunction.; oxygen-poor environments.; inaccessible areas.; ● Higher initial cost. ● Unable to detect gases that do not absorb infrared energy (ex. Hydrogen). ● Infrared emitting source can not be repaired in the field and must be returned to factory.

- Speed of response is very quick, typically
- Immune to contamination and ''poisoning''.
- Practically fail-safe, since any failure of the source or detector, or blockage of the signal
- Able to operate reliable in oxygen-rich or
- Virtually maintenance free and good for

# We will talk about

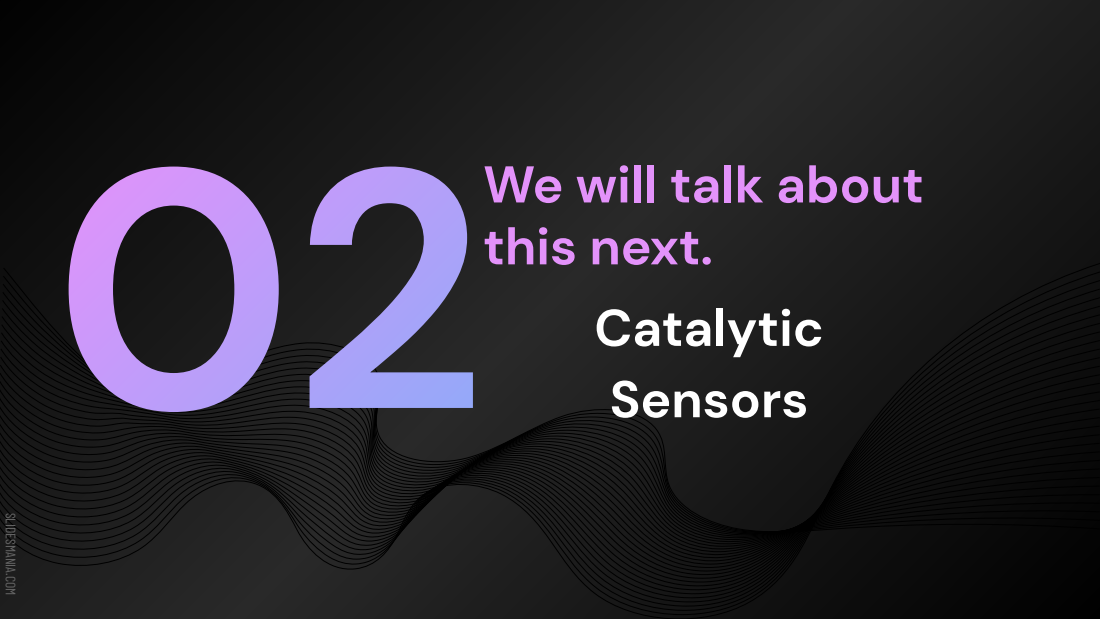
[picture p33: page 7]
SLIDESMANIA.COM; Catalytic Sensors; this next.

SLIDESMANIA.COM

# Catalytic Sensors

- Typically used to measure combustible gases that come with an explosion hazard when concentrations are between the lower explosion limit (LEL) and the upper explosion limit (UEL).
- 2 basic elements: a detector which contains a catalytic material sensitive to flammable gases, and a compensator element which is inert.
- Combustible gases will burn in the presence of oxygen only on the detector, causing a rise in temperature and a corresponding rise in electrical resistance, and the sensor will convert the temperature change via a Wheatstone bridge-type circuit.
- When combustible gases raise the temperature of the detector and a rise in its resistance, it causes an imbalance in the circuit and produces an output voltage signal.

# Pros & Cons

Advantages | Disadvantages

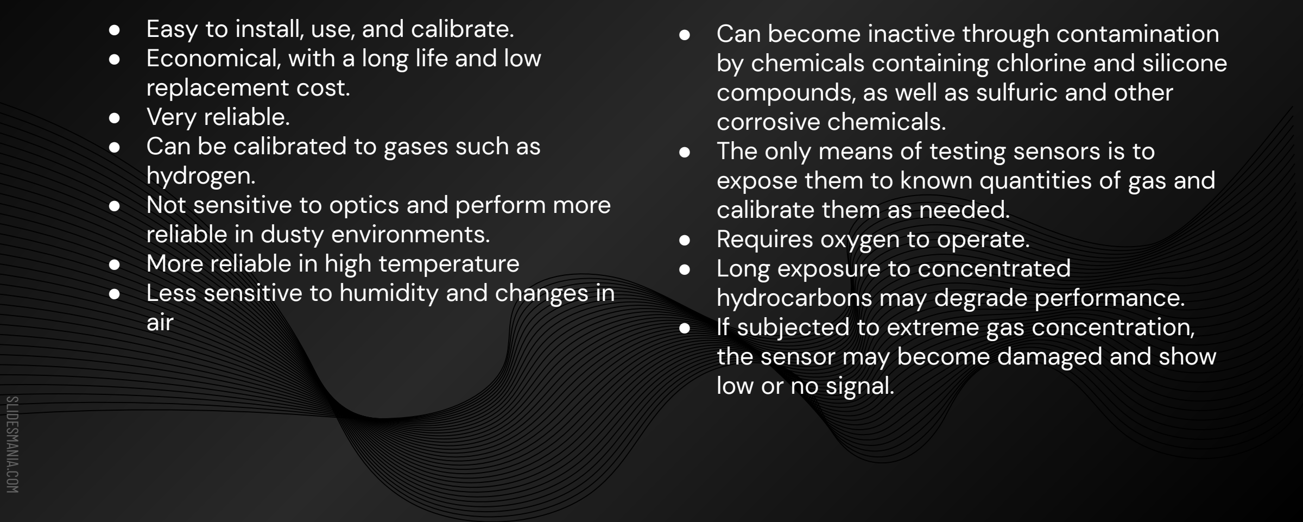
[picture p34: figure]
SLIDESMANIA.COM; ● Easy to install, use, and calibrate. ● Economical, with a long life and low replacement cost. ● Very reliable. ● Can be calibrated to gases such as hydrogen.; reliable in dusty environments. ● More reliable in high temperature; air; corrosive chemicals.; calibrate them as needed. ● Requires oxygen to operate. ● Long exposure to concentrated hydrocarbons may degrade performance.; the sensor may become damaged and show low or no signal.

- Not sensitive to optics and perform more
- Less sensitive to humidity and changes in
- Can become inactive through contamination by chemicals containing chlorine and silicone compounds, as well as sulfuric and other
- The only means of testing sensors is to expose them to known quantities of gas and
- If subjected to extreme gas concentration,
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

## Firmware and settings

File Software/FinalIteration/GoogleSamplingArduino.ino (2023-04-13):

#include <SPI.h>
#include <UsbFat.h>
#include <masstorage.h>
#include "Wire.h"

//Prototypes
void fileApp(String buf, File f);

// USB host objects.
USB usb;
BulkOnly bulk(&usb);

// File system.
UsbFat key(&bulk);

// File object to open/close/write to
File file;

const int MPU_ADDR = 0x68;                                   // I2C address of the MPU-6050. If AD0 pin is set to HIGH, the I2C address will be 0x69.
int16_t accelerometer_x, accelerometer_y, accelerometer_z;    // variables for accelerometer raw data
int16_t gyro_x, gyro_y, gyro_z;                              // variables for gyro raw data
int16_t temperature;                                         // variables for temperature data
String accelerometer_xS, accelerometer_yS, accelerometer_zS; // variables for accelerometer raw data
String gyro_xS, gyro_yS, gyro_zS;                            // variables for gyro raw data
String temperatureS;                                         // variables for temperature data
String data1,data2,check = "";                               // variables to send to Serial 0 and 1
bool usb_status = 0;                                         // USB status is on or off

char tmp_str[7]; // temporary variable used in convert function
// converts int16 to string. Moreover, resulting strings will have the same length in the debug monitor.
char* convert_int16_to_str(int16_t i) {
  sprintf(tmp_str, "%6d", i);
  return tmp_str;
}

void setup() 
{
  // Setup USB
  Serial.begin(9600);
  delay(1000);
  Serial1.begin(9600);
  delay(1000);

  while(Serial.available()){
    Serial.read();
  }

  Serial.print("\n\rFreeRam ");
  Serial.println(FreeRam());
  int usb_fail_count = 0;

  // Initialize the USB bus.
  while(!usb_status && (usb_fail_count < 6))
  {
    usb_status = initUSB(&usb);
    if(usb_status == 0)
    {
      Serial.println("initUSB Failed");
      delay(50);
      usb_fail_count++;
    }    
  }
  
  // Init the USB key or USB hard drive.
  if(usb_status)
  {
    if (!key.begin()) {
      Serial.println(F("key.begin failed"));
      return;
    }

    Serial.print(F("\r\nVolume Size: "));
    // Avoid 32-bit overflow for large volumes.
    Serial.print((key.volumeBlockCount()/1000)*512/1000);
    Serial.println(F(" MB"));
  
    // Print a line to a test file.
    file.open("Data.txt", O_CREAT | O_RDWR | O_APPEND);
    file.println("|  Accel X  ||  Accel Y  ||  Accel Z  ||   Temp   ||  Gyro X  ||  Gyro  Y  ||  Gyro  Z  ||  Distance  |");
    file.close();
  
    // List the files in the root directory.
    Serial.println();
    key.ls(LS_A | LS_DATE | LS_SIZE);
    Serial.println();
    Serial.println(F("Done"));
  }

  //Setup I2C
  Wire.begin();
  Wire.beginTransmission(MPU_ADDR); // Begins a transmission to the I2C slave (GY-521 board)
  Wire.write(0x6B); // PWR_MGMT_1 register
  Wire.write(0); // set to zero (wakes up the MPU-6050)
  Wire.endTransmission(true);

  //Wait for data from Serial1
  while(!Serial1.available()){}
 
  //Make sure ESP is connected to Internet and Google Sheets
  while(check != "Connected\r")
  {
    delay(5);
    check = Serial1.readStringUntil('\n');
    Serial.println(check);
  }
  Serial.println("Connected to Google Sheets");
  check = "Success";
}

//Appends data to a USB flash drive file
void fileApp(String buf, File f)
{
  f.open("Data.txt", O_WRITE | O_APPEND);
  
  //f.print(F("\r"));
  f.print(F("\n"));                               //Space out data option
  //f.print(F(","));                              //Optional comma to separate before
  for(int i = 0; i < buf.length(); i++)
  {
    f.print(buf[i]);                              //Print buffer to file character by character
  }
  //f.print(F(","));                              //Optional comma as a delimeter after
  f.println();
  f.close();
}

void loop() 
{
  if(check == "Success")  //Only take a sample when ESP is ready
  {
    //Variables for sampling
    check = "";                                                                    
    float volts = 0.0;
    float cm = 0.0;
    int Voltsadc=analogRead(A0);
    volts = Voltsadc*5.0/1023.0;
    cm = 25.826*pow(volts,-1.1);
    String result = (String)cm;
   
    Wire.beginTransmission(MPU_ADDR);
    Wire.write(0x3B); // starting with register 0x3B (ACCEL_XOUT_H) [MPU-6000 and MPU-6050 Register Map and Descriptions Revision 4.2, p.40]
    Wire.endTransmission(false); // the parameter indicates that the Arduino will send a restart. As a result, the connection is kept active.
    Wire.requestFrom(MPU_ADDR, 7*2, true); // request a total of 7*2=14 registers
  
    // "Wire.read()<<8 | Wire.read();" means two registers are read and stored in the same variable
    accelerometer_x = Wire.read()<<8 | Wire.read(); // reading registers: 0x3B (ACCEL_XOUT_H) and 0x3C (ACCEL_XOUT_L)
    accelerometer_y = Wire.read()<<8 | Wire.read(); // reading registers: 0x3D (ACCEL_YOUT_H) and 0x3E (ACCEL_YOUT_L)
    accelerometer_z = Wire.read()<<8 | Wire.read(); // reading registers: 0x3F (ACCEL_ZOUT_H) and 0x40 (ACCEL_ZOUT_L)
    temperature = Wire.read()<<8 | Wire.read(); // reading registers: 0x41 (TEMP_OUT_H) and 0x42 (TEMP_OUT_L)
    gyro_x = Wire.read()<<8 | Wire.read(); // reading registers: 0x43 (GYRO_XOUT_H) and 0x44 (GYRO_XOUT_L)
    gyro_y = Wire.read()<<8 | Wire.read(); // reading registers: 0x45 (GYRO_YOUT_H) and 0x46 (GYRO_YOUT_L)
    gyro_z = Wire.read()<<8 | Wire.read(); // reading registers: 0x47 (GYRO_ZOUT_H) and 0x48 (GYRO_ZOUT_L)

    //Convert variables to String
    accelerometer_xS = (convert_int16_to_str(accelerometer_x));
    accelerometer_yS = (convert_int16_to_str(accelerometer_y));
    accelerometer_zS = (convert_int16_to_str(accelerometer_z));
    temperatureS = (convert_int16_to_str(temperature/340.00+36.53));
    gyro_xS = (convert_int16_to_str(gyro_x));
    gyro_yS = (convert_int16_to_str(gyro_y));
    gyro_zS =  (convert_int16_to_str(gyro_z));

    //Format data for flash drive
    data1=("aX = ")+accelerometer_xS+(" aY = ")+accelerometer_yS+(" aZ = ")+accelerometer_zS+(" tmp = ")+temperatureS+(" gX = ")+gyro_xS+(" gY = ")+gyro_yS+(" gZ = ")+gyro_zS+(" Distance = ")+result+('\n');

    //Format data for Google Sheets JSON
    accelerometer_xS.trim();
    accelerometer_yS.trim();
    accelerometer_zS.trim();
    temperatureS.trim();
    gyro_xS.trim();
    gyro_yS.trim();
    gyro_zS.trim();
    data2 = "\"" + accelerometer_xS+(",")+accelerometer_yS+(",")+accelerometer_zS+(",")+temperatureS+(",")+gyro_xS+(",")+gyro_yS+(",")+gyro_zS+(",")+result+ "\"}" + ('\n');  
      
    Serial.print(data2);                //Send data to Terminal
    if(usb_status)
    {
      fileApp(data1, file);               //Write data to flash drive
    }
    delay(10);
    Serial1.print(data2);               //Send data to ESP
    delay(5000);                        //Need to wait for Google Sheets
    
    while(!Serial1.available()){}       //Wait for ESP to send something
    
    while(check != "Success")           //Read until ESP sends confirmation
    {
      delay(5);
      check = Serial1.readStringUntil('\n');
      check.trim();
    }
    check = "Success";                  //Make sure check is written as the loop expects
  }
}

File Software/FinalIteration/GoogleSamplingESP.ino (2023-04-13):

// Example Arduino/ESP8266 code to upload data to Google Sheets
// Follow setup instructions found here:
// https://github.com/StorageB/Google-Sheets-Logging
// reddit: u/StorageB107
// email: StorageUnitB@gmail.com
// Modified by TNTECH ECE Capstone Team 1 2022-2023

#include <Arduino.h>
#include <ESP8266WiFi.h>
#include "HTTPSRedirect.h"

// Enter network credentials:
const char* ssid     = "NETWORK-NAME-HERE"; //network ID
const char* password = "NETWORK-PASSWORD-HERE"; //Password 

// Enter Google Script Deployment ID:
const char *GScriptId = "GOOGLE-SCRIPT-ID-HERE";

// Enter command (insert_row or append_row) and your Google Sheets sheet name (default is Sheet1):
String payload_base =  "{\"command\": \"insert_row\", \"sheet_name\": \"Sheet1\", \"values\": ";
String payload = "";

// Google Sheets setup (do not edit)
const char* host = "script.google.com";
const int httpsPort = 443;
const char* fingerprint = "";
String url = String("/macros/s/") + GScriptId + "/exec";
HTTPSRedirect* client = nullptr;

String data = ""; //variable that will be published to Google Sheets
void setup() 
{
  Serial.begin(9600);        
  delay(3000);

  //Connect to WiFI
  WiFi.begin(ssid, password);       
  while (WiFi.status() != WL_CONNECTED) {
    delay(1000);
  }
  
  // Use HTTPSRedirect class to create a new TLS connection
  client = new HTTPSRedirect(httpsPort);
  client->setInsecure();
  client->setPrintResponseBody(true);
  client->setContentTypeHeader("application/json");
  
  // Try to connect for a maximum of 5 times
  bool flag = false;
  for (int i=0; i<5; i++){ 
    int retval = client->connect(host, httpsPort);
    if (retval == 1){
       flag = true;
       Serial.println(); //added to avoid anything put in serial on startup
       Serial.println("Connected");
       break;
    }
  }
  delay(50);
  delete client;    // delete HTTPSRedirect object
  client = nullptr; // delete HTTPSRedirect object
}

void loop() 
{
  if(Serial.available())
  {
    static bool flag = false;
    if (!flag){
      client = new HTTPSRedirect(httpsPort);
      client->setInsecure();
      flag = true;
      client->setPrintResponseBody(true);
      client->setContentTypeHeader("application/json");
    }
    if (client != nullptr){
      if (!client->connected()){
        client->connect(host, httpsPort);
      }
    }
  
    // Create json object string to send to Google Sheets
    data = Serial.readStringUntil('\n'); //read from ardunio 
    payload = payload_base + data;
  
    // Publish data to Google Sheets
    if(client->POST(url, host, payload)){ 
      // do stuff here if publish was successful
    }
    else{
      // do stuff here if publish was not successful
    }
  
    // a delay of several seconds is required before publishing again  
    while(Serial.available()){
      Serial.read();
    }
  }
}

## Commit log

2022-11-22 Create AlejandroMoore-Signoff-SensorSubsystem
2023-03-31 Add files via upload
    Interrupt testing for sampling on timer interrupt
2023-04-10 Create Web and Wireless Experimentation
2023-04-10 Rename Web and Wireless Experimentation to Web and Wireless Experimentation.md
